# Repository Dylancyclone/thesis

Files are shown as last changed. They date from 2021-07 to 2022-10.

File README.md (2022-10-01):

# Building a Mobile Device that Leverages the Power of a Desktop Computer

## ASU Barrett Undergraduate Thesis 2022

## [READ THE PAPER HERE](./paper/small.pdf)

(Alternatively, [see it on asu.edu](https://keep.lib.asu.edu/items/165594))

Watch a timelapse of the paper here: https://youtu.be/VJ2HCxnmA_Y

## Abstract

With the recent focus of attention towards remote work and mobile computing, the possibility of taking a powerful workstation wherever needed is enticing.
However, even emerging laptops today struggle to compete with desktops in terms of cost, maintenance, and future upgrades.
The price point of a powerful laptop is considerably higher compared to an equally powerful desktop computer, and most laptops are manufactured in a way that makes upgrading parts of the machine difficult or impossible, forcing a complete purchase in the event of failure or a component needing an upgrade.

In the case where someone already owns a desktop computer and must be mobile, instead of needing to purchase a second device at full price, it may be possible to develop a low-cost computer that has just enough power to connect to the existing desktop and run all processing there, using the mobile device only as a user interface.

This thesis will explore the development of a custom PCB that utilizes a Raspberry Pi Computer Module 4, as well as the development of a fork of the Open Source project Moonlight to stream a host machine's screen to a remote client.
This implementation will be compared against other existing remote desktop solutions to analyze it's performance and quality.

## Information

This repository contains all the files and resources used to produce my Honors Thesis.

Folders are self-explanatory.

Final PCB board

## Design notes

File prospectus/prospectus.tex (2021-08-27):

\documentclass[11pt]{article}

%%%%% Preamble

\usepackage[margin=1in]{geometry} % Margin size
\usepackage{supertabular}
\usepackage[export]{adjustbox}

%% Title Information.

\title{Thesis Prospectus}
\author{Dylan Lathrum}
%\date{Jan 1 2000} % By default, LaTeX uses the current date
\date{} % Don't display date

%%%%% The Document

\begin{document}

\maketitle

\section*{Topic Overview}

Personal computers have greatly evolved and specialized over the past few decades to the point where the word ``computer" now refers to a whole family of devices that can be tailored to any particular use case.
A computer can be built to specifically fill a need or role ranging from the portability of a laptop to the raw power of a desktop.
For the longest time these roles have been completely seperate from one another, though in the past couple of years these two classes of computers have begun to share traits with each other.
While a desktop computer has been the standard for intensive computing and work since the beginning of computers, technology has progressed to the point where a laptop can provide comparable power in a much smaller footprint.
With the recent shift in attention towards remote work and mobile computing, the prospect of taking a workstation wherever needed is incredibly promising.
Though even the emerging laptops today struggle to compete with desktops in terms of cost, maintenance, and future upgrades.
The cost barrier to entry for powerful laptops is considerably higher compared to desktop computers, and most laptops are manufactured in a way that makes upgrading parts of the machine difficult or impossible, forcing a complete purchase in the event of failure or a component needs to be upgraded.

However, in the case where someone already owns a desktop computer and needs to be mobile, instead of needing to purchase a second device at full price, it may be possible to develop a low-cost computer that has just enough power to connect to the existing desktop and run all processing there, using the mobile device only as a user interface.
While the idea of a thin-client is not new, it's current usage in the real world has mostly been limited to computing clusters and server terminals due to their dependence on stable internet connections.
With the advent of small consumer electronics such as Raspberry Pis and their improvements in networking capabilities, the idea of a remote desktop has become a real possibility.

\section*{Research Plan}

I will begin my research by investigating the minimum cost barrier to create a computer using quality parts that can be used like a regular consumer product that has enough power to connect with a desktop computer at speeds sufficient for intense computing.
Once I can build a proof-of-concept using consumer parts, I will begin researching and developing a custom Printed Circuit Board (PCB) that will produce the same hardware output as a single board computer at a small footprint.
I believe creating a custom PCB will have benefits over a "DIY" solution as it will help prove the final product as something that could be used as a professional day-to-day replacement for a conventional powerful laptop.
Once parts have been selected and ordered, I will begin developing the hardware enclosure, wiring plans, and the software required to make the computer functional.
Throughout development, I will be benchmarking my product against existing technologies that support remote usage of computers, such as remote desktops.
I plan to investigate the specific technical specifications of the remote connection between my device and the host computer such as the latency, responsiveness, and image quality.
These statistics can be benchmarked by attempting to run intensive programs remotely, such as training an AI model, compiling code, running CAD software, rendering images/video, or developing video game software.
Due to the lack of existing all-in-one device for this purpose, I will research the advantages such a device has over comparable alternatives.
Once development has concluded, I will use the data collected to synthesize a comprehensive overview of the produced device and analyze its benefits over purchasing a high-powered laptop or using current alternatives.

\section*{Meetings}

I will meet with my thesis director on a regular basis every other week to discuss progress on the project and to answer any questions that arise from either party.
I will also meet with my other committee members to discuss my progress and ask for their advice and expertise.
Other meetings may be scheduled should new information or urgent questions arise.

\section*{Timeline}

\begin{tabular}{r|p{0.8\linewidth}}
	Date       & Task                                                                                 \\
	\hline
	June       & Begin research into hardware and software to be used in the project                  \\
	July       & Order parts and begin researching and designing enclosure for parts                  \\
	August 11  & Begin regular meetings with director, review schedule                                \\
	August     & Begin creating hardware and software for project                                     \\
	December   & Create final prototype for the project                                               \\
	January 10 & Start working on thesis paper, continue research and development on physical project \\
	Feburary   & Complete rough draft of thesis paper                                                 \\
	March      & Thesis Defense                                                                       \\
	April 15   & Submit Thesis                                                                        \\
\end{tabular}

\end{document}

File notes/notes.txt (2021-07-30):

USB C Breakout
https://www.sparkfun.com/products/15100

DSI vs HDMI
DSI Has extremely limited support (1 screen outside of the official implementation, locked at 800x480) and the format is closed so its hard for new ones to be made. DSI is more power efficient, and built in touch support, but lower resolution (480p). HDMI is a more generic standard, but small screens are expensive.
https://raspberrypi.stackexchange.com/questions/88075/hdmi-vs-dsi-pros-and-cons

Probably don't need an RTC for the pi if it syncs upon startup. Might also need a kernal patch that is built for rasbian that would have to be rewritten for arch
https://www.raspberrypi.org/forums/viewtopic.php?t=293632

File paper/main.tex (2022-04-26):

%%%%%%%%%%%%%%%%%%%%%%%%%%%%%%%%%%%%%%%%%
% Undergraduate Thesis for Barrett, The Honors College at Arizona State University
% For the degree of Software Engineering
% By Dylan Lathrum
%
% This document is based on a template by:
% Vel (vel@latextemplates.com)
% Steve Gunn (http://users.ecs.soton.ac.uk/srg/softwaretools/document/templates/)
% Sunil Patel (http://www.sunilpatel.co.uk/thesis-template/)
%
% Under the license:
% CC BY-NC-SA 3.0 (http://creativecommons.org/licenses/by-nc-sa/3.0/)
%
%%%%%%%%%%%%%%%%%%%%%%%%%%%%%%%%%%%%%%%%%

%----------------------------------------------------------------------------------------
%	PACKAGES AND OTHER DOCUMENT CONFIGURATIONS
%----------------------------------------------------------------------------------------
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
  commentstyle=\itshape\color{green!40!black},
  % identifierstyle=\color{blue},
  stringstyle=\color{orange},
}
\lstdefinestyle{customc}{
  language=C,
	morekeywords={uint32_t},
  belowcaptionskip=1\baselineskip,
  breaklines=true,
  frame=single,
  % xleftmargin=\parindent,
	numbers=left,
  showstringspaces=false,
  basicstyle=\footnotesize\ttfamily,
  keywordstyle=\bfseries\color{blue!80!black},
  commentstyle=\itshape\color{green!40!black},
  % identifierstyle=\color{blue},
  stringstyle=\color{orange},
}
\lstdefinestyle{plaintext}{
  belowcaptionskip=1\baselineskip,
  breaklines=true,
  frame=single,
	numbers=none,
  showstringspaces=false,
  basicstyle=\footnotesize\ttfamily,
}
\lstset{escapechar=@,style=customc}

\usepackage{pgfplots} % Required for the plots
\usepgfplotslibrary{statistics}
\pgfplotsset{compat=1.8}
% Fix mod function bug
% borrowed from <https://tex.stackexchange.com/a/145967/95441>
\pgfmathdeclarefunction{fpumod}{2}{%
		\pgfmathfloatdivide{#1}{#2}%
		\pgfmathfloatint{\pgfmathresult}%
		\pgfmathfloatmultiply{\pgfmathresult}{#2}%
		\pgfmathfloatsubtract{#1}{\pgfmathresult}%
		% replaced `0' by `5' to make it work for this problem
		\pgfmathfloatifapproxequalrel{\pgfmathresult}{#2}{\def\pgfmathresult{5}}{}%
}

\usepackage{chronosys} % Required for timelines

%----------------------------------------------------------------------------------------
%	MARGIN SETTINGS
%----------------------------------------------------------------------------------------

\geometry{
	paper=a4paper, % Change to letterpaper for US letter
	inner=2.5cm, % Inner margin
	outer=3.8cm, % Outer margin
	bindingoffset=.5cm, % Binding offset
	top=1.5cm, % Top margin
	bottom=1.5cm, % Bottom margin
	%showframe, % Uncomment to show how the type block is set on the page
}

%----------------------------------------------------------------------------------------
%	THESIS INFORMATION
%----------------------------------------------------------------------------------------

\thesistitle{Building a Mobile Device that Leverages the Power of a Desktop Computer} % Your thesis title, this is used in the title and abstract, print it elsewhere with \ttitle
\supervisor{Dr. Robert \textsc{Heinrichs}} % Your supervisor's name, this is used in the title page, print it elsewhere with \supname
\examiner{} % Your examiner's name, this is not currently used anywhere in the template, print it elsewhere with \examname
\degree{Software Engineering} % Your degree name, this is used in the title page and abstract, print it elsewhere with \degreename
\author{Dylan \textsc{Lathrum}} % Your name, this is used in the title page and abstract, print it elsewhere with \authorname
\addresses{} % Your address, this is not currently used anywhere in the template, print it elsewhere with \addressname

\subject{Software Engineering} % Your subject area, this is not currently used anywhere in the template, print it elsewhere with \subjectname
\keywords{} % Keywords for your thesis, this is not currently used anywhere in the template, print it elsewhere with \keywordnames
\university{\href{https://www.asu.edu/}{Arizona State University}} % Your university's name and URL, this is used in the title page and abstract, print it elsewhere with \univname
\department{\href{https://barretthonors.asu.edu/}{Barrett, The Honors College}} % Your department's name and URL, this is used in the title page and abstract, print it elsewhere with \deptname
% \group{} % Your research group's name and URL, this is used in the title page, print it elsewhere with \groupname
% \faculty{\href{http://faculty.university.com}{Faculty Name}} % Your faculty's name and URL, this is used in the title page and abstract, print it elsewhere with \facname

\AtBeginDocument{
\hypersetup{pdftitle=\ttitle} % Set the PDF's title to your title
\hypersetup{pdfauthor=\authorname} % Set the PDF's author to your name
\hypersetup{pdfkeywords=\keywordnames} % Set the PDF's keywords to your keywords
}

\begin{document}

\frontmatter % Use roman page numbering style (i, ii, iii, iv...) for the pre-content pages

\pagestyle{plain} % Default to the plain heading style until the thesis style is called for the body content

%----------------------------------------------------------------------------------------
%	TITLE PAGE
%----------------------------------------------------------------------------------------

\begin{titlepage}
	\begin{center}

		\vspace*{.06\textheight}
		{\scshape\LARGE \univname\par}\vspace{1.5cm} % University name
		\textsc{\Large Honors Thesis}\\[0.5cm] % Thesis type

		\HRule \\[0.4cm] % Horizontal line
		{\huge \bfseries \ttitle\par}\vspace{0.4cm} % Thesis title
		\HRule \\[1.5cm] % Horizontal line

		\begin{minipage}[t]{0.4\textwidth}
			\begin{flushleft} \large
				\emph{Author:}\\
				\href{https://www.linkedin.com/in/dylanlathrum/}{\authorname} % Author name - remove the \href bracket to remove the link
			\end{flushleft}
		\end{minipage}
		\begin{minipage}[t]{0.4\textwidth}
			\begin{flushright} \large
				\emph{Director:} \\
				\href{https://isearch.asu.edu/profile/3180015}{\supname} % Supervisor name - remove the \href bracket to remove the link  
			\end{flushright}
		\end{minipage}\\[.5cm]

		\begin{minipage}[t]{0.8\textwidth}
			\begin{flushright} \large
				\emph{Second Reader:}\\
				\href{https://isearch.asu.edu/profile/1232839/}{Ruben Acu\~{n}a}
			\end{flushright}
		\end{minipage}\\[.5cm]
		\begin{minipage}[t]{0.8\textwidth}
			\begin{flushright} \large
				\emph{Third Reader:} \\
				\href{https://isearch.asu.edu/profile/1625795}{Dr. Shawn Jordan}
			\end{flushright}
		\end{minipage}\\[3cm]

		\vfill

		\large \textit{A thesis submitted in fulfillment of the requirements\\ for the degree of \degreename}\\[0.3cm] % University requirement text
		\textit{for}\\[0.4cm]
		\deptname\\[2cm] % Research group name and department name

		\vfill

		{\large \today}\\[4cm] % Date
		%\includegraphics{Logo} % University/department logo - uncomment to place it

		\vfill
	\end{center}
\end{titlepage}

%----------------------------------------------------------------------------------------
%	DECLARATION PAGE
%----------------------------------------------------------------------------------------

\begin{declaration}
	\addchaptertocentry{\authorshipname} % Add the declaration to the table of contents
	\noindent I, \authorname, declare that this thesis titled, \enquote{\ttitle} and the work presented in it are my own. I confirm that:

	\begin{itemize}
		\item This work was done wholly or mainly while in candidature for a research degree at this University.
		\item Where any part of this thesis has previously been submitted for a degree or any other qualification at this University or any other institution, this has been clearly stated.
		\item Where I have consulted the published work of others, this is always clearly attributed.
		\item Where I have quoted from the work of others, the source is always given. With the exception of such quotations, this thesis is entirely my own work.
		\item I have acknowledged all main sources of help.
		\item Where the thesis is based on work done by myself jointly with others, I have made clear exactly what was done by others and what I have contributed myself.\\
	\end{itemize}

	\noindent Signed: Dylan Lathrum\\
	\rule[0.5em]{25em}{0.5pt} % This prints a line for the signature

	\noindent Date: \today\\
	\rule[0.5em]{25em}{0.5pt} % This prints a line to write the date
\end{declaration}

\cleardoublepage

%----------------------------------------------------------------------------------------
%	QUOTATION PAGE
%----------------------------------------------------------------------------------------

\vspace*{0.2\textheight}

\noindent\enquote{\itshape Premature optimization is the root of all evil.}\bigbreak

\hfill Sir Tony Hoare

%----------------------------------------------------------------------------------------
%	ABSTRACT PAGE
%----------------------------------------------------------------------------------------

\begin{abstract}
\addchaptertocentry{\abstractname} % Add the abstract to the table of contents

With the recent focus of attention towards remote work and mobile computing, the possibility of taking a powerful workstation wherever needed is enticing.
However, even emerging laptops today struggle to compete with desktops in terms of cost, maintenance, and future upgrades.
The price point of a powerful laptop is considerably higher compared to an equally powerful desktop computer, and most laptops are manufactured in a way that makes upgrading parts of the machine difficult or impossible, forcing a complete purchase in the event of failure or a component needing an upgrade.

In the case where someone already owns a desktop computer and must be mobile, instead of needing to purchase a second device at full price, it may be possible to develop a low-cost computer that has just enough power to connect to the existing desktop and run all processing there, using the mobile device only as a user interface.

This thesis will explore the development of a custom PCB that utilizes a Raspberry Pi Computer Module 4, as well as the development of a fork of the Open Source project Moonlight to stream a host machine's screen to a remote client.
This implementation will be compared against other existing remote desktop solutions to analyze it's performance and quality.

\end{abstract}

%----------------------------------------------------------------------------------------
%	ACKNOWLEDGEMENTS
%----------------------------------------------------------------------------------------

\begin{acknowledgements}
	\addchaptertocentry{\acknowledgementname} % Add the acknowledgements to the table of contents
	I would like to express my graditude to my thesis director, Dr. Robert Heinrichs, and to each of my committee members, Ruben Acu\~{n}a and Dr. Shawn Jordan, for their help in the development of this thesis.
	Without their guidance, I would not have been able to step so far outside of my comfort zone and learn about so many new topics to make this thesis happen.
	I would also like to thank my friends and family who were always there to bounce ideas off of and inevitably tell me when I was trying to fit too many words into a single section.
\end{acknowledgements}

%----------------------------------------------------------------------------------------
%	LIST OF CONTENTS/FIGURES/TABLES PAGES
%----------------------------------------------------------------------------------------

\tableofcontents % Prints the main table of contents

\listoffigures % Prints the list of figures

\listoftables % Prints the list of tables

%----------------------------------------------------------------------------------------
%	ABBREVIATIONS
%----------------------------------------------------------------------------------------

\begin{abbreviations}{ll} % Include a list of abbreviations (a table of two columns)
	\addchaptertocentry{\abbrevname} % Add the Abbreviations to the table of contents
	\negmedspace % Gets rid of weird extra space
	\textbf{BOM} & \textbf{B}ill \textbf{O}f \textbf{M}aterials\\
	\textbf{CM4} & Raspberry Pi \textbf{C}ompute \textbf{M}odule \textbf{4}\\
	\textbf{CPU} & \textbf{C}entral \textbf{P}rocessing \textbf{U}nit\\
	\textbf{CRD} & \textbf{C}hrome \textbf{R}emote \textbf{D}esktop\\
	\textbf{CSV} & \textbf{C}omma \textbf{S}eparated \textbf{V}alues\\
	\textbf{FFC} & \textbf{F}lat \textbf{F}lexible \textbf{C}able\\
	\textbf{FPS} & \textbf{F}rames \textbf{P}er \textbf{S}econd\\
	\textbf{GPU} & \textbf{G}raphics \textbf{P}rocessing \textbf{U}nit\\
	\textbf{IDE} & \textbf{I}ntegrated \textbf{D}evelopment \textbf{E}nvironment\\
	\textbf{PC} & \textbf{P}ersonal \textbf{C}omputer\\
	\textbf{PCB} & \textbf{P}rinted \textbf{C}ircuit \textbf{B}oard\\
	\textbf{RDP} & \textbf{R}emote \textbf{D}esktop \textbf{P}rotocol\\
	\textbf{RTC} & \textbf{R}eal \textbf{T}ime \textbf{C}lock\\
	\textbf{SBC} & \textbf{S}ingle \textbf{B}oard \textbf{C}omputer\\
	\textbf{SMD} & \textbf{S}urface \textbf{M}ounted \textbf{D}evice\\
	\textbf{SSH} & \textbf{S}ecure \textbf{Sh}ell (Protocol)\\
	\textbf{VNC} & \textbf{V}irtual \textbf{N}etwork \textbf{C}omputing\\

\end{abbreviations}

%----------------------------------------------------------------------------------------
%	PHYSICAL CONSTANTS/OTHER DEFINITIONS
%----------------------------------------------------------------------------------------

% \begin{constants}{lr@{${}={}$}l} % The list of physical constants is a three column table

% 	% The \SI{}{} command is provided by the siunitx package, see its documentation for instructions on how to use it

% 	Speed of Light & $c_{0}$ & \SI{2.99792458e8}{\meter\per\second} (exact)\\
% 	%Constant Name & $Symbol$ & $Constant Value$ with units\\

% \end{constants}

%----------------------------------------------------------------------------------------
%	SYMBOLS
%----------------------------------------------------------------------------------------

% \begin{symbols}{lll} % Include a list of Symbols (a three column table)

% 	$a$ & distance & \si{\meter} \\
% 	$P$ & power & \si{\watt} (\si{\joule\per\second}) \\
% 	%Symbol & Name & Unit \\

% 	\addlinespace % Gap to separate the Roman symbols from the Greek

% 	$\omega$ & angular frequency & \si{\radian} \\

% \end{symbols}

%----------------------------------------------------------------------------------------
%	DEDICATION
%----------------------------------------------------------------------------------------

\dedicatory{For my parents, and their endless support, encouragement, and guidance.}

%----------------------------------------------------------------------------------------
%	THESIS CONTENT - CHAPTERS
%----------------------------------------------------------------------------------------

\mainmatter % Begin numeric (1,2,3...) page numbering

\pagestyle{thesis} % Return the page headers back to the "thesis" style

% Include the chapters of the thesis as separate files from the Chapters folder
% Uncomment the lines as you write the chapters

\include{Chapters/Introduction}
\include{Chapters/Background}
\include{Chapters/StateOfTheArt}
\include{Chapters/Hardware}
\include{Chapters/Software}
\include{Chapters/Evaluation}
\include{Chapters/Conclusion}

%----------------------------------------------------------------------------------------
%	THESIS CONTENT - APPENDICES
%----------------------------------------------------------------------------------------

\appendix % Cue to tell LaTeX that the following "chapters" are Appendices

% Include the appendices of the thesis as separate files from the Appendices folder
% Uncomment the lines as you write the Appendices

\include{Appendices/AppendixA}
\include{Appendices/AppendixB}
\include{Appendices/AppendixC}

%----------------------------------------------------------------------------------------
%	BIBLIOGRAPHY
%----------------------------------------------------------------------------------------

\printbibliography[heading=bibintoc]

%----------------------------------------------------------------------------------------

\end{document}

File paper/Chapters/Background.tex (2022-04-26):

\chapter{Background}

\label{Chapter2}

Computers have a long history of being built to serve a particular purpose, often compromising some aspects of the system to bolster others.
Chapter \ref{sec:SpecializationOfComputers} discusses the history of how computers were built for a particular function, and how the advancement of technology has brought the \enquote{Personal Computer} seen know today.
Chapter \ref{subsec:PowerOfTheDesktop} discusses the benefits of a desktop computer, Chapter \ref{subsec:ConvenienceOfTheLaptop} discusses the benefits and drawbacks of a laptop computer, and Chapter \ref{subsec:RiseOfTheGamingLaptop} discusses the rise of the gaming laptop and the closing gap between power and portability at the cost of increased price.
Chapter \ref{sec:ThinClients} briefly discusses thin clients, a corporate solution for remote access to a computer.
Chapter \ref{sec:ApplicationToModernDay} introduces current world wide context that has an impact on the computing world and the need for power and portability.

\section{Specialization of Computers}\label{sec:SpecializationOfComputers}

In the age of punch cards and monolithic computers the size of entire rooms, it was expected of a computer to only be capable of serving a single function.
Before the technology could be miniaturized, every single computer had to be specialized for the job at hand.
As time passed and technology progressed, a single computer could be produced that served multiple functions as well as be adaptable programmable to handle new tasks that were not considered when the machine was originally built.
This gave rise to what was known as \enquote{Autonomic Computing}, a system of characteristics that are built into a computer to help it self-manage it's resources and adapt to it's administrator's requirements without the need to be redesigned for it's new purpose \cite{AutonomicComputing}.
Autonomic Computing was designed to combat the exponential complexity crisis that came from the widespread availability of computers in different disciplines, since now anyone who could afford a computer could program it for any purpose.
As new use cases were found for computers in day-to-day life and new technologies were being developed to interface with the world around us, the need for componentization became ever more apparent.
Researchers at IBM knew that the best way to address the looming problem of runaway complexity in computers was to develop a way for the computers to automatically interface with any new components that are installed, and to configure itself to only use what is necessary for the job at hand \cite{AutonomicComputing}.
This allowed hardware and software developers to focus on building their products to work with a common standard rather than having to manually integrate their products with every computer.

Once the idea of modularity began to take hold in the computer industry, attention was turned once again towards specializing individual computers.
Now that a computer's physical footprint can be minified, and peripheral components can be added and removed without a complete reengineering of the device, a single computer can be optimized to handle a single task without the overhead cost of building a monolithic computer \cite{Burbeck2007ComplexityAT}.
Now a computer can be specialized to serve a particular purpose or set of purposes while keeping development time comparatively short.
The world has seen this realized through numerous applications such as cell phones, designed to be user-friendly portable devices, computing clusters, built for high-performance computing, or even internet routers, which are built to be a plug-and-play solution for a problem posed to users of all levels of familiarity with computers.
Without this idea of Autonomic Computing, each of these devices would have to be reengineered from the ground up every time a new use case was developed.

This leads into the specialization of home computers in from the perspective of a consumer.
It used to be that a \enquote{home computer} was a device that was bought off the shelf as-is and served it's purpose.
Now a home computer can be a desktop PC that can be upgraded with time and seldom moves from it's place, or it could be a laptop that is portable and easy to cary around.
These specializations bring more choices for the consumer to pick a computer that best suits their needs, but they often come with compromises.

\subsection{Power of the Desktop}\label{subsec:PowerOfTheDesktop}

The classical manifestation of a personal computer is the desktop computer.
Known for it's componentization, user repairability, and direct connections to power and the network, desktop computers are the best option for a user looking for a workhorse system.
Pieces of the computer could be bought separately, and single parts could be upgraded or replaced by anyone will a little hardware knowledge.
Even though they aren't very portable, desktop computers allow consumers to access greater processor power for a lower cost compared to portable devices \cite{Meyer20145RS}.
Due to this, a desktop PC is often seen at one's home or place of work hardwired to the wall where it remains unmoving unless it needs upgrading, cleaning, or repairs.
Adding on the fact the desktop is modular, it can be easily customized to fit any user's needs, as well as enable particular parts to be replaced or upgraded without needing to rebuild the entire system.

While desktops were the staple of personal computers for decades, advancing technology and the rising need of portability and flexibility has led to the growth of laptops.

\subsection{Convenience of the Laptop}\label{subsec:ConvenienceOfTheLaptop}

As the world moved towards a more mobile lifestyle, the laptop shifted from being a luxury to being a necessity.
People began to need computing power on the go, whether it be for working remotely, attending classes and following along, or simply needing more power than their phone can offer.
Companies began to take note too and started building applications to work fully within a web browser, such as Google's implementation of Google Docs, allowing users to edit documents on the go without having to install software like Microsoft Word directly to their computers.
This shift towards mobility provided the general public the ability to be more flexible with how they used computers, no longer requiring them to dedicating a spot in their house to be taken up by a desktop computer.

Reducing the barrier to entry for computers, such as the knowledge to buy the computer the best fits their needs and the restrictions that come with setting up and keeping a desktop, led to the widespread adoption of laptops.
In fact, by 2021, laptops accounted for 80\% of total computer sales \cite{idc_2021}.
For most consumers, the laptop is all they need; it may not have the raw power of a desktop, but it handles everything they need it to do.
The biggest limiting factor then becomes technology, with manufacturers constantly trying to minimize existing desktop technology into the footprint of a laptop while keeping energy efficiency high enough to be feasible in a mobile device.

\subsection{Rise of the Gaming Laptop}\label{subsec:RiseOfTheGamingLaptop}

All computer products are a balance, it simply isn't possible to have the perfect combination of portable, powerful, serviceable, and cheap.
While desktops focus on power and serviceability, laptops often focus portability at the expense of other attributes.
As mobility becomes ever more important, gaming laptops have become more popular to bring power to the portable form factor.
This understandably comes with a cost, with the literal cost of a gaming laptop being the most obvious compromise.
The componentization of such a laptop also often takes a hit with parts being directly soldered to the motherboard, reducing a user's options for repairs or upgrades.
It is more expensive, and often less user-serviceable, to buy a gaming laptop that has the same performance of a desktop computer -- but given that it is an all-in-one device, it's portability gives it a niche that a desktop cannot hope to rival.
The compromise presented by a gaming laptop helps close the gap between power and portability, but it still falls short of being an all around good solution.

\section{Thin Clients}\label{sec:ThinClients}

\begin{wrapfigure}{r}{0.375\textwidth}
  \centering
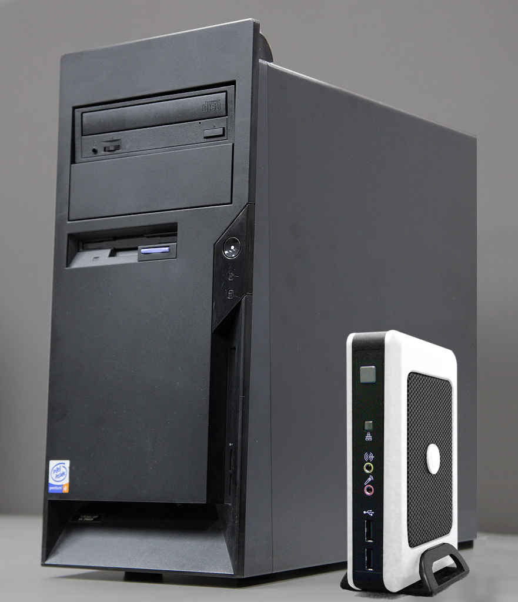
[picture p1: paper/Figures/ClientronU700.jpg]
  
  \caption[Thin Client]{A thin client next to a traditional desktop computer \cite{ImageThinClient}.}
  \label{fig:ThinClient}
\end{wrapfigure}

On the corporate side of computing, the solution for portability has been the thin client.
Rather than integrating the power of a desktop to a portable machine, a thin client will connect to a powerful server and provide a thin interface to the user.
This allows the user to utilize the power of the host machine from a cheap computer that usually doesn't have enough power to be used as a standalone computer.
Because of this, the thin client cannot be used as a standalone computer, but it's low cost and portability make it a great solution for a corporate user.
While these clients work well for simple interfacing tasks such as data entry or system management, they are not designed to be used for complex tasks that require quick response times or graphical fidelity.

\section{Application to Modern Day}\label{sec:ApplicationToModernDay}

In 2022, the world is currently going through some chaotic times that demand flexibility and adaptability like it hasn't faced before.
From the COVID-19 pandemic to massive chip shortages and supply line disruptions, people are now more than ever looking for a way to be flexible in their work and personal lives now and in the future.
The COVID-19 pandemic has forced people to be able to operate remotely, whether that be for work, school, or communicating with friends and family \cite{levanon_2020}.
Many office workers used to working on a desktop computer onsite are now needed to work from home, or classes usually taught in person are now held remotely \cite{ASU_covid_19}.
This shift to remote operation has fueled the need for mobile computers, many of which need to be powerful enough to handle the workload of a desktop computer from anywhere in the world.
The global chip shortage is also causing issues for the purchase of new devices \cite{chipshortage_jpmorgan}.
Parts which are usually readily available for purchase are out of stock with months of delay on back order.
Resellers are taking advantage of the situation by hiking prices to two or three times the original listing price, and it's become harder than ever to build a new PC \cite{tamarov_2021}.
All of these factors combined lead to a very difficult situation for anyone looking to purchase a new computer or parts for their existing computer.

\section{Summary}\label{sec:BackgroundSummary}

Even after decades of technological innovation, every consumer computer is still a compromise between power, portability, and price.
The desktop computer has been the best option for high power machines with a lower overall cost, but lacks the portability that has become a necessity in modern times.
Laptops and gaming laptops have risen in popularity for their portability and flexibility, but their power comes at a cost premium that makes it inaccessible for many consumers.
While thin clients are a viable solution for the corporate world the power is provided by a dedicated server and end-user costs are kept at a minimum, their lack in portability highlights a gap in the currently available technology.
There currently isn't a solution for a cheap an portable device that can leverage the power of an existing computer.
Specifically, it doesn't make sense to build or purchase a powerful PC for use at home and another power laptop to handle working on the go.

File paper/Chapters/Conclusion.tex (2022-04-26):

\chapter{Conclusion}

\label{Chapter7}

\section{Summary}\label{sec:ConclusionSummary}

This thesis has proved that it is possible to produce a hardware and software solution that is capable of leveraging the power of a desktop computer remotely without sacrificing the user's experience.
It improves upon existing solutions by continuing to offer a performant and high-quality stream of the host's screen to the user even as the host is running highly demanding applications.
Each of the questions posed in Section \ref{sec:ResearchQuestions} can be answered individually.

\begin{enumerate}
  \setcounter{enumi}{0} % Start the enumeration at X+1
  \item \textbf{Hardware Feasibility:} \emph{What hardware is needed in order to power a mobile device capable of acting as a client?}
\end{enumerate}

\noindent
This thesis project is able to run on embedded Single Board Computers and hardware available for purchase today.
While this project built a custom PCB for the Raspberry Pi Compute Module 4 (Discussed in section \ref{sec:ChoosingParts}), the software could also run on consumer-grade main-line Raspberry Pi models as well.

\begin{enumerate}
  \setcounter{enumi}{1} % Start the enumeration at X+1
  \item \textbf{Hardware Cost:} \emph{Is it feasible to construct such as device at a lower or comparable cost to existing solutions?}
\end{enumerate}

\noindent
Yes, the total cost for a single hardware unit, including the board and all its components, totalled in under \$150, and could even be produced for less (Discussed in Section \ref{subsec:HardwareCost}).
This cost is considerably cheaper than buying a new laptop device, and often cheaper than buying a used laptop with comparable power.

\begin{enumerate}
  \setcounter{enumi}{2} % Start the enumeration at X+1
  \item \textbf{Communication Protocol:} \emph{Does a protocol exist that is efficient enough to stream demanding applications to a client?}
\end{enumerate}

\noindent
Yes, Nvidia's GameStream protocol proved itself to be capable of streaming highly demanding applications to a client device without any loss of quality or performance (Discussed in Section \ref{sec:EvaluationSummary}).
Even though it's original purpose and namesake is to stream video games, the high demands of such a use case have made it applicable to much more than just that.
While Microsoft's Remote Desktop Protocol proved to be powerful enough to stream demanding applications to a client device, it's limitations and closed-source nature prevent it from being the viable solution for certain use cases (Discussed in \ref{subsec:RemoteDesktopProtocol}).

\begin{enumerate}
  \setcounter{enumi}{3} % Start the enumeration at X+1
  \item \textbf{Software Application:} \emph{Can a software solution be built to utilize this protocol in a manner that performant enough?}
\end{enumerate}

\noindent
Yes, the solution produced in this thesis is built upon the open source project Moonlight, which utilizes the GameStream protocol, to provide a software application that is capable of streaming demanding applications to a client device while remaining performant enough to provide a positive user experience (Discussed in Section \ref{sec:EvaluationSummary}).

\section{Limitations}\label{sec:ConclusionLimitations}

While this thesis was constructed with the utmost attentiveness with regards to the time and resources available, there are still limitations in what could be accomplished.
The largest limitation is the lack of testing in alternative environments.
All of the testing performed in Chapter \ref{Chapter6} was performed in an ideal network environment, where there was minimal network latency between the host and client machines due to them both being connected to the same network by ethernet.
While this is a good indicator of the best possible performance, it is not very indicative of the performance that could be expected in a real-world environment.
More testing should be done where the host and client machines are located on different networks akin to the use case described in Section \ref{sec:ApplicationToModernDay}.

Secondly, due to the ongoing chip shortage and the lack of experience in developing PCB boards, it is very likely that there are better ways to develop the PCB board for this project.
While the board was able to meet the requirements for this project, there we're many instances (some described in table \ref{tab:SelectedComponents}) where alternative parts had to be chosen and designed around because the first-choice was out of stock.
It is very possible that the board could have been constructed quicker and at a cheaper price if more parts were available for purchase.

\section{Future Research}\label{sec:ConclusionFutureResearch}

Should this project be continued in the future, there are multiple ways that additional time and resources could further improve this project.
The first improvement to make is to fix the issue with USB data described in section \ref{subsec:Manufacturing3}.
This is the only flaw in the hardware preventing it from being considered a completed product.
Similar to the previous section, if more time were available, more testing could be done in various environments to identify any weaknesses in the software that may have gone unnoticed.

Another aspect of the project worth testing in more detail is the performance of the hardware produced in Chapter \ref{Chapter4} compared to the hardware performance of the development board that is sold with the CM4 (Section \ref{sec:ChoosingParts}).
The ideal outcome is that the two boards provide the same performance, meaning that there is no unneeded overhead introduced by the board produced in this thesis that should be fixed.
In the event that there is slowdown somewhere within the custom board, the specific problem should be identified and redesigned to provide optimal performance.

After experimenting with streaming over different networks and testing the project under different conditions, it would be beneficial to look at polishing the hardware of the project into a self-contained product.
As it stands, it is currently a PCB with peripherals attached that make it cumbersome to carry around.
The groundwork for this has already been laid out in Section \ref{subsec:DesigningHDMI}, with FFC connectors established for one HDMI and one USB port for connection to an embedded screen, and with the footprint of the final PCB and battery fitting within the footprint of the chosen screen.
All that is left is to build an enclosure to house the final product.

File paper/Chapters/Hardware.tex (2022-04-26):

\chapter{Developing the Hardware}

\label{Chapter4}

As discussed in Chapter \ref{Chapter2}, there currently is no commercial solution for a cheap, portable device that can leverage the power of a remote computer; hence, this thesis will investigate the development of such a solution.
There are a lot of factors that go into designing and building an electrical system that fits the needs for this project.
This process begins by outlining the requirements in Section \ref{sec:HardwareRequirements}, followed by describing the process and methodology of choosing parts in Section \ref{sec:ChoosingParts}.
Then, the feasibility of prototyping such as system is discussed in Section \ref{sec:Prototyping}, and finally the system is designed and manufactured in Sections \ref{sec:DesigningThePCB} and \ref{sec:ManufacturingThePCB} respectively.

The entirety of the hardware schematics and designs developed for this project are available on GitHub at: \url{https://github.com/Dylancyclone/thesis/kicad}.

\section{Requirements}\label{sec:HardwareRequirements}

This section will explain the different constraints taken into account while developing the hardware portion of this thesis.
First, the hardware must be performant enough to provide a positive user experience (\ref{subsec:HardwarePerformance}), and secondly the product must be cheap enough to justify it over similar alternatives (\ref{subsec:HardwareCost}).

Since no specific studies regarding possible users of the system were conducted, the requirements laid out in this section are based on the author's own requirements and preferences.
The requirements are constructed with the target user being someone who already has a working desktop computer and wishes to leverage it's power remotely without sacrificing the user experience.

\subsection{Performance}\label{subsec:HardwarePerformance}

When considering how much power needs to be incorporated in to the miniature computer, it is important to consider a number of factors, such as: having enough power to stream audio and video over the internet, not consuming too much power so as to require an expensive battery, have a fast enough connection to the internet to deliver data with the least possible latency, and having a reasonable footprint to be used as a mobile device.

Immediately, the device must be capable of decoding and rendering video that is streamed over the internet.
Such video processing is a relatively expensive process that cannot easily be done with something such as a micro controller or even a single core CPU seen on Single Board Computers (SBC) such as the Raspberry Pi Zero due to the lack of working memory and processing power \cite{picockpit_2021}.
Though at the same time, it is important to not simply build a powerful system akin to a laptop that will consume more power.
It makes no sense to built a powerful mini-computer when all it will ever be used to is to connect to another computer, and the added power draw would require a larger battery in order to stay operational for decent periods of time.
Instead it should be cut down and distilled into something that can do it's job as efficiently as possible.

The second major performance requirement of the hardware is the ability to stream this data over the internet as quickly as possible.
Because all of the data being sent to the device is live information from the host machine, the video and audio streams cannot simply be buffered in advance and played when it's ready like a recorded video.
Instead, the data must be displayed as it is received so that the user can have a smooth experience without having to wait for their keystrokes or mouse movements to be registered.
While Wi-Fi is growing ever quicker and more reliable, and should absolutely be included as a way to connected to the internet, the best way to ensure a stable and speedy connection is to use an Ethernet Cable.
This will help the device work on a consistent connection when used at a desk, while also providing a way to connect while on-the-go.

This leads to the desire for a portable design that can be used both in a conducive environnement such as a desk or while mobile.
The hardware should have the ability to be powered by a chord plugging into the device, or by an internal battery.
This alone presents a number of difficult concerns which will be addressed in Section \ref{sec:Prototyping}.
Such a requirement leads to a clear benefit of integrating crucial computers such as a battery and a screen into the hardware design, while leaving as many ports open such as ethernet and USB for the user to take advantage of.

\subsection{Cost}\label{subsec:HardwareCost}

Because this project consists of both a Hardware and Software component to make up a complete product, there must be reason for both to be developed.
While the software has the benefit of being the foundation for the connection between host and client machines, there are already hardware solutions that would theoretically be able to run such software.
Since the goal of this project is to save money by not needing to purchase an expensive mobile device to connect to a powerful desktop computer, there must be benefit in the hardware to warrant it's existence over repurposing something like an old laptop.
The most obvious metric of this is the actual cost of the hardware.
If the hardware can be produced at a high enough quality at a low enough cost to bring value over just a software solution, then it should be considered moving forward.
Otherwise it may prove that the development of the software should focus on compatibility so the hardware can be provided by the end user.

Generally speaking, the goal for the hardware of this project is to cost approximately \$100-\$200 to produce a single unit.
This comes with the understanding that hardware production in bulk often costs significantly less than assembling a single product.
The reasoning for this cost comes down to feasibility: the price of the final product should be less than what it would cost to purchase or refurbish an existing computer to do the job of this project.
Otherwise, as stated before, the software of this project may prove more valuable than the hardware as long as compatibility is kept in the forefront of development.

\section{Choosing Parts}\label{sec:ChoosingParts}

When starting to choose parts for the hardware, there are many difficult questions to face.
First and foremost, the hardware had to be built with the time and resources available for this project.
Specifically, building a Single Board Computer from scratch would be completely infeasible, but the goal was also not to simply purchase an off the shelf SBC that was not tailored to the task at hand such as a traditional Raspberry Pi.
Instead, a better suited solution would be to utilize a \emph{Raspberry Pi Compute Module 4 (CM4)} which has \enquote{The power of Raspberry Pi 4 in a compact form factor for deeply embedded applications} \cite{rpi_cm4}.
Preliminary investigations showed that the CM4 is a promising candidate for the system and hence was chosen to be the starting point for the development of this project.
It's most important characteristic to keep in mind is due to it's small size and deeply embedded nature, the only way to communicate with the Compute Module is through two tiny mezzanine connectors as shown in Figure \ref{fig:rpi_cm4_mezzanine}.
With no other pin outs for anything such as power, HDMI, or USB, the rest of the hardware must be built on a custom Printed Circuit Board (PCB) that tailors the CM4 for this thesis.

\begin{figure}[h]
  \centering
  \begin{minipage}{0.45\textwidth}
    \centering
    
    \captionsetup{width=.75\linewidth}
    \caption[Raspberry Pi Compute Module 4]{Raspberry Pi Compute Module 4, sizing\newline55 x 40mm}
    \label{fig:rpi_cm4}
  \end{minipage}\hfill
  \begin{minipage}{0.45\textwidth}
    \centering
    
    \captionsetup{width=.75\linewidth}
    \caption[Raspberry Pi Compute Module 4 Pin out]{Close-up of the pin out, with a 0.04mm pitch between pins}
    \label{fig:rpi_cm4_mezzanine}
  \end{minipage}
\end{figure}

This PCB would have to be designed so that the CM4 could be plugged into the board using the mezzanine connectors and rely on it for all inputs and outputs.
This, however, is only the beginning of what is required to develop the product.
Since the project would not use an off the shelf SBC like a regular Raspberry PI, the project would require only designing the PCB but also picking out all the components that would go onto the PCB, such as the USB ports themselves, the USB driver chip, and related components needed for operation.
Because the CM4 is designed to be as low-powered and compact as possible, some features that would usually be expected of such a device, like the USB ports, are disabled by default and must instead be built by the board designer.
While this helps greatly by removing extraneous components and features that aren't needed for this project, it also provides a great opportunity to learn exactly what parts are being used in the hardware.

Thought must also be given to the peripherals that will be included in the design.
Most importantly, if a screen is going to be included in the design, what kind of screen will be used?
For projects of this scale, the usual candidates for a relatively performant screen are HDMI screens or DSI screens.
While HDMI screens are much more common and recognizable, DSI screens are a new development that promises 60Hz performance in low cost and low power applications such as embedded systems.
However, when looking into existing DSI screens, there are a couple of issues that prevent it from being the best choice for this project.
Even though DSI screens are more power efficient and have built in touch support, it is a closed format which greatly restricts manufactures from producing their own screens \cite{dsi_vs_hdmi}.
Due to this, there is only one screen available for purchase outside of the official implementation, and both have a lower resolution that what is possible with HDMI screens of the same size.
So even though HDMI screens are more expensive at this size, they are a more reliable choice compared to the still-developing DSI standard.

Another potential feature to consider is whether to integrate a Real Time Clock (RTC) into the design.
An RTC is a component commonly found within laptop and desktop computers that is used to keep track of time even though the computer is powered off.
This is done with a small button battery powering an RTC chip integrated into the motherboard to keep the system's clock in sync with the real world.
While this is almost never necessary in embedded systems, it is worth considering for this project because of it's use as a mobile computer.
However, when considering the primary use case of connecting to another computer over the internet, and the potential of needing a linux kernel patch in order to add support for the RTC \cite{rtc_kernelpatch}, it would be much simpler to tell the operating system to simply resync it's clock with an internet clock every time it connects to a network.

An invaluable resource while designing the PCB was the Official I/O board for the CM4 \cite{rpi_cm4_io}.
Though the PCB board would still have to be custom built and components would need to be replaced due to the current ongoing chip shortage, it provides a great foundation instead of starting from scratch.
Another massive benefit from working within the Raspberry Pi Ecosystem is their incredible documentation and community surrounding the boards \cite{rpi_cm4_docs}.
Around the time this project was being started, the CM4 was just beginning to get into the hands of makers and developers, and only a couple custom boards had actually been made by anyone other than Raspberry Pi themselves.
Even though this leaves the community with less of a bulk of knowledge to work with, it has provided a sort of comradery with everyone helping each other learn the new Compute Module together.
Members of the CM4 engineering team would even assist those on the forums to help them pick parts and design their own boards \cite{cm4_datasheet_problem,rtc_kernelpatch}.

Following the example put forward by the existing boards, PCB parts were chosen to be integrated into the circuit as safely as possible.
Thankfully due to most parts following international standards, many parts were chosen simply because they followed the same standard as the CM4 (such as USB 2.0, or \emph{1PORT 1000 BASE-T} Ethernet) and were in stock.
What follows is a table of some components that were used in the custom PCB that may differ from those used by the CM4's official board, and the reason for their selection.
A full Bill of Materials (BOM) can be found in Appendix \ref{AppendixB}.

\renewcommand*{\arraystretch}{1.5} % inner table padding
\begin{longtable}{|>{\raggedright\arraybackslash}p{0.2\linewidth}|>{\raggedright\arraybackslash}p{0.33\linewidth}|>{\raggedright\arraybackslash}p{0.46\linewidth}|}
  \hline
  \bfseries Purpose & \bfseries Manufacturer's Number &\bfseries Reason \\% Columns
  \hline
  USB-C Power in & \emph{USB4125-GF-A} by \enquote{GCT} & Most projects of this scale are powered by micro usb, but with USB-C gaining popularity, this component was picked for its low price and exclusive ability to transfer power without transfering data. \\
  \hline
  Ethernet Port & \emph{ARJM11D7-502-AB-EW2} by \enquote{Abracon LLC} & One of the few in-stock ethernet ports that supports \emph{1000 BASE-T} usage. The CM4 recommends the \emph{MagJack-A70-112-331N126} produced by \enquote{LINK-PP}, but that part is out of stock for at least another year as of writing. \\
  \hline
  USB Port & \emph{SS-52100-001} by \enquote{Stewart Connector} & Single flat port that supports USB 2.0. \\
  \hline
  HDMI Port & \emph{SS-53000-001} by \enquote{Stewart Connector} & Single flat port that supports HDMI 1.4. \\
  \hline
  Flat Flexible Cable Connector & \emph{FFC3B07-20-T} by \enquote{GCT} & A generic Flat Flexible Cable port that can be connected to anything. In this case, one is connected to the built-in screen's HDMI port, and another is connected to the screen's touch/power USB port. \\
  \hline
  2-Pin Through Hole Header & \emph{PREC002SAAN-RC} by \enquote{Sullins Connector Solutions} & A generic 2-pin header than can be used to bypass the power circuit as will be discussed in Section \ref{sec:Prototyping}. \\
  \hline
  HDMI Power Regulator & \emph{RT9742ENGJ5} by \enquote{Richtek USA Inc.} & The CM4 recommends the \emph{RT9742SNGV} from the same manufacturer, but it is out of stock. This part has slight differences in functionality that require adjustments from the official I/O board design. \\
  \hline
  SD-Card Power Regulator & \emph{RT9742VGJ5} by \enquote{Richtek USA Inc.} & The CM4 recommends the \emph{RT9742GGJ5F} from the same manufacturer, but it is out of stock. This part has slight differences in functionality that require adjustments from the official I/O board design. \\
  \hline
  Battery Voltage Regulator and Boost Converter & \emph{TPS61090RSAR} by \enquote{Texas Instruments} & Used to balance power usage from the USB-C port or the attached battery, favoring the external power when available. \\
  \hline
  Li-Po Battery Charge Management Controller & \emph{MCP73871-2CCI\_ML} by \enquote{Microchip Technology} & Used to charge the attached battery when attached to external power through the USB-C port. \\
  \hline
  4 Port USB Hub Controller & \emph{USB2504A-JT} by \enquote{Microchip Technology} & Used to control the four USB 2.0 ports and send the data to the CM4. The CM4 recommends the \emph{USB2514B-I/M2} by the same manufacturer, however it and all the parts in it's family are out of stock with at least a 52-week back order. Out of all the components, this has the highest potential to be problematic.\\
  \hline
  \caption[Selected PCB Components]{A non-exhaustive list of components that were chosen for this project.}
  \label{tab:SelectedComponents}
\end{longtable}

\section{Prototyping}\label{sec:Prototyping}

Whenever working with electrical projects such as this, it is always a good idea to build up prototypes before committing to a final design that will be produced at the highest quality.
Usually breadboards and some breakout boards for Surface Mounted Devices (SMD) are a great way to develop a circuit without creating a full PCB; but due to the nature of the complex microchips required for this project as well as the dependence on the CM4's tiny mezzanine connectors, building a prototype using a breadboard is impractical given the time and resources available.
\begin{wrapfigure}{o}{0.37\textwidth}
  \centering
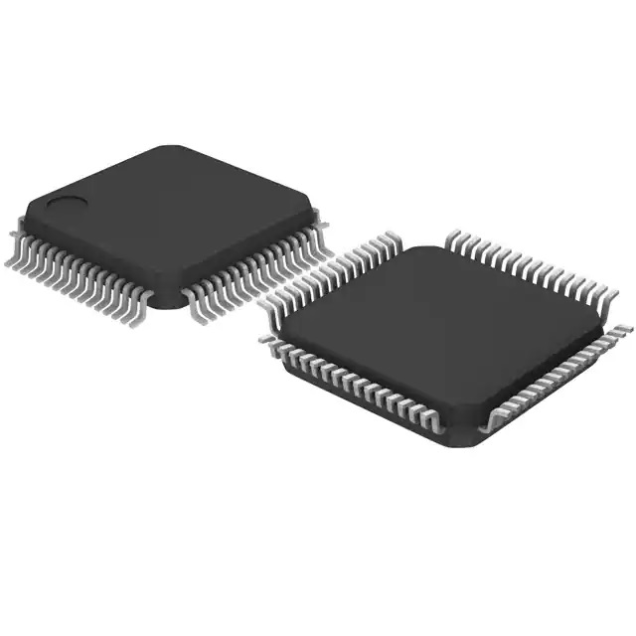
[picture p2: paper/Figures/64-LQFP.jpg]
  
  \caption[USB Controller]{The USB controller, with 0.5mm between pins}
  \label{fig:USBController}
\end{wrapfigure}
For example, the USB controller chip only has 0.5mm of space between each of it's 64 pins (Figure \ref{fig:USBController}), which would require a breakout board at least 7 times larger than the chip so that each each pin can be easily accessed by hand.
Not to mention the difficulty in wiring up that many pins along with the other related components which would need their own breakout boards either purchased or custom-designed.

Instead, the first board was built out in a piecewise fashion, allowing each section of the board a way to fail without interrupting the rest of the board.
This allows each function of the board to be tested individually and in isolation so that changes could be made incrementally without needing to worry about their integration with the rest of the board.
For example, in order to build a system that would allow the board to be powered via USB or an internal battery, as well as charge the battery simultaneously, a complex circuit would have to be built that managed Lithium Polymer (LiPo) batteries which could cause fires if mishandled.
Since power is obviously a critical component of the board, A secondary way of feeding power directly the board was built to bypass all that circuitry in case it fails.
In doing so, the board can still be powered and it's other features can be tested while a fix for that portion of the circuitry is developed for the next iteration.

\begin{figure}[h]
  \centering
  %Height instead of width because the image is rotated
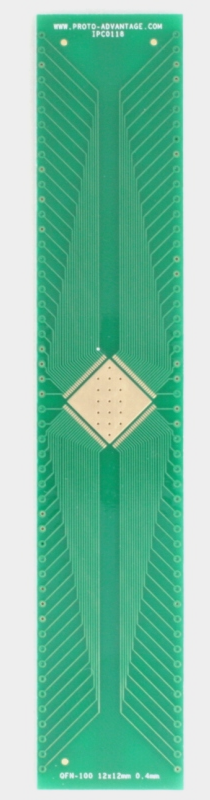
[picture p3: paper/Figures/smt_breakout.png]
  
  \captionsetup{width=.8\linewidth}
  \caption[SMD Breakout Board]{A breakout board similar to what would be needed for the USB controller used on the custom PCB}
  \label{fig:smt_breakout}
\end{figure}

\section{Designing the Printed Circuit Board}\label{sec:DesigningThePCB}

Because of the lack of prototyping options discussed in Section \ref{sec:Prototyping}, and ultimate decision to build the board in a way that could safely fail in any way, it became clear that multiple versions of the project were going to need to be designed and produced.
Since the time and budget for this project was limited, the amount of revisioning was minimized by running the circuit by electrical engineering students and professors to catch any potential flaws before the board was manufactured.

\subsection{Power}\label{subsec:DesigningPower}

\begin{figure}[t]
  \centering
  \begin{subfigure}{.5\textwidth}
    \centering
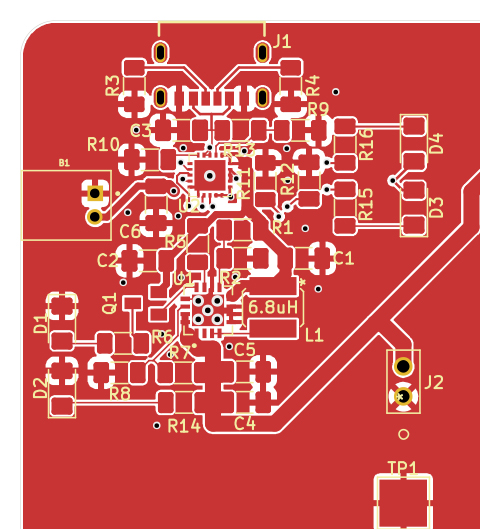
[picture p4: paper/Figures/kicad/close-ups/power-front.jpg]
    
  \end{subfigure}%
  \begin{subfigure}{.5\textwidth}
    \centering
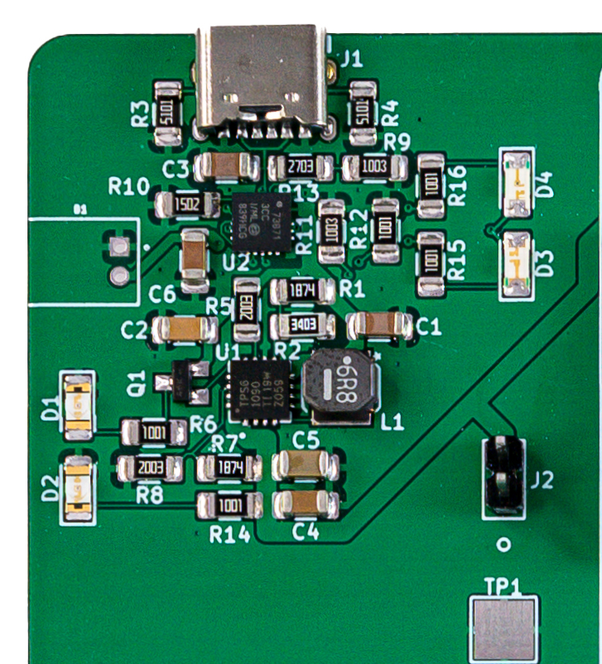
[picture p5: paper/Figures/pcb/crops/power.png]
    
  \end{subfigure}
  \caption[PCB Power Circuit]{The front side of the PCB's power circuit}
  \label{fig:PowerCircuit}
\end{figure}

\begin{figure}[b!]
  \centering
  
  \caption[Power Schematic]{Schematic layout for the power circuit, including battery management. Expanded in Appendix \ref{app:pcb_schematic_battery}}
  \label{fig:pcb_schematic_battery}
\end{figure}

Development started with arguably the most important part of the board: the power supply (schematic in Figure \ref{fig:pcb_schematic_battery}).
If the CM4 could not receive power, none of the project would work.
A feature of modern devices that has become ubiquitous as much as it has been taken for granted is the ability to charge a battery at the same time it is in use by the device.
This enables the device to be used portably until the battery runs out and then charge the device without needing to stop using it before moving again.
Though it proves to be slightly more complicated than simply connecting the two power supplies.
As seen in Figure \ref{fig:PowerCircuit}, the source of external power, the USB-C port labeled \emph{J1}, has to travel through two integrated circuits before reaching the CM4 through the trace on the right side.
The first chip, \emph{U2}, detailed in Table \ref{tab:SelectedComponents} as \emph{MCP73871-2CCI\_ML}, is used to charge the internal battery attached to the left side of the board through the connector labeled \emph{B1}.
The second chip, \emph{U1}, also detailed in Table \ref{tab:SelectedComponents} as \emph{TPS61090RSAR}, is used to balance the power draw from the USB-C port or the attached battery, favoring the external power when the device is plugged in.
Thankfully, due to the sensitivity of the two chips, their provided datasheets offer specific configurations that they should be designed in to ensure proper functionality.
Although very dense, these blueprints promised individual functionality for each chip, all that was left was connecting them together.
The two of these chips must work in tandem for power to be successfully delivered to the CM4, if either failed, none of the other parts of the board could be tested.
In the event this happened, a secondary method of powering the board directly was added in the form of the generic two-pin header \emph{J2}.
These two pins are simply 5v input and ground through-hole pins that bypass all the power circuitry just described.
Once the CM4 could be powered, the rest of the I/O could be designed.

\subsection{USB}\label{subsec:DesigningUSB}

\begin{figure}[t]
  \centering
  \begin{subfigure}{.5\textwidth}
    \centering
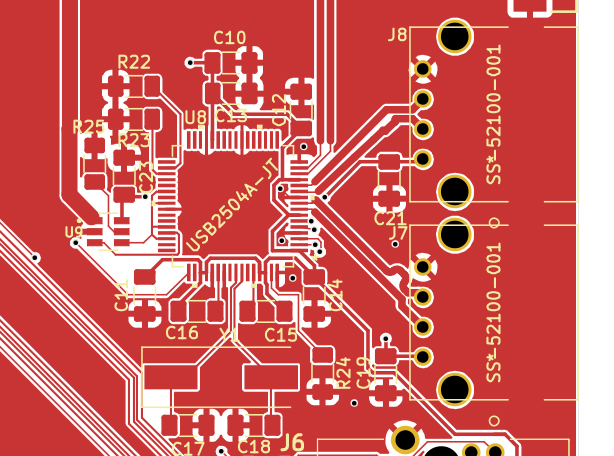
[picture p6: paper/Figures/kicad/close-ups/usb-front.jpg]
    
  \end{subfigure}%
  \begin{subfigure}{.5\textwidth}
    \centering
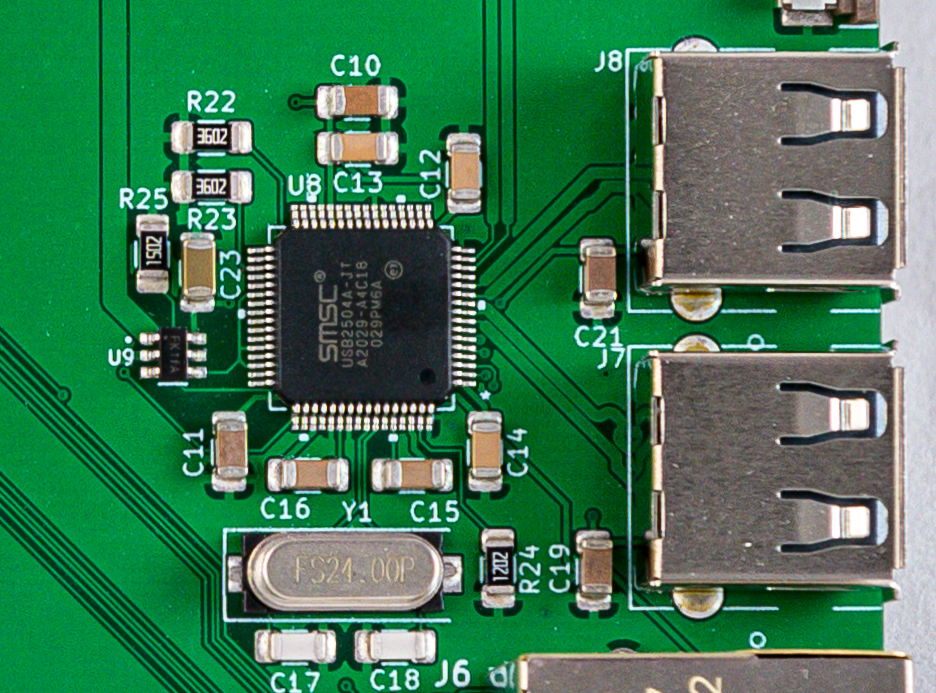
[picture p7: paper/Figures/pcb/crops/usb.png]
    
  \end{subfigure}
  \caption[PCB USB Circuit]{The front side of the PCB's USB circuit}
  \label{fig:USBCircuit}
\end{figure}

\begin{figure}[b!]
  \centering
  
  \caption[USB Schematic]{Schematic layout for the USB hub and ports. Expanded in Appendix \ref{app:pcb_schematic_usb}}
  \label{fig:pcb_schematic_usb}
\end{figure}

The next prominent circuit on the board is the section that controls the USB ports.
As seen in Figure \ref{fig:USBCircuit} (schematic in Figure \ref{fig:pcb_schematic_usb}), the dense circuit is mostly comprised of the USB controller chip, \emph{U8}, it's associated components, and the four USB ports, two of which are pictured as \emph{J7} and \emph{J8}.
Similarly to the power circuit, the USB controller chip is a very sensitive component that must be arranged in relation to other components in a certain way in order to ensure it will function properly.
This includes surrounding the chip with numerous capacitors to normalize any small power fluctuations, using a specific load balancing power distribution switch (\emph{U9}), and an oscillating crystal to provide a stable clock for the chip.
The chip connects to each of the four downstream USB ports and handles all of the digital signal processing before sending the data to the upstream CM4.

\subsection{HDMI}\label{subsec:DesigningHDMI}

\begin{figure}[t]
  \centering
  \begin{subfigure}{.33\textwidth}
    \centering
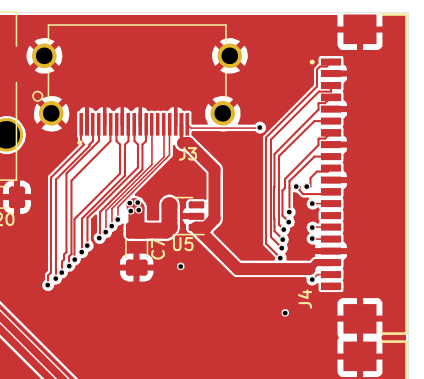
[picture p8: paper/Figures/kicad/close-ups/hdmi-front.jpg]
    
    \caption{The front side of the PCB}
    \label{fig:HDMICircuitFront}
  \end{subfigure}%
  \begin{subfigure}{.33\textwidth}
    \centering
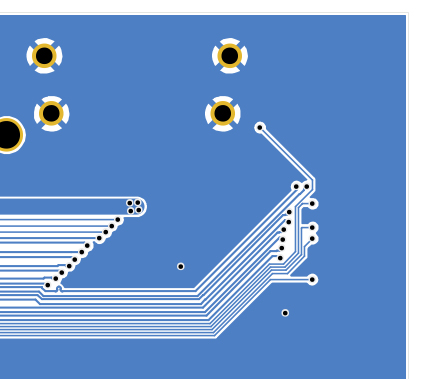
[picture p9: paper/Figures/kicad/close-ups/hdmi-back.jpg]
    
    \caption{The back side of the PCB}
    \label{fig:HDMICircuitBack}
  \end{subfigure}%
  \begin{subfigure}{.33\textwidth}
    \centering
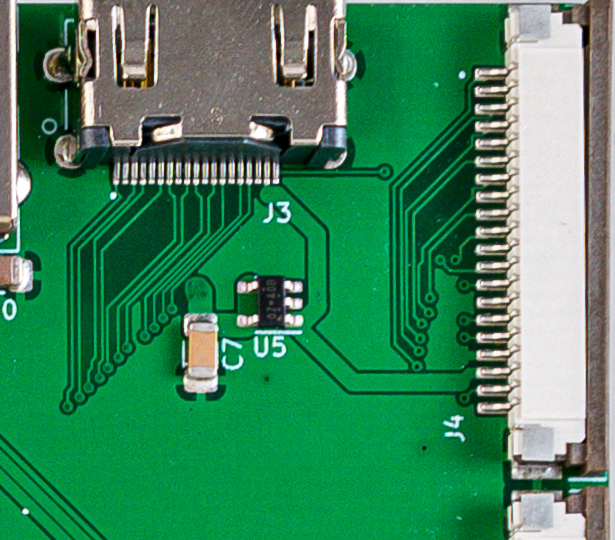
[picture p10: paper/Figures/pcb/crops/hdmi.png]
    
    \caption{The physical PCB}
    \label{fig:HDMICircuitReal}
  \end{subfigure}
  \caption[PCB HDMI Circuit]{The PCB's HDMI circuit}
  \label{fig:HDMICircuit}
\end{figure}

% While this is the image for the CM4 section, it makes sense to put it here
\begin{figure}[b!]
  \centering
  \begin{subfigure}{.33\textwidth}
    \centering
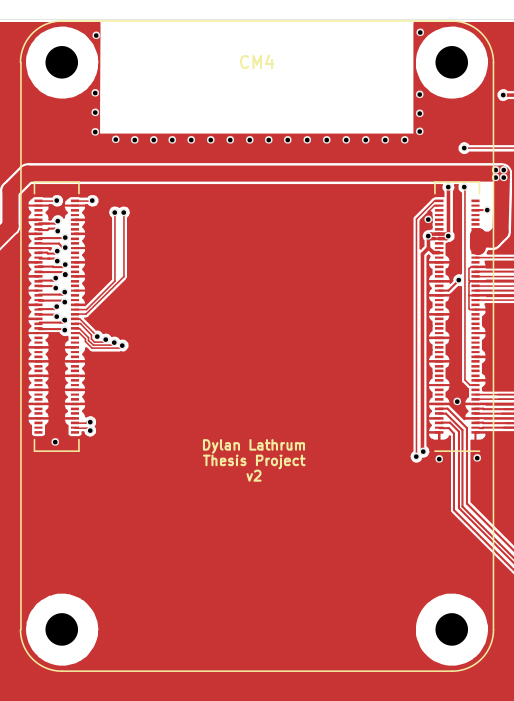
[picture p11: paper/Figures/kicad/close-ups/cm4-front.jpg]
    
    \caption{The front side of the PCB}
    \label{fig:CM4CircuitFront}
  \end{subfigure}%
  \begin{subfigure}{.33\textwidth}
    \centering
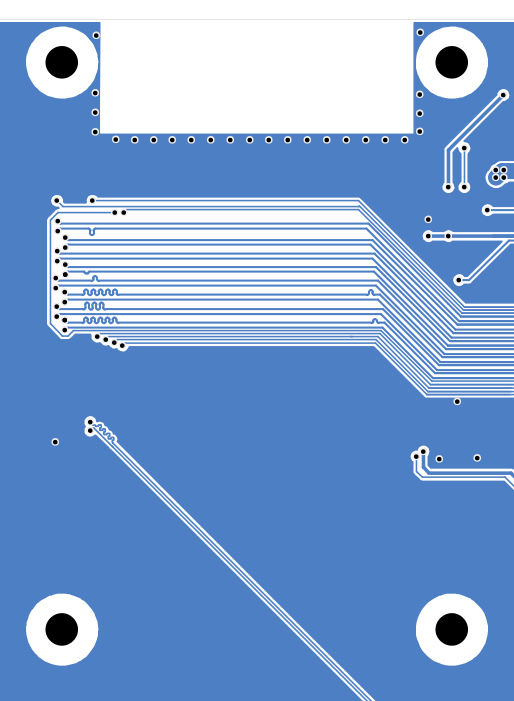
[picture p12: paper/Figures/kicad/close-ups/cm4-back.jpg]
    
    \caption{The back side of the PCB}
    \label{fig:CM4CircuitBack}
  \end{subfigure}%
  \begin{subfigure}{.33\textwidth}
    \centering
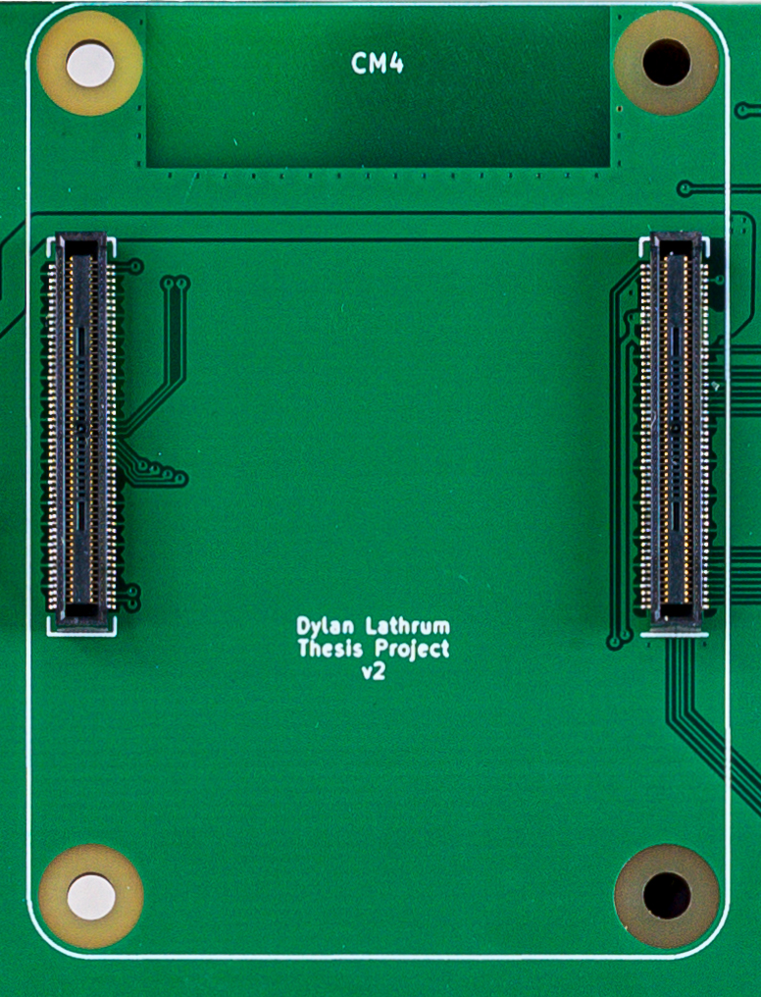
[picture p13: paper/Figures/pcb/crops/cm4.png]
    
    \caption{The physical PCB}
    \label{fig:CM4CircuitReal}
  \end{subfigure}
  \caption[PCB CM4 Circuit]{The circuitry surrounding the CM4's two mezzanine connectors}
  \label{fig:CM4Circuit}
\end{figure}

Another vital part of the board is the two HDMI ports provided by the device.
Thankfully, unlike the USB ports, HDMI ports send information in only one direction, so an extra chip is not necessary to handle the data as an intermediary.
All that is necessary is to connect the two HDMI ports to the CM4 in the right order and the device will be able to output the rendered video to a display.
Because this device is intended to be a standalone machine, it makes sense to have essential components like a screen integrated as part of the design.
The only issue with simply attaching an HDMI cable inside of the device is that the ports are relatively bulky and inflexible, meaning that another solution must be created to fit in the tight space.
This is accomplished with the Flat Flexible Cable Connector, seen on the right side of Figure \ref{fig:HDMICircuitFront} as \emph{J4}.
Flat Flexible Cables (FFC) are generic bendable cables that can be used in tight spaces.
Even though their connectors are completely generic, meaning that they have no set pinout, it is possible to use them given that the receiving screen will take in the FFC in the same order as a HDMI cable.
Using this knowledge, an internal FFC can be wired for the device's primary screen, while a second traditional HDMI port can be exposed to the user in case they want to use an external monitor.
This, along with the FFC used for one of the four USB ports, allows a screen to be hooked up to the CM4 internally without needing to expose anything to the user.

\subsection{CM4 and Miscellaneous}\label{subsec:DesigningCM4}

\begin{figure}[t!]
  \centering
  
  \caption[CM4 Schematic]{Schematic layout for interfacing with the Compute Module 4. Expanded in Appendix \ref{app:pcb_schematic_cm4}}
  \label{fig:pcb_schematic_cm4}
\end{figure}

Finally, everything must connect to the CM4.
Figure \ref{fig:CM4Circuit} shows the the two mezzanine connectors the CM4 uses to communicate with the rest of the PCB (schematic in Figure \ref{fig:pcb_schematic_cm4}).
Remember that there is only 0.04mm of space in between each of the pins, leaving very little space to route the traces where they need to go.
The first thing to notice is the large stretch of traces on the back side of the board coming from the HDMI ports.
Because most of the traces come in positive and negative pairs, called differential pairs, the two tracks must be roughly the same length as each other.
This is because as data is transmitted across the pair of tracks, they need to arrive at their destination at the same time based on the physical distance the signals need to cover.
Since the speed of electricity is constant throughout the PCB board, the traces may need to wind back and forth so that the lengths of the positive and negative tracks are equal.
Also note the blank area surrounded by vias at the top of Figure \ref{fig:CM4Circuit}.
This is where the WiFi and Bluetooth antennas are located on the CM4 board.
By removing the copper pour from this area on the PCB board and stitching the perimeter with vias, it prevents the board from acting like another antenna and interfering with the signals being sent to and from the CM4.
Finally, each of the other components are connected to the CM4 board in the same manner as described throughout this chapter, such as the Ethernet adapter, the SD card reader, and remaining ports.
These ports are connected by simply connecting the appropriate pin on the CM4's mezzanine connector to the corresponding pin on the component.
Apart from the concerns brought up by keeping the differential pairs in line and the power carefully managed as with the previous components described in detail, there are no special considerations that need to be made while designing the layout for these components.
See Appendices \ref{AppendixA} and \ref{AppendixB} for further information.

\section{Manufacturing the Circuit Board}\label{sec:ManufacturingThePCB}

\begin{figure}[t]
  \centering
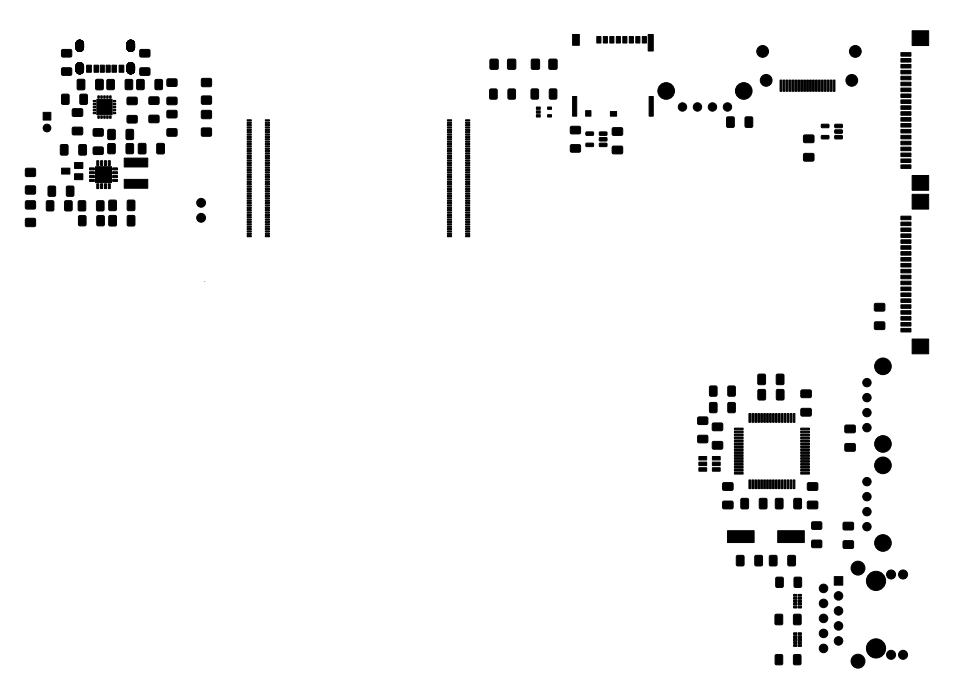
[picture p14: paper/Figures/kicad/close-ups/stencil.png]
  
  \caption[PCB Stencil]{The PCB's stencil. Areas colored black are where solder paste is applied to solder SMD parts to the board}
  \label{fig:PCBStencil}
\end{figure}

Once the board's design has been completed and checked against all electrical, functional, and manufacturing constraints, the Printed Circuit Board can be produced.
The first step in fabrication is to print the actual PCB.
While ASU offers a basic printing service for use in classes and academic projects, the requirements of this board, specifically the tiny traces and pads required for the CM4's mezzanine connectors (pictured in Figure \ref{fig:rpi_cm4_mezzanine}), are outside of the printer's capabilities.
Instead, by recommendation of a professor, the printing was done through an external company that provides quick turnaround and low costs for printing PCBs \cite{jlcpcb}.
A set of five boards was ordered, allowing for multiple boards to be assembled in case of error, as well as a stencil.
A PCB stencil is a thin sheet of metal with holes cut in it that line up with the pads on the PCB board.
This enables the easy application of solder paste onto all of the pads on the board as once, including the difficulty small pads of the CM4's mezzanine connectors.
While the PCB was being printed, all of the parts found in the Bill of Materials (found in Appendix \ref{AppendixB}) were ordered from sites such as Digi-Key and Mouser \cite{digikey,mouser}.
In order to account for the production of multiple prototype boards and the possibility of broken parts, enough parts were ordered to produce five complete boards.

\subsection{First Attempt}\label{subsec:Manufacturing1}

Once the PCB and it's component parts arrived, the board could be assembled.
The first board was assembled by hand using the PCB stencil and a handheld heat gun.
The stencil, shown as an image in Figure \ref{fig:PCBStencil}, is used by securing it the PCB board so that the holes line up with the pads, and spreading solder paste across it allowing the paste to cover the exposed pads through the holes.
The stencil was then removed, and each of the surface mounted components were then placed onto the board using a set of tweezers.
For tricky parts such as the CM4's mezzanine connectors and other small parts with the pads below the component itself, a microscope was used to assist in lining up the pads with the components.
Once the parts were placed, a heat gun was used to melt the solder paste and fuse the components to the board.
Following the SMDs, the through-hole components, such as the ports lining the side of the board, were then placed and soldered using a hand-held soldering iron.

\begin{figure}[t]
  \centering
  
  \caption[Hand-soldered mezzanine connector]{The leftovers of the broken-off mezzanine connector from the hand-soldered first board. Notice the exposed copper and warped pads.}
  \label{fig:brokenmezzanine}
\end{figure}

The first board ran into two issues that prevented it from working.
Firstly, due to improper use of the heat gun, most of the LEDs had popped, resulting in all hardware-level diagnostic indicators being inoperable.
Secondly, the CM4 connectors were not properly connected to the board, and in an attempt to repair it, the connector components were irreparably damaged and the board itself was damaged slightly, seen in Figure \ref{fig:brokenmezzanine}.
Instead of attempting to assemble another board by hand, a local third-party company was contacted to assemble the board professionally.
After delivering the board, stencil, and parts, the second board was assembled.

\subsection{Second Attempt}\label{subsec:Manufacturing2}

The second board was assembled mostly successfully, and allowed the first stage of testing to begin.
The only issue apart from some ports being too close together with real-world cables was one component having the wrong footprint on the board.
Unfortunately, the component \emph{U2 (MCP73871-2CCI\_ML)}, is described as using the \emph{QFN-20-1EP\_4x4mm} footprint in its datasheet \cite{MCP73871-2CCI/ML-ND_datasheet}, but actually uses a revised version of the footprint, shown in Figure \ref{fig:FootprintQFN204x4}.
This discrepancy meant that that component could not be soldered, and it's associated circuit would not function properly.
In this case, the component was a part of the battery charging circuit, causing the entire primary power supply to be unusable.
Thankfully, as described in Section \ref{sec:Prototyping}, the secondary method of powering the board could be used to test the remaining features of the board.
After making the necessary fixes, a second round of five PCB boards and a stencil was ordered.
Because there was still enough components to assemble three more boards, and no components needed to be changed, no more components were ordered at this stage.
Once the boards were delivered, the revised board was again sent to be professionally assembled.

\begin{figure}[t]
  \centering
  \begin{subfigure}{.5\textwidth}
    \centering
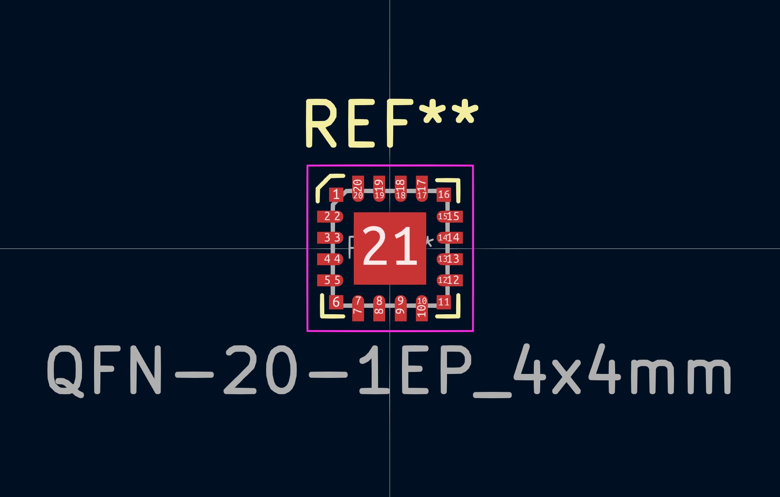
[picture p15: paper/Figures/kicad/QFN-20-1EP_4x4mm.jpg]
    
    \caption{\emph{QFN-20-1EP\_4x4mm}}
    \label{fig:FootprintQFN204x4_Original}
  \end{subfigure}%
  \begin{subfigure}{.5\textwidth}
    \centering
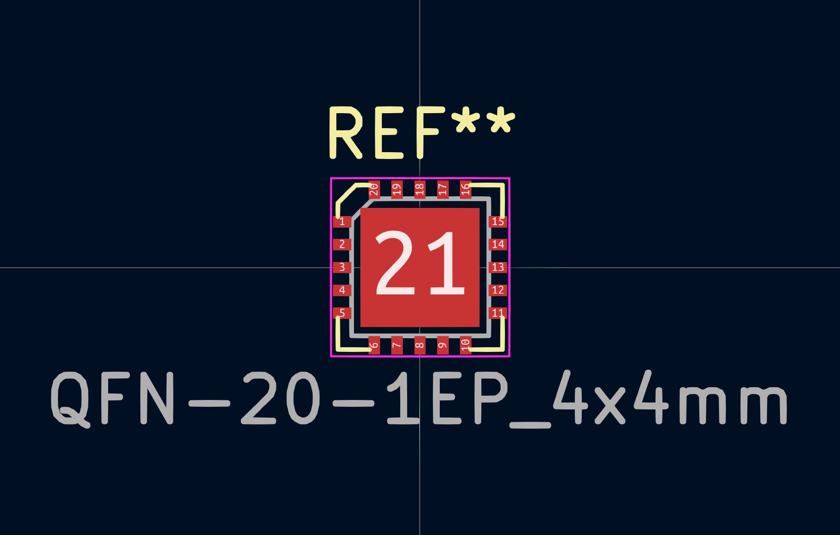
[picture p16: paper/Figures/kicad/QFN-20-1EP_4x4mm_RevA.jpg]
    
    \caption{\emph{QFN-20-1EP\_4x4mm\_RevA}}
    \label{fig:FootprintQFN204x4_RevA}
  \end{subfigure}
  \caption[Two versions of the QFN-20-1EP\_4x4mm package]{The two footprints for components with the \emph{QFN-20-1EP\_4x4mm} package. The original footprint is shown in Figure \ref{fig:FootprintQFN204x4_Original}, while the revised footprint is shown in Figure \ref{fig:FootprintQFN204x4_RevA}}
  \label{fig:FootprintQFN204x4}
\end{figure}

\subsection{Third Attempt}\label{subsec:Manufacturing3}

\begin{figure}[!b]
  \centering
  
  \caption[Assembled PCB]{The assembled PCB}
  \label{fig:AssembledPCB}
\end{figure}

Once the third board was assembled, the board could be tested in full.
While each part of the board was at least partially functional, there were still issues preventing it from working completely.
In particular, USB devices plugged into any of the ports on the board were able to receive power from the board but were unable to transfer data in either direction.
Thankfully, this did not prevent testing of the board from being completed, but it did stop the board from being considered a final complete product.
This board could still be used for testing by connecting peripherals such as the keyboard and mouse through bluetooth and powering the screen through USB.
Figure \ref{fig:AssembledPCB} shows the final assembled board, with the final PCB layouts in Figures \ref{app:pcb_layout_front} and \ref{app:pcb_layout_back}.

\section{Summary}\label{sec:HardwareSummary}

In order to produce a hardware device capable of fitting the needs of the project, a careful balance between power and cost had to be found.
The Raspberry Pi Compute Module 4 offered enough power to power the project while maintaining a low cost and slim profile that enabled it to fit in a small mobile device.
Once the CM4 was chosen, a custom PCB had to be designed and manufactured to tailor the Compute Module to the needs of the project.
This included choosing compatible electronic components, designing a board that provided the necessary functionality, and developing multiple iterations of the board to fix problems as they arose.
After three iterations, a board was finally produced that could be used to develop the software portion of the thesis.

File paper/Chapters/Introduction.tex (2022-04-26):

\chapter{Introduction}

\label{Chapter1}

\section{Power and Portability}

As computers continue to grow to become more and more integrated into our daily lives, purchasing a computer has always been a balance.
Whether its deciding between something cheap or something long-lasting, a machine that is pre-built or a machine that is custom tailored and custom built, or, a tradeoff that has become much more common in recent years, something powerful or something portable.
As with anything, compromises can always be made and a middle ground may be found, but the only way to get the best of both worlds currently is to pay a price premium.
If someone were to look for a computer that is powerful, long-lasting, and upgradable, they would be directed towards a desktop computer.
However, if they needed something with the same power but portable, their only option would be to purchase a laptop costing much more than its desktop counterpart and often with limitations in upgradeability down the line.
Without purchasing both an expensive desktop and an expensive laptop, there currently is no way to get the benefits of both power and portability.

\section{Purpose of this Thesis}

The primary goal of this thesis is to create a portable hardware and software solution that can be used to control a desktop computer remotely while leveraging all of it's power.
There are existing software solutions that give a user remote control of their desktop computer from a different location, which will be introduced in Chapter \ref{Chapter3}, but such solutions may not provide a performant and high-quality  experience for the user.
These solutions will be tested while running highly demanding applications such as rendering animation, training Artificial Intelligence models, or developing video games to see if they are capable of working in such situations.

In other words, this thesis seeks to provide a user who already owns a powerful desktop computer with a mobile solution that gives them the ability to leverage it's power remotely.

\section{Thesis Overview}

This thesis is split into seven chapters.
Chapter \ref{Chapter2} introduces background knowledge surrounding existing computers, the shift to a more mobile computing world, and the modern day applications for this technology.
Chapter \ref{Chapter3} discusses the current the state of the art in terms of existing solutions for remote computer access, and presents a list of questions that this thesis seeks to answer.
Chapters \ref{Chapter4} and \ref{Chapter5} detail the requirements, design, and production of the hardware and software portions of the project respectively.
This design is tested against the requirements and the existing solutions in Chapter \ref{Chapter6}.
Finally, Chapter \ref{Chapter7} concludes the thesis with a summary of the project's innovations, limitations, and future research.

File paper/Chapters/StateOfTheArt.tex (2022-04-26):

\chapter{State of the Art}

\label{Chapter3}

This chapter seeks to provide a summary of existing solutions for remote computer access.
It will not cover specific applications, but rather the protocols that are used to communicate with a remote computer.
Generally speaking, there are two types of solutions that have been developed, software solutions, which are covered in Chapter \ref{sec:SoftwareSolutions} and hardware solutions, which are covered in Chapter \ref{sec:HardwareSolutions}.
Various protocols and implementations are covered in the subsections of those two categories.

\section{Software Solutions}\label{sec:SoftwareSolutions}

While there are many applications in existence that allow a user to remotely control a computer from another location, few of them offer the capabilities required to stream high-performing applications to a remote device.
The following subsections will introduce existing solutions to this problem as well as drawbacks that come with each implementation.

\subsection{Remote Desktop Protocol}\label{subsec:RemoteDesktopProtocol}

Microsoft's Remote Desktop Protocol (RDP), is a protocol that defines communication between a terminal server and terminal server client for multimedia purposes \cite{rdpDocs}.
Coming pre-installed on every Windows machine since Windows XP and with clients available for Windows, Mac, and Linux, RDP is an easy to use solution for remotely accessing Windows machines graphically.

Although it is the built-in solution for Windows machines, it isn't without it's drawbacks.
Firstly, only one graphical session is active at one time while using windows.
This means if a user is logged into the host computer and someone initiates a connection with RDP, the user using the host computer will be logged out.
While this isn't always an issue, sensitive programs that don't take well to being logged out may run into issues.
Secondly, RDP does not support relative mouse movement \cite{burgin_2013}.
This means every mouse input is sent to the host computer as an absolute position on the screen, rather than as a relative distance from it's previous location.
This means any program that moves the user's mouse for them, such as 3D applications with a virtual camera, will be sent the absolute position of the client's mouse.
This will cause the application to detect a large movement of the mouse instantly, which can result in erratic camera movement as the program interprets the mouse moving a large distance every time the cursor is reset to the center of the screen.
Again, while this isn't always an issue, tasks such as 3D modeling and animation or game development cannot be controlled properly.

\subsection{Virtual Network Computing}\label{subsec:VirtualNetworkComputing}

Virtual Network Computing (VNC), is a platform-independent system originally developed by Olivetti \& Oracle Research Labs and later bought and shelved by AT\&T \cite{vncFlavors}.
While the original implementation is no longer used in a wide capacity, the protocol it was developed on has been expanded and improved to become one of the most flexible yet simple ways to control a computer remotely.
VNC can run on any modern operating system, and even a web browser can serve as a VNC client.
It was originally built as the simplest form of remote computer control over LAN, allowing system administrators to control almost any kind of computer with a simple, robust, and extremely compatible system.
However, since its use has gradually outgrown it's original scope, VNC isn't usually the right tool for any job greater than remote system management.
Because of it's simplicity and focus on being as straightforward as possible, VNC is often found to be lacking in terms of security and speed \cite{vncFlavors}.
It is not recommended to use VNC over the internet without some secondary form of security, such as SSL or a secure VPN.

\subsection{Chrome Remote Desktop}\label{subsec:ChromeRemoteDesktop}

Google Chromoting, implemented publicly as Chrome Remote Desktop, is an open source protocol that enables remote desktop control through any web browser running on the Chromium engine \cite{chromotingBuildInstructions}.
It prioritizes low bandwidth usage and ease of access, allowing easy server install on every major desktop operating system, and enables any web browser or mobile device to act as a client.
By employing the VP8 compression format (Most commonly seen in internet video streaming), Chromoting is able to keep network traffic low by only sending a few full images of the server's screen as keyframes and transmitting motion with compressed partial frames \cite{miniorange_chromoting}.
These partial frames are calculated by the server using the difference between the previous and current frame, allowing the server to only send the difference between the two frames.

This save in bandwidth and processing done by the client makes it the perfect solution for Google's ChromeOS laptops coming out around the same time.
These low powered machines were built to be laptops running on the power of a web browser with a link back to more powerful computers when the tasks were too great \cite{upson_sengupta_2012}.
While the protocol works well for remote access, it is limited in certain applications by it's conservative approach to bandwidth usage and reliance on the web browser.

\subsection{Secure Shell Protocol}\label{subsec:SecureShellProtocol}

The Secure Shell Protocol (SSH), is a protocol for securely transmitting data over an insecure network \cite{rfc4251}.
Usually used for remote server management, SSH has become the de facto standard for connecting to a remote computer when nothing more than terminal access is needed.
Paired with the associated SSH file transfer (SFTP) or secure copy (SCP) protocols, SSH provides an incredible amount of flexibility for working with remote computers.
It's largest and most obvious drawback is limited graphical support.
While not a problem for it's traditional use-case, it does limit what high-intensity applications can be used with it.

One recent innovation in remote computing has been the introduction of Remote Development using SSH through the Visual Studio Code IDE.
By opening multiple SSH connections to the host machine at once, Visual Studio Code is able to run the IDE's User interface on the client's machine, and simply send all the written code and commands through to the host machine, utilizing it's power to compile code, run applications, and debug software \cite{vscode_ssh}.
This enables a development experience comparable to working on a local machine by only transmitting the data that is needed over the internet and constructing the visual user interface on the client.
Because of this, high-intensity computational programs such as Artificial Intelligence training and simulation can be run on a powerful host machine and only need to transmit the output to the lower-powered client, but graphical applications are still limited.

\section{Hardware Solutions}\label{sec:HardwareSolutions}

While Hardware solutions are not as popular or widespread as software solutions, there has been some innovation in the field that is worth considering.
Hardware solutions usually focus on building a device that has just enough power to connect and stream data to a remote computer in order to leverage its power for the user to use.

\subsection{Thin Clients}\label{subsec:ThinClients}

As discussed in Section \ref{sec:ThinClients}, Thin Clients are a family of devices commonly seen in the corporate world to allow employees to access data centers and computing clusters from their desks.
Due to their low cost and ease of deployment, they are often the device of choice to enable employees to access the full power of the business' computing infrastructure without needed to purchase a powerful device for each employee.
However, since a typical thin client is a headless device, meaning it doesn't come with a monitor, keyboard, mouse, or other peripherals, they are often less portable as one might think.
A thin client is usually set up once, and then left in that place for as long as a desktop would stay.
Especially with laptop sales on the rise, thin clients do not have the benefit of being more portable than the alternatives.

\subsection{Nvidia Shield and GameStream}\label{subsec:NvidiaShieldAndGameStream}

\begin{wrapfigure}{r}{0.375\textwidth}
  \centering
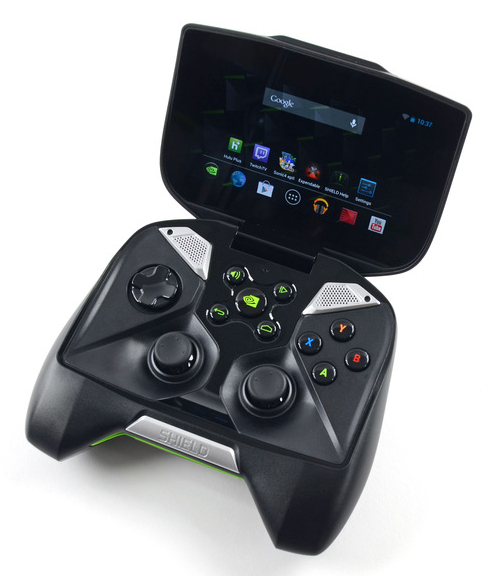
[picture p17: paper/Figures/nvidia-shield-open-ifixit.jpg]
  
  \caption[Nvidia Shield]{An open Nvidia Shield displaying the home page \cite{ImageNvidiaShield}.}
  \label{fig:nvidiashield}
\end{wrapfigure}

The Nvidia Shield game console was Nvidia's first foray into the realm of remote streaming.
Though it was focused on gaming and media streaming, it was one of the first attempts at using a portable device to stream intensive applications such as games from a host computer \cite{brown_2013}.
At the steep price point of \$349, it definitely was enthusiast hardware for a device that focused on mobile and desktop gaming over running console games or demanding titles locally.
But while the the physical device was praised for performance, battery life, and the experience of streaming games to the console, it didn't perform too well in terms of sales.
It was still widely regarded as a technological breakthrough though, and Nvidia continued to develop the technology into a new device called the Nvidia Shield TV \cite{daniel_2017}.
Focused on bringing the power of a gaming desktop to a TV, the Nvidia Shield TV dropped the idea of portability in favor of filling a different market focused on comfort.
While this is no longer a valid device for the purposes of this paper, the developments of the proprietary GameStream technology that powered the Shield and the Shield TV proved to be even more exciting than the physical devices themselves.

Though the GameStream technology that powers the Nvidia Shield devices is closed source and only officially compatible with the products Nvidia releases, its enticing power and potential drew a community to reverse engineer the protocol.
In 2013, a group of students at Case Western Reserve University developed Moonlight, an open source implementation of the GameStream protocol \cite{moonlight}.
The project is structured as a core library written in \emph{C} with a number of community built clients built on top of it for various platforms.
In essence, it turns the closed-source black-box protocol developed by Nvidia into a usable programming interface.
By reverse engineering the protocol originally implemented by the Nvidia Shield, Moonlight enables the development of a GameStream client for almost any operating system.
The Moonlight community has already developed fantastic clients for many platforms such as Windows, Mac, Linux, Android, iOS, Web, and even other gaming consoles.
This stands as a good starting place to develop the solution described in this paper.

\section{Research Questions}\label{sec:ResearchQuestions}

While there are many existing solutions for accessing a computer remotely, many struggle to be performant enough or efficient enough to stream demanding applications to the client without compromising on the user's experience.
This thesis will seek to build a solution that enables the use the power of a desktop computer from a mobile device in a way that is performant and responsive in response to the following questions:

\begin{enumerate}
  \item \textbf{Hardware Feasibility:} \emph{What hardware is needed in order to power a mobile device capable of acting as a client?}
  \item \textbf{Hardware Cost:} \emph{Is it feasible to construct such as device at a lower or comparable cost to existing solutions?}
  \item \textbf{Communication Protocol:} \emph{Does a protocol exist that is efficient enough to stream demanding applications to a client?}
  \item \textbf{Software Application:} \emph{Can a software solution be built to utilize this protocol in a manner that is performant enough?}
\end{enumerate}

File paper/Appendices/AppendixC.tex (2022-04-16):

\chapter{Open Source Repository} % Main appendix title

\label{AppendixC} % For referencing this appendix elsewhere, use \ref{AppendixA}

The entirety of this project, including hardware schematics and software code, is available online on GitHub at: \url{https://github.com/Dylancyclone/thesis}.

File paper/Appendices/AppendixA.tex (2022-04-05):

\chapter{PCB Specifications} % Main appendix title

\label{AppendixA} % For referencing this appendix elsewhere, use \ref{AppendixA}

\section{PCB Schematic}

\begin{figure}[h]
  \centering
  %Height instead of width because the image is rotated
  
  \captionsetup{width=1\linewidth}
  \caption[Top Level Schematic]{The top level of the PCB board schematic}
  \label{app:pcb_schematic_top}
\end{figure}

\begin{figure}[h]
  \centering
  %Height instead of width because the image is rotated
  
  \captionsetup{width=1\linewidth}
  \caption[Power Schematic]{Schematic layout for the power circuit, including battery management}
  \label{app:pcb_schematic_battery}
\end{figure}

\begin{figure}[h]
  \centering
  %Height instead of width because the image is rotated
  
  \captionsetup{width=1\linewidth}
  \caption[CM4 Schematic]{Schematic layout for interfacing with the Compute Module 4}
  \label{app:pcb_schematic_cm4}
\end{figure}

\begin{figure}[h]
  \centering
  %Height instead of width because the image is rotated
  
  \captionsetup{width=1\linewidth}
  \caption[USB Schematic]{Schematic layout for the USB hub and ports}
  \label{app:pcb_schematic_usb}
\end{figure}

% Make sure next section is on a new page
\clearpage
\section{PCB Layout}

\begin{figure}[h]
  \centering
  %Height instead of width because the image is rotated
  
  \captionsetup{width=1\linewidth}
  \caption[PCB Front Layout]{Physical board layout for the front side of the PCB}
  \label{app:pcb_layout_front}
\end{figure}

\begin{figure}[h]
  \centering
  %Height instead of width because the image is rotated
  
  \captionsetup{width=1\linewidth}
  \caption[PCB Back Layout]{Physical board layout for the back side of the PCB}
  \label{app:pcb_layout_back}
\end{figure}

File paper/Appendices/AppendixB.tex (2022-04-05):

\chapter{Bill of Materials} % Main appendix title

\label{AppendixB} % For referencing this appendix elsewhere, use \ref{AppendixA}

\begin{longtable}{|>{\raggedright\arraybackslash}p{0.2\linewidth}|c|l|l|}%
  \hline
  \bfseries Reference \newline Designator& \bfseries Count & \bfseries Manufacturer's Number &\bfseries Value % Columns
  \csvreader[respect percent=true, respect underscore=true, respect sharp=true, table head=\toprule, table foot=\bottomrule]{Figures/kicad/lathrum_thesis_bom.csv}{}% Data
  {\\\hline\csvcoli&\csvcolii&\csvcolv&\csvcoliii}% Rows
  \\\hline
  \caption[Bill of Materials]{Bill of Materials for a single PCB Board.}
  \label{tab:BillOfMaterials}
\end{longtable}

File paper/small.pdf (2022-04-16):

### ARIZONA STATE UNIVERSITY (https://www.asu.edu/)

HONORS THESIS

# Building a Mobile Device that Leverages the Power of a Desktop Computer

Author:
Dylan LATHRUM (https://www.linkedin.com/in/dylanlathrum/)

Supervisor:
Dr. Robert HEINRICHS (https://isearch.asu.edu/profile/3180015)

A thesis submitted in fulfillment of the requirements for the degree of Software Engineering

for

Barrett, The Honors College (https://barretthonors.asu.edu/)

April 13, 2022

iii

# Declaration of Authorship

I, Dylan LATHRUM, declare that this thesis titled, “Building a Mobile Device that Leverages the Power of a Desktop Computer” and the work presented in it are my own. I confirm that:

- This work was done wholly or mainly while in candidature for a research degree at this University.
- Where any part of this thesis has previously been submitted for a degree or any other qualification at this University or any other institution, this has been clearly stated.
- Where I have consulted the published work of others, this is always clearly attributed.
- Where I have quoted from the work of others, the source is always given. With the exception of such quotations, this thesis is entirely my own work.
- I have acknowledged all main sources of help.
- Where the thesis is based on work done by myself jointly with others, I have made clear exactly what was done by others and what I have contributed myself.

Signed: Dylan Lathrum

Date: 4/15/2022

v

“Premature optimization is the root of all evil.”

Sir Tony Hoare

vii

ARIZONA STATE UNIVERSITY (HTTPS://WWW.ASU.EDU/)

# Abstract

Barrett, The Honors College (https://barretthonors.asu.edu/)

Software Engineering

Building a Mobile Device that Leverages the Power of a Desktop Computer

by Dylan LATHRUM

With the recent focus of attention towards remote work and mobile computing, the possibility of taking a powerful workstation wherever needed is enticing. However, even emerging laptops today struggle to compete with desktops in terms of cost, maintenance, and future upgrades. The price point of a powerful laptop is considerably higher compared to an equally powerful desktop computer, and most laptops are manufactured in a way that makes upgrading parts of the machine difficult or impossible, forcing a complete purchase in the event of failure or a component needing an upgrade.
In the case where someone already owns a desktop computer and must be mobile, instead of needing to purchase a second device at full price, it may be possible to develop a low-cost computer that has just enough power to connect to the existing desktop and run all processing there, using the mobile device only as a user interface.

ix

# Acknowledgements

I would like to express my graditude to my thesis director, Dr. Robert Heinrichs, and to each of my committee members, Professor Ruben Acuña and Dr. Shawn Jordan, for their help in the development of this thesis. Without their guidance, I would not have been able to step so far outside of my comfort zone and learn about so many new topics to make this thesis happen. I would also like to thank my friends and family who were always there to bounce ideas off of and inevitably tell me when I was trying to fit too many words into a single section.

xi

# Contents

Declaration of Authorship | iii
Abstract | vii
Acknowledgements | ix
List of Abbreviations | xvii
1 Introduction | 1
2 Background | 3
3 State of the Art | 7
4 Developing the Hardware | 11

xii

5 Developing the Software | 25
6 Evaluation | 31
7 Conclusion | 39
A PCB Specifications | 41
B Bill of Materials | 47
C Open Source Repository | 49
Bibliography | 51

xiii

# List of Figures

2.1 Thin Client | | 5
3.1 Nvidia Shield | | 9

4.1 Raspberry Pi Compute Module 4 | 13 4.2 Raspberry Pi Compute Module 4 Pin out | 13 4.3 USB Controller | 16 4.4 SMD Breakout Board | 16 4.5 PCB Power Circuit | 17 4.6 Power Schematic | 17 4.7 PCB USB Circuit | 18 4.8 USB Schematic | 18 4.9 PCB HDMI Circuit | 19 4.10 PCB CM4 Circuit | 19 4.11 CM4 Schematic | 20 4.12 PCB Stencil | 21 4.13 Hand-soldered mezzanine connector | 22 4.14 Two versions of the QFN-20-1EP_4x4mm package | 22 4.15 Assembled PCB | 23

### 6.1 Input Delay Data | 33 6.2 Color Delay Data | 34 6.3 Color Delay Loss Data | 35 6.4 CRD Data | 37

A.1 Top Level Schematic | 41
A.2 Power Schematic | 42
A.3 CM4 Schematic | 43
A.4 USB Schematic | 44
A.5 PCB Front Layout | 45
A.6 PCB Back Layout | 46

xv

# List of Tables

xvii

# List of Abbreviations

BOM Bill Of Materials
CM4 | Raspberry Pi Compute Module 4
CPU | Central Processing Unit
CRD | Chrome Remote Desktop
CSV | Comma Separated Values
FFC | Flat Flexible Cable
FPS | Frames Per Second
GPU | Graphics Processing Unit
IDE | Integrated Development Environment
PC | Personal Computer
PCB | Printed Circuit Board
RDP | Remote Desktop Protocol
RTC | Real Time Clock
SBC | Single Board Computer
SMD | Surface Mounted Device
SSH | Secure Shell (Protocol)
VNC | Virtual Network Computing

xix

## For my parents, and their endless support, encouragement, and

guidance.

1

## Chapter 1

# Introduction
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

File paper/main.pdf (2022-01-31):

### ARIZONA STATE UNIVERSITY (https://www.asu.edu/)

UNDERGRADUATE THESIS

# Building a Mobile Device that Uses the Power of a Desktop Computer

Author:
Dylan LATHRUM (https://www.linkedin.com/in/dylanlathrum/)

Supervisor:
Dr. Robert HEINRICHS (https://isearch.asu.edu/profile/3180015)

A thesis submitted in fulfillment of the requirements for the degree of Software Engineering

for

Barrett, The Honors College (https://barretthonors.asu.edu/)

January 26, 2022

iii
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

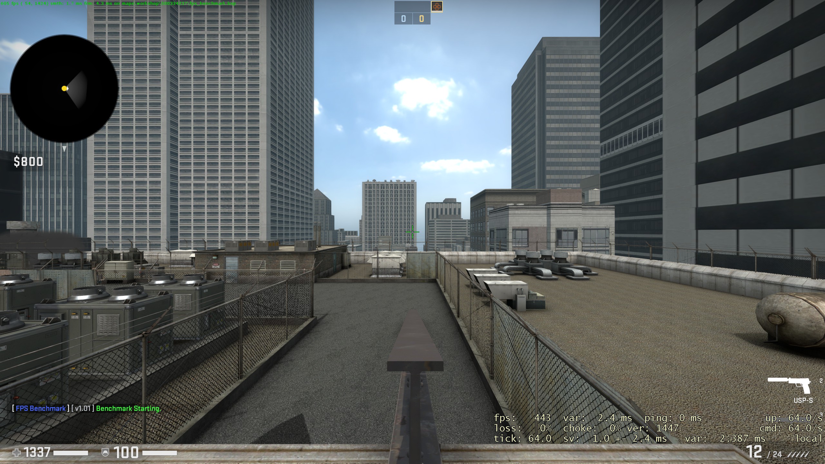
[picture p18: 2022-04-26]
paper/Figures/realworld/csgo.jpg

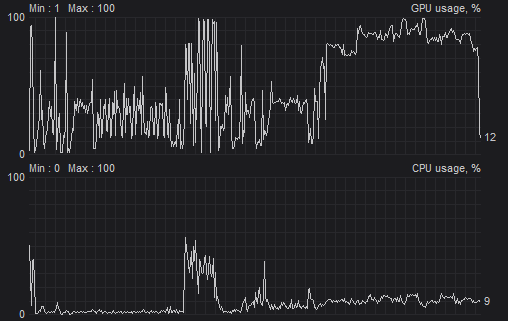
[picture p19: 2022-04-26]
paper/Figures/realworld/csgostats.png

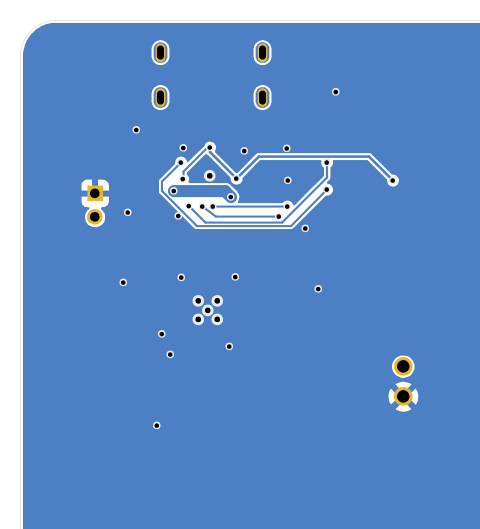
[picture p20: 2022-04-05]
paper/Figures/kicad/close-ups/power-back.jpg

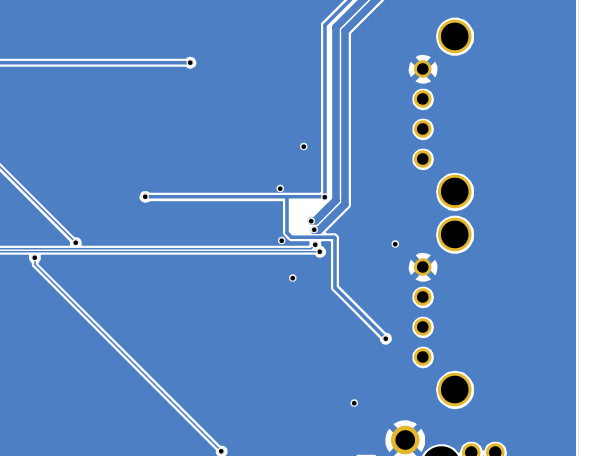
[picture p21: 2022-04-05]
paper/Figures/kicad/close-ups/usb-back.jpg

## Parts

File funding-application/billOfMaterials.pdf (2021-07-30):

SUMMARY | Hardware | Subtotal: $ 422.40 | PCB | Subtotal: $ 254.05 | Tools | Subtotal: $ 93.81 | Materials | Subtotal: $ 84.98
Category | Amount | Item | Quantity | Cost | Amount | Link | Item | Manufacturer Number | #/Board | Quantity | Cost | Amount | Link | Item | Quantity | Cost | Amount | Link | Item | Quantity | Cost | Amount | Link
Hardware | $ 422.40 | Raspberry Pi 4 2 GB | 0 $ 35.00 $ | - | Power In, Battery Battery Port JST-2PH | 1769 | 1 | 5 $ 0.75 $ | 3.75 https://www.adafruit.com/product/1769 Pinecil | 1 $ 24.99 $ 24.99 https://pine64.com/product/pinecil-smart-mini-portable-soldering-iron/ 3d printer filament - Black 1 $ 24.99 $ 24.99 https://www.amazon.com/HATCHBOX-3D-Filament-Dimensional-Accuracy/dp/B00J0ECR5I/
PCB | $ 254.05 | Raspberry Pi 4 8 GB | 1 $ 75.00 $ 75.00 | Voltage Regulator | TPS61090RSAR | 1 | 5 $ 2.48 $ 12.40 https://www.digikey.com/en/products/detail/texas-instruments/TPS61090RSAR/566911 Pinecil mini stand | 1 $ 1.99 $ | 1.99 https://pine64.com/product/pinecil-portable-mini-stand/ Solder 0.031" | 1 $ 25.90 $ 25.90 https://www.amazon.com/Kester-24-6337-0027-Solder-Alloy-Diameter/dp/B0149K4JTY/
Tools | $ 93.81 | CM4108000 | 1 $ 75.00 $ 75.00 | Battery Charger | MCP73871T-2CCI/ML | 1 | 5 $ 1.88 $ | 9.40 https://www.digikey.com/en/products/detail/microchip-technology/MCP73871T-2CCI-ML/1680976 Solder cleaning station | 1 $ 9.99 $ | 9.99 https://www.amazon.com/Aoyue-Soldering-Cleaner-sponge-needed/dp/B005C789EU/ Solder 0.020" | 1 $ 34.09 $ 34.09 https://www.amazon.com/dp/B00068IJWC/
Materials | $ 84.98 | CM4104000 | 1 $ 50.00 $ 50.00 | USB-C Connector | USB-C31-S-RA-CS1D-BK-T/R | 1 | 0 $ 1.61 $ | - | https://www.digikey.com/en/products/detail/adam-tech/USB-C31-S-RA-CS1D-BK-T-R/9832218 Wire cutters | 1 $ 4.97 $ | 4.97 https://www.amazon.com/Pliers-Electrical-Cutters-Cutting-Diagonal/dp/B0188DHO40/
Subtotal | $ 855.24 | CM4102000 | 0 $ 35.00 $ | - | USB-C Connector (power only) USB4125-GF-A | 1 | 5 $ 0.67 $ | 3.35 https://www.digikey.com/en/products/detail/gct/USB4125-GF-A/13547388 Solder sucker and wire | 1 $ 9.99 $ | 9.99 https://www.amazon.com/Desoldering-Solder-Sucker-Length-Remover/dp/B07BB8DGMP/
Tax Estimate | $ 70.98 | CM4101000 | 0 $ 30.00 $ | - | LED charging | C5SMF-AJE-CU0V0342 | 1 | 5 $ 0.15 $ | 0.75 https://www.digikey.com/en/products/detail/cree-inc/C5SMF-AJE-CU0V0342/6138566 Antistatic tweasers kit | 1 $ 11.95 $ 11.95 https://www.amazon.com/Precision-Anti-static-Non-magnetic-Multi-standard-Electronics/dp/B06XXXQHS8/
Shipping Estimate $ 72.70 | Waveshare 7inch DSI screen | 1 $ 59.99 $ 59.99 https://www.waveshare.com/7inch-DSI-LCD.htm LED charged | C5SMF-GJF-CV0Y0791 | 1 | 5 $ 0.19 $ | 0.95 https://www.digikey.com/en/products/detail/cree-inc/C5SMF-GJF-CV0Y0791/4793796 Wire holder | 1 $ 9.99 $ | 9.99 https://www.amazon.com/Neiko-01902-Adjustable-Magnifying-Alligator/dp/B000P42O3C/
TOTAL | $ 998.92 | Waveshare 7inch HDMI screen (C) | 1 $ 62.99 $ 62.99 https://www.waveshare.com/7inch-HDMI-LCD-C.htm LED power | C5SMF-BJE-CR0U0451 | 1 | 5 $ 0.19 $ | 0.95 https://www.digikey.com/en/products/detail/cree-inc/C5SMF-BJE-CR0U0451/4793773 Solder mat | 1 $ 6.99 $ | 6.99 https://www.amazon.com/gp/product/B07DGVJ17H/
Wireless Thin Mouse | 1 $ 11.99 $ 11.99 https://www.amazon.com/Bluetooth-Wireless-Computer-Rechargeable-Replacement/dp/B08VDT528Q LED low | C5SMF-RJF-CT0W0BB1 | 1 | 5 $ 0.16 $ | 0.80 https://www.digikey.com/en/products/detail/cree-inc/C5SMF-RJF-CT0W0BB1/4793808 Solder reel | 1 $ 12.95 $ 12.95 https://www.amazon.com/Delcast-SL-RL-Solder-Dispenser-Reel/dp/B00PQF98X4/
iClever BK05 Foldable Bluetooth Keyboard | 1 $ 48.99 $ 48.99 https://www.amazon.com/gp/product/B018K5EJCQ/ Inductor 6.8uH (>2A) | BWVS005050406R8M00 | 1 | 5 $ 0.35 $ | 1.75 https://www.digikey.com/en/products/detail/chilisin-electronics/BWVS005050406R8M00/12140955
10000mAh DC 3.7V Rechargable Battery | 1 $ 18.49 $ 18.49 https://www.amazon.com/gp/product/B07S75HC2H Transistor | MMUN2133LT1G | 1 | 5 $ 0.13 $ | 0.65 https://www.digikey.com/en/products/detail/on-semiconductor/MMUN2133LT1G/1482316
PowerBoost 1000 Charger | 1 $ 19.95 $ 19.95 https://www.adafruit.com/product/2465 Thermistor 15k | NTCLE100E3153JB0 | 1 | 5 $ 0.69 $ | 3.45 https://www.digikey.com/en/products/detail/vishay-beyschlag-draloric-bc-components/NTCLE100E3153JB0/769413
Cap 10uF | CL31A106KPHNNNE | 3 | 10 $ 0.23 $ | 6.90 https://www.digikey.com/en/products/detail/samsung-electro-mechanics/CL31A106KPHNNNE/3886806
Cap 2.2uF | CL31B225KOHNNWE | 1 | 10 $ 0.19 $ | 1.90 https://www.digikey.com/en/products/detail/samsung-electro-mechanics/CL31B225KOHNNWE/3888799
Cap 0.1uF | C1206C104K5RAC7800 | 1 | 10 $ 0.11 $ | 1.10 https://www.digikey.com/en/products/detail/kemet/C1206C104K5RAC7800/411248
Cap 100uF | CL32A107MQVNNNE | 1 | 10 $ 0.71 $ | 7.10 https://www.digikey.com/en/products/detail/samsung-electro-mechanics/CL32A107MQVNNNE/3886750
Res 1.87M | CMF551M8700FHEB | 2 | 10 $ 1.73 $ 34.60 https://www.digikey.com/en/products/detail/vishay-dale/CMF551M8700FHEB/1554321
Res 5.1k | RNMF14FAD5K10 | 2 | 10 $ 0.10 $ | 2.00 https://www.digikey.com/en/products/detail/stackpole-electronics-inc/RNMF14FAD5K10/9770241
Res 340k | MFR-25FBF52-340K | 1 | 10 $ 0.10 $ | 1.00 https://www.digikey.com/en/products/detail/yageo/MFR-25FBF52-340K/13606
Res 200k | MFR-25FBF52-200K | 1 | 10 $ 0.10 $ | 1.00 https://www.digikey.com/en/products/detail/yageo/MFR-25FBF52-200K/13547
Res 1k | RNF14FTD1K00 | 5 | 10 $ 0.10 $ | 5.00 https://www.digikey.com/en/products/detail/stackpole-electronics-inc/RNF14FTD1K00/1706678
Res 270k | RNMF14FTC270K | 1 | 10 $ 0.10 $ | 1.00 https://www.digikey.com/en/products/detail/stackpole-electronics-inc/RNMF14FTC270K/2617321
Res 100k | RNMF14FTC100K | 2 | 10 $ 0.10 $ | 2.00 https://www.digikey.com/en/products/detail/stackpole-electronics-inc/RNMF14FTC100K/2617278
SD | SD card reader | MEM2051-00-195-00-A | 1 | 5 $ 1.20 $ | 6.00 https://www.digikey.com/en/products/detail/gct/MEM2051-00-195-00-A/10460360
Cap 10uF | CL31A106KPHNNNE | 1 | 10 $ 0.23 $ | 2.30 https://www.digikey.com/en/products/detail/samsung-electro-mechanics/CL31A106KPHNNNE/3886806
Power Switch/Driver | RT9742CNGJ5 | 1 | 5 $ 1.60 $ | 8.00 https://www.digikey.com/en/products/detail/richtek-usa-inc/RT9742CNGJ5/5880513
Res 12k | RNMF14FTC12K0 | 1 | 10 $ 0.10 $ | 1.00 https://www.digikey.com/en/products/detail/stackpole-electronics-inc/RNMF14FTC12K0/2617286
Ethernet | Ethernet port | ARJM11B1-502-AB-ER2-T | 1 | 5 $ 3.94 $ 19.70 https://www.digikey.com/en/products/detail/abracon-llc/ARJM11B1-502-AB-ER2-T/7675202
ESD protection diode | TPD4EUSB30DQAR | 2 | 5 $ 0.83 $ | 8.30 https://www.digikey.com/en/products/detail/texas-instruments/TPD4EUSB30DQAR/2503665
Cap 0.1uF | C1206C104K5RAC7800 | 1 | 10 $ 0.11 $ | 1.10 https://www.digikey.com/en/products/detail/kemet/C1206C104K5RAC7800/411248
Res 470R | RNF14FTD470R | 2 | 10 $ 0.10 $ | 2.00 https://www.digikey.com/en/products/detail/stackpole-electronics-inc/RNF14FTD470R/1682287
USB | USB receptical | USB-A-S-RA | 3 | 5 $ 0.55 $ | 8.25 https://www.digikey.com/en/products/detail/adam-tech/USB-A-S-RA/9832308
FFC 20pin connector | PCA-6-LA-20-HL-3 | 1 | 5 $ 0.42 $ | 2.10 https://www.digikey.com/en/products/detail/adam-tech/PCA-6-LA-20-HL-3/10245157
USB controller | USB2504A-JT | 1 | 5 $ 3.83 $ 19.15 https://www.digikey.com/en/products/detail/microchip-technology/USB2504A-JT/1120711
Res 12k | RNMF14FTC12K0 | 1 | 10 $ 0.10 $ | 1.00 https://www.digikey.com/en/products/detail/stackpole-electronics-inc/RNMF14FTC12K0/2617286
Res 36k | RNMF14FTC36K0 | 4 | 10 $ 0.10 $ | 4.00 https://www.digikey.com/en/products/detail/stackpole-electronics-inc/RNMF14FTC36K0/2617336
Crystal | J49SMH-F-G-G-K-24M0 | 1 | 10 $ 0.21 $ | 2.10 https://www.digikey.com/en/products/detail/jauch-quartz/J49SMH-F-G-G-K-24M0/10416339
Cap 27pf | CL31C270JBCNNNC | 2 | 10 $ 0.18 $ | 3.60 https://www.digikey.com/en/products/detail/samsung-electro-mechanics/CL31C270JBCNNNC/3888484
Cap 10uF | CL31A106KPHNNNE | 2 | 10 $ 0.23 $ | 4.60 https://www.digikey.com/en/products/detail/samsung-electro-mechanics/CL31A106KPHNNNE/3886806
Cap 0.1uF | C1206C104K5RAC7800 | 6 | 10 $ 0.11 $ | 6.60 https://www.digikey.com/en/products/detail/kemet/C1206C104K5RAC7800/411248
Current Limit Switch | AP22653AW6-7 | 1 | 5 $ 0.44 $ | 2.20 https://www.digikey.com/en/products/detail/diodes-incorporated/AP22653AW6-7/12728454 Different Fault condition? Vs AP22653W6-7
Cap 10uF | CL31A106KPHNNNE | 1 | 10 $ 0.23 $ | 2.30 https://www.digikey.com/en/products/detail/samsung-electro-mechanics/CL31A106KPHNNNE/3886806
Res 15k | RNF18FTD15K0 | 1 | 10 $ 0.10 $ | 1.00 https://www.digikey.com/en/products/detail/stackpole-electronics-inc/RNF18FTD15K0/1682787
Cap 100uF | CL32A107MQVNNNE | 1 | 10 $ 0.71 $ | 7.10 https://www.digikey.com/en/products/detail/samsung-electro-mechanics/CL32A107MQVNNNE/3886750
Cap 10uF | CL31A106KPHNNNE | 4 | 10 $ 0.23 $ | 9.20 https://www.digikey.com/en/products/detail/samsung-electro-mechanics/CL31A106KPHNNNE/3886806
HDMI | HDMI port | SS-53000-001 | 1 | 5 $ 0.88 $ | 4.40 https://www.digikey.com/en/products/detail/stewart-connector/SS-53000-001/10492172
FFC 20pin connector | PCA-6-LA-20-HL-3 | 1 | 5 $ 0.42 $ | 2.10 https://www.digikey.com/en/products/detail/adam-tech/PCA-6-LA-20-HL-3/10245157
Power Switch/Driver | RT9742CNGJ5 | 1 | 5 $ 1.60 $ | 8.00 https://www.digikey.com/en/products/detail/richtek-usa-inc/RT9742CNGJ5/5880513 Not interally pulled high? Vs RT9742SNGV
Cap 0.1uF | C1206C104K5RAC7800 | 2 | 10 $ 0.11 $ | 2.20 https://www.digikey.com/en/products/detail/kemet/C1206C104K5RAC7800/411248
Other | LED cm4 Activity | WP7113ND | 1 | 5 $ 0.32 $ | 1.60 https://www.digikey.com/en/products/detail/kingbright/WP7113ND/3084223
Res 1k | RNF14FTD1K00 | 5 | 10 $ 0.10 $ | 5.00 https://www.digikey.com/en/products/detail/stackpole-electronics-inc/RNF14FTD1K00/1706678 for led activity
LED cm4 Power | C5SMF-GJF-CV0Y0791 | 1 | 5 $ 0.19 $ | 0.95 https://www.digikey.com/en/products/detail/cree-inc/C5SMF-GJF-CV0Y0791/4793796
Power diode | 74LVC1G07SE-7 | 1 | 5 $ 0.28 $ | 1.40 https://www.digikey.com/en/products/detail/diodes-incorporated/74LVC1G07SE-7/2356534
Res 1k | RNF14FTD1K00 | 5 | 10 $ 0.10 $ | 5.00 https://www.digikey.com/en/products/detail/stackpole-electronics-inc/RNF14FTD1K00/1706678 for led power

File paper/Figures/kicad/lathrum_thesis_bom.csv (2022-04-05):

Reference | Quantity | Value | Footprint | manf#
B1 | 1 | JST 2-PH | JST\_S2B-PH-K-S(LF)(SN):JST\_S2B-PH-K-S(LF)(SN) | B2B-PH-K-S(LF)(SN)
C1 C3 C6 C8 C10 C11 C19 C20 C21 C22 | 10 | 10uF | Capacitor\_SMD:C\_1206\_3216Metric\_Pad1.33x1.80mm\_HandSolder | CL31B106MOHNNNE
C15 C16 | 2 | 4.7uF | Capacitor\_SMD:C\_1206\_3216Metric\_Pad1.33x1.80mm\_HandSolder | CL31B475KAHNFNE
C17 C18 | 2 | 27pF | Capacitor\_SMD:C\_1206\_3216Metric\_Pad1.33x1.80mm\_HandSolder | C1206C270K5GAC7800
C2 C7 C9 C12 C13 C14 | 6 | 0.1uF | Capacitor\_SMD:C\_1206\_3216Metric\_Pad1.33x1.80mm\_HandSolder | CL31B104KBCNFNC
C4 | 1 | 2.2uF | Capacitor\_SMD:C\_1206\_3216Metric\_Pad1.33x1.80mm\_HandSolder | CL31B225KOHNNNE
C5 C23 | 2 | 100uF | Capacitor\_SMD:C\_1206\_3216Metric\_Pad1.33x1.80mm\_HandSolder | GRM31CR60G107ME39L
D1 D2 D6 | 3 | Red | LED\_SMD:LED\_1206\_3216Metric\_Pad1.42x1.75mm\_HandSolder | 156120RS75300
D3 D5 | 2 | Green | LED\_SMD:LED\_1206\_3216Metric\_Pad1.42x1.75mm\_HandSolder | 150120GS75000
D4 | 1 | Orange | LED\_SMD:LED\_1206\_3216Metric\_Pad1.42x1.75mm\_HandSolder | 150120AS75000
J1 | 1 | USB4125-GF-A\_REVA2 | USB4125-GF-A\_REVA2:GCT\_USB4125-GF-A\_REVA2 | USB4125-GF-A
J2 | 1 | PREC002SAAN-RC | PREC002SAAN-RC:PREC002SAAN-RC | PREC002SAAN-RC
J3 | 1 | SS-53000-001 | SS-53000-001:STEWART\_SS-53000-001 | SS-53000-001
J4 J10 | 2 | FFC3B07-20-T | FFC3B07-20-T:GCT\_FFC3B07-20-T | FFC3B07-20-T
J5 | 1 | Micro\_SD\_Card\_Det | CM4IO:SDCARD\_MOLEX\_503398-1892 | 5033981892
J6 | 1 | ARJM11D7-502-AB-EW2 | ARJM11D7-502-AB-EW2:ARJM11D7502ABEW2 | ARJM11D7-502-AB-EW2
J7 J8 J9 | 3 | SS-52100-001 | SS-52100-001:SS-52100-001 | SS-52100-001
L1 | 1 | 6.8uH | NRS5030T6R8MMGJ:NRS5030T6R8MMGJ | NRS5030T6R8MMGJ
Module1 | 1 | ComputeModule4-CM4 | CM4IO:Raspberry-Pi-4-Compute-Module | CM4104000
Q1 | 1 | MMUN2133LT1G | MMUN2133LT1G:SOT95P240X111-3N | MMUN2133LT1G
R1 R7 | 2 | 1.87M | Resistor\_SMD:R\_1206\_3216Metric\_Pad1.30x1.75mm\_HandSolder | RC1206FR-071M87L
R10 | 1 | 15K | Resistor\_SMD:R\_1206\_3216Metric\_Pad1.30x1.75mm\_HandSolder | RC1206FR-0715KL
R13 | 1 | 270K | Resistor\_SMD:R\_1206\_3216Metric\_Pad1.30x1.75mm\_HandSolder | RC1206FR-07270KL
R18 R24 | 2 | 12K 1\% | Resistor\_SMD:R\_1206\_3216Metric\_Pad1.30x1.75mm\_HandSolder | RC1206FR-0712KL
R2 | 1 | 340K | Resistor\_SMD:R\_1206\_3216Metric\_Pad1.30x1.75mm\_HandSolder | ERJ-8ENF3403V
R20 R21 | 2 | 470R | Resistor\_SMD:R\_1206\_3216Metric\_Pad1.30x1.75mm\_HandSolder | RC1206FR-07470RL
R22 R23 | 2 | 36K 1\% | Resistor\_SMD:R\_1206\_3216Metric\_Pad1.30x1.75mm\_HandSolder | RC1206FR-0736KL
R25 | 1 | 15K 1\% | Resistor\_SMD:R\_1206\_3216Metric\_Pad1.30x1.75mm\_HandSolder | RC1206FR-0715KL
R3 R4 | 2 | 5.1K | Resistor\_SMD:R\_1206\_3216Metric\_Pad1.30x1.75mm\_HandSolder | RMCF1206FT5K10
R5 R8 | 2 | 200K | Resistor\_SMD:R\_1206\_3216Metric\_Pad1.30x1.75mm\_HandSolder | RC1206FR-07200KL
R6 R12 R14 R15 R16 R17 R19 | 7 | 1K | Resistor\_SMD:R\_1206\_3216Metric\_Pad1.30x1.75mm\_HandSolder | RC1206FR-071KL
R9 R11 | 2 | 100K | Resistor\_SMD:R\_1206\_3216Metric\_Pad1.30x1.75mm\_HandSolder | RMCF1206FT100K
U1 | 1 | TPS61090RSAR | TPS61090RSAR:QFN65P400X400X100-17N | TPS61090RSAR
U2 | 1 | MCP73871-2CCI\_ML | digikey-footprints:QFN-20-1EP\_4x4mm | MCP73871-2CCI/ML
U3 | 1 | 74LVC1G07 | Package\_TO\_SOT\_SMD:SOT-353\_SC-70-5 | 74LVC1G07SE-7
U4 | 1 | RT9742VGJ5 | Package\_TO\_SOT\_SMD:SOT-23-5 | RT9742VGJ5
U5 | 1 | RT9742ENGJ5 | Package\_TO\_SOT\_SMD:SOT-23-5 | RT9742ENGJ5
U6 U7 | 2 | TPD4EUSB30 | Package\_SON:USON-10\_2.5x1.0mm\_P0.5mm | TPD4EUSB30DQAR
U8 | 1 | USB2504A-JT | USB2504A-JT:USB2504A-JT | USB2504A-JT
U9 | 1 | AP22653W6-7 | AP22653W6-7:SOT95P280X145-6N | AP22653W6-7
Y1 | 1 | 24MHz | Crystal:Crystal\_SMD\_HC49-SD | FC4SDCBMF24.0-T1

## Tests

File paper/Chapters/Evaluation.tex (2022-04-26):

\chapter{Evaluation}

\label{Chapter6}

In order to evaluate the performance of the forked version of Moonlight developed for this paper, it must be tested against the other existing solutions.
The testing methodology employed to ensure the accuracy of the testing is described in Section \ref{sec:TestingMethodology}.
Then, the responsivity and latency of each solution is evaluated in Section \ref{sec:ResponsivityAndLatency}, and the quality of each solution's stream is evaluated in Section \ref{sec:Quality}.
Then, the forked version of Moonlight is evaluated in real world scenarios in Section \ref{sec:RealWorldTesting}.
Finally, the results are summarized and verdicts on each of the solutions' applicability to the research questions will be presented in Section \ref{sec:EvaluationSummary}.

\section{Testing Methodology}\label{sec:TestingMethodology}

In order to ensure that the data collected for analysis is accurate and directly comparable, the testing environment must be kept exactly the same between trials and between different applications.
This gives each application the exact same starting conditions, and the best chance to demonstrate it's unabated performance.
For these tests, the host machine is a desktop computer running Windows 10 with a AMD Ryzen 9 5900X CPU and a Nvidia RTX 3070 GPU running the latest GeForce Experience version \emph{3.25.0.84}.
This configuration does not change throughout testing.
The client machine is the CM4 board attached to the PCB developed in Chapter \ref{Chapter4}, running the custom Manjaro linux distribution and forked version of Moonlight developed in Chapter \ref{Chapter5}.
This configuration also does not change throughout testing.
Each test is performed with both the host computer and the client machine running on the same network, with both devices connected to the same router using an ethernet cable.
This ensures that the speed of the network is not a factor in the tests.
The tests are performed multiple times under the following conditions:

\begin{itemize}
  \item Ideal Conditions: No other applications are running during testing.
  \item CPU Stressed: The CPU is constantly at 100\% load during the entire test.
  \item GPU Stressed: The GPU is constantly at 100\% load during the entire test.
  \item Both Stressed: Both the CPU and the GPU are constantly at 100\% load during the entire test.
\end{itemize}

\noindent
This is to examine whether each application can perform under intensive conditions.
For each test, the following steps are performed:

\begin{enumerate}
  \item Both the host and client computers are fully rebooted to ensure no other application is running.
  \item The host computer starts up a single browser window with the web page described in Section \ref{sec:DevelopingTestingAndMeasurementTools}.
  \item If the test calls for the CPU or the GPU to be stressed, the application \enquote{Blender} is started on the host machine, and a benchmark is performed for the CPU or the GPU.
        This benchmark will run for longer than the duration of the test, and will keep the CPU and/or GPU at 100\% load for the entire duration of the benchmark.
  \item Both devices start up their respective data collection tool that will record keystrokes and changes in the screen's color.
  \item The client machine connects to the host computer using the application being tested.
  \item The tester presses the \enquote{=} key on the client machine to begin the automated testing process.
        Due to the wide variance in what the user can do using the software, it is nearly impossible to test every possible real world scenario.
        Instead, the automated test simulates an active working environment by sending a repeatable series of keystrokes that cause the entire screen to change colors to mimic high-intensity applications.
        For consistent testing, 400 keystrokes are automatically sent with a 500ms delay between inputs.
  \item Once the trial is complete, both the client and the host computers close their data recording tools and the client ends the streaming session.
\end{enumerate}

\noindent
This process is repeated for each of the following applications:

\begin{itemize}
  \item The forked version of Moonlight developed for this project.
  \item Chrome Remote Desktop (CRD, Section \ref{subsec:ChromeRemoteDesktop}).
  \item Microsoft's Remote Desktop Connection (RDP, Section \ref{subsec:RemoteDesktopProtocol}).
  \item Virtual Network Computing (VNC, Section \ref{subsec:VirtualNetworkComputing}).
\end{itemize}

\noindent
Once all the data is collected, the data from the host and client machines for a single trial are organized into a single CSV file for processing.
In order to ensure that the data is comparable, all extraneous factors must be removed from the data.
Namely, the network latency and difference in computer clocks must be removed.
By keeping the host and client computers attached to the same network through ethernet, the network latency is minimized.
But the task of keeping two computer's internal clocks synchronized is not trivial.

\begin{figure}[h]
  \startchronology[startyear=0,stopyear=10, height=0pt, dates=false, arrow=false, box=true]
  \chronograduation[event][dateselevation=0pt]{11}

  \chronoevent[date=false]{2}{Key is pressed on client}
  \chronoevent[date=false,markdepth=35pt]{6}{Key is received by host}
  \chronoevent[date=false]{8}{Key is pressed on host}

  \chronoperiode[textstyle=\raggedleft\colorbox{cyan!50}, color=cyan, startdate=false, bottomdepth=5pt, topheight=10pt, textdepth=-15pt,stopdate=false]{2}{6}{Network Latency}
  \chronoperiode[textstyle=\colorbox{green!50}, color=green, startdate=false, bottomdepth=5pt, topheight=10pt, textdepth=-15pt,stopdate=false]{6}{8}{Application Latency}
  \chronoperiode[textstyle=\colorbox{orange!50}, color=orange, startdate=false, bottomdepth=0pt, topheight=5pt, textdepth=-40pt,stopdate=false]{2}{8}{Total Latency}

  \stopchronology
  \caption[Timeline of a keystroke event]{Timeline of a keystroke event}
  \label{fig:KeystrokeTimeline}
\end{figure}

Even after instructing the operating system to synchronize its clock with an internet time server, the two computers may still report different times.
In some cases, the difference between the host and client computer's system time was noticed to be upwards of a full second after resynchronizing both clocks \cite{time.is}.
This is partially accounted for in step \emph{6} of the above process, but the remaining inaccuracy must be subtracted away.
Figure \ref{fig:KeystrokeTimeline} shows the timeline of a single keystroke event; after the client presses a key, it must first be sent and received by the host computer, and then the host must execute that input.
The time that this process takes is the total latency of the input.
For the purposes of evaluating the different applications, this delay must be split into the time it takes for the host to receive the input, called the network latency, and the time it takes for the host to actually execute the input, called the application latency.
Because the data loggers record the exact time that the test begins on both the client and host machines, the two times can be subtracted from each other to determine the network latency at the beginning of the test.
After recording the data, the total latency of each input recorded by the data loggers is subtracted by this value so that the time remaining is the application latency.
This ensures a fair and consistent comparison between each of the applications so that any inaccuracies in each computer's internal clock or the network speed has no impact on the data, and the only delay is that which is introduced by the application itself.

After the data is cleaned up, the data can be processed by matching each keystroke and change in the screen's color detected by the client and host machines and calculating how much time elapsed between the events.
This reveals the amount of delay the user experiences between when they press a key and when the host executes the command, and between when they press a key and can visually see the response.

\section{Responsivity and Latency}\label{sec:ResponsivityAndLatency}

The first factor in determining the performance of the application is to take a look at how responsive it is to use.
Responsivity is defined as how quick the application responds to inputs and how quickly the user can see the results of their inputs.
This is important for general user experience and applications where continuous input is required.
This is also what is generally referred to when determining whether an application has a positive user experience, since a program that can take seconds to respond to the user begets lower productivity and a more frustrating experience.
To analyze this, two points of data are recorded: First, the amount of time between when the client records a keystroke and when it is actually inputted on the host machine, and secondly, the amount of time between the host machine updating their screen and when the client actually displays that update.
The first datum is generally referred to as the latency of the application, since even though each trial is done using the same network setup different solutions may have different optimizations built in that reduce the time needed for the host to implement keystrokes made by the client.
This means that as the network delay is removed from the data, all that is left is the time that it takes the software on the host's machine to actually execute the input.
Each of the following figures shows data over one trial for each category.
Each trial consists of the client machine programmatically sending 400 keystrokes with 500ms between each input.
Limitations in this data is discussed in Section \ref{sec:ConclusionLimitations}.
\begin{figure}[h]
  \centering
  \begin{tikzpicture}
    \begin{axis}[
        boxplot/draw direction=y,
        ylabel={Time (ms)},
        scale only axis,
        height=8cm,
        width=\textwidth,
        ymin=0,ymax=200,
        cycle list={{green!70!black},{red},{blue},{black}},
        legend style={
            legend pos=outer north east,
            font=\small
          },
        legend cell align=left,
        legend image code/.code={%
            \draw[#1] (0cm,-0.1cm) rectangle (0.6cm,0.1cm);
          },
        boxplot={
            % Three boxplots for each column
            draw position={1/5 + floor(\plotnumofactualtype/4) + 1/5*fpumod(\plotnumofactualtype,4)},
            % Each plot takes up a 15% of the column
            box extend=0.15,
          },
        % 1 unit in x controls the width:
        x=2cm,
        % ... and it means that we should describe intervals:
        xtick={0,1,2,...,10},
        x tick label as interval,
        xticklabels={%
            {Forked Moonlight},%
            {CRD},%
            {RDP},%
            {VNC},%
          },
        x tick label style={
            text width=2.5cm,
            align=center
          },
      ]

      % Forked Moonlight
      \addplot
      table[x expr=\coordindex+1, y index=0] {Data/ideal/moonlight_key_delay.csv};
      \addplot
      table[x expr=\coordindex+1, y index=0] {Data/stresscpu/moonlight_key_delay.csv};
      \addplot
      table[x expr=\coordindex+1, y index=0] {Data/stressgpu/moonlight_key_delay.csv};
      \addplot
      table[x expr=\coordindex+1, y index=0] {Data/stressboth/moonlight_key_delay.csv};

      % CRD
      \addplot
      table[x expr=\coordindex+1, y index=0] {Data/ideal/crd_key_delay.csv};
      \addplot
      table[x expr=\coordindex+1, y index=0] {Data/stresscpu/crd_key_delay.csv};
      \addplot
      table[x expr=\coordindex+1, y index=0] {Data/stressgpu/crd_key_delay.csv};
      \addplot
      table[x expr=\coordindex+1, y index=0] {Data/stressboth/crd_key_delay.csv};

      % RDP
      \addplot
      table[x expr=\coordindex+1, y index=0] {Data/ideal/rdp_key_delay.csv};
      \addplot
      table[x expr=\coordindex+1, y index=0] {Data/stresscpu/rdp_key_delay.csv};
      \addplot
      table[x expr=\coordindex+1, y index=0] {Data/stressgpu/rdp_key_delay.csv};
      \addplot
      table[x expr=\coordindex+1, y index=0] {Data/stressboth/rdp_key_delay.csv};

      % VNC
      \addplot
      table[x expr=\coordindex+1, y index=0] {Data/ideal/vnc_key_delay.csv};
      \addplot
      table[x expr=\coordindex+1, y index=0] {Data/stresscpu/vnc_key_delay.csv};
      \addplot
      table[x expr=\coordindex+1, y index=0] {Data/stressgpu/vnc_key_delay.csv};
      \addplot
      table[x expr=\coordindex+1, y index=0] {Data/stressboth/vnc_key_delay.csv};

      \legend{Ideal,CPU stressed,GPU stressed, Both stressed}
    \end{axis}
  \end{tikzpicture}
  \caption[Input Delay Data]{Time for host to press key from client. n=400.}
  \label{fig:InputDelay}
\end{figure}
Figure \ref{fig:InputDelay} shows the amount of time between the client and the host registering the keystroke under the different test conditions.

Each application does a good job sending data from the client to the host in a timely manner, with the majority of keystrokes being realized within a tenth of a second of being pressed on the client machine.
The forked Moonlight implementation keeps a latency under 20ms regardless of the load of the host machine, with more than 75\% of all keystrokes being realized within 10ms.
CRD proves to be a CPU limited application, with latency while idle or under GPU load also staying below 20ms, but climbing up above 50ms when under CPU load.
This is important to keep in mind when thinking about what sort of situations the host machine will be in while being accessed.
If the user is going to be rendering video remotely, a GPU intensive process, the latency of the stream wont be impacted, but if the user is going to be running a CPU intensive process, the latency can be expected to be negatively impacted.
RDP has a similar results, with extremely low latency while idle or under GPU load, and upwards of 40ms while under CPU load.
VNC has the highest variance, with no discernable affinity to any kind of load.
This lines up with it's intended use described in Section \ref{subsec:VirtualNetworkComputing}, being the simplest and most straightforward method of remote desktop control without much focus on performance or security.
That's not so say VNC is unusable or even difficult to use; latency of 140ms is still usable in all but the most precise situations.

Though this is only one metric to consider, the other is the amount of time it take for the client to display the results of their input.
This is recorded as the amount of time it takes between the host machine changing the color of it's screen and the client rendering the change.
As noted before, the color of the host's screen changes with each input sent by the client, which occurs every 500ms for 400 keystrokes.
Figure \ref{fig:ColorDelay} shows the amount of time for each application under each condition.

\begin{figure}[h]
  \centering
  \begin{tikzpicture}
    \begin{axis}[
        boxplot/draw direction=y,
        ylabel={Time (ms)},
        scale only axis,
        height=8cm,
        width=\textwidth,
        ymin=0,ymax=250,
        cycle list={{green!70!black},{red},{blue},{black}},
        legend style={
            legend pos=outer north east,
            font=\small
          },
        legend cell align=left,
        legend image code/.code={%
            \draw[#1] (0cm,-0.1cm) rectangle (0.6cm,0.1cm);
          },
        boxplot={
            % Three boxplots for each column
            draw position={1/5 + floor(\plotnumofactualtype/4) + 1/5*fpumod(\plotnumofactualtype,4)},
            % Each plot takes up a 15% of the column
            box extend=0.15,
          },
        % 1 unit in x controls the width:
        x=2cm,
        % ... and it means that we should describe intervals:
        xtick={0,1,2,...,10},
        x tick label as interval,
        xticklabels={%
            {Forked Moonlight},%
            {CRD},%
            {RDP},%
            {VNC},%
          },
        x tick label style={
            text width=2.5cm,
            align=center
          },
      ]

      % Forked Moonlight
      \addplot
      table[x expr=\coordindex+1, y index=0] {Data/ideal/moonlight_color_delay.csv};
      \addplot
      table[x expr=\coordindex+1, y index=0] {Data/stresscpu/moonlight_color_delay.csv};
      \addplot
      table[x expr=\coordindex+1, y index=0] {Data/stressgpu/moonlight_color_delay.csv};
      \addplot
      table[x expr=\coordindex+1, y index=0] {Data/stressboth/moonlight_color_delay.csv};

      % CRD
      \addplot
      table[x expr=\coordindex+1, y index=0] {Data/ideal/crd_color_delay.csv};
      \addplot
      table[x expr=\coordindex+1, y index=0] {Data/stresscpu/crd_color_delay.csv};
      \addplot
      table[x expr=\coordindex+1, y index=0] {Data/stressgpu/crd_color_delay.csv};
      \addplot
      table[x expr=\coordindex+1, y index=0] {Data/stressboth/crd_color_delay.csv};

      % RDP
      \addplot
      table[x expr=\coordindex+1, y index=0] {Data/ideal/rdp_color_delay.csv};
      \addplot
      table[x expr=\coordindex+1, y index=0] {Data/stresscpu/rdp_color_delay.csv};
      \addplot
      table[x expr=\coordindex+1, y index=0] {Data/stressgpu/rdp_color_delay.csv};
      \addplot
      table[x expr=\coordindex+1, y index=0] {Data/stressboth/rdp_color_delay.csv};

      % VNC
      \addplot
      table[x expr=\coordindex+1, y index=0] {Data/ideal/vnc_color_delay.csv};
      \addplot
      table[x expr=\coordindex+1, y index=0] {Data/stresscpu/vnc_color_delay.csv};
      \addplot
      table[x expr=\coordindex+1, y index=0] {Data/stressgpu/vnc_color_delay.csv};
      \addplot
      table[x expr=\coordindex+1, y index=0] {Data/stressboth/vnc_color_delay.csv};

      \legend{Ideal,CPU stressed,GPU stressed,Both stressed}
    \end{axis}
  \end{tikzpicture}
  \caption[Color Delay Data]{Time for client to render update to the screen. Values over 250ms indicate a poorly performing system. n=400.}
  \label{fig:ColorDelay}
\end{figure}

This data demonstrates a similar but more extreme pattern to the input delay figure, with most application performing well under ideal conditions but struggling a little under high stress.
The forked Moonlight implementation is able to render updates on the client device in under 70ms in nearly all cases, with an even spread regardless of the load of the host machine.
CRD is able to render all updates in under 160ms while the host is idle, but struggles to keep up while under load.
Again, CRD struggles the most while under CPU load, with the quickest update happening in just under 180ms, and the median update taking over a full second.
CRD performs a little better under GPU load, but still experiences much high delays with the median update taking over half of a second.
Once both the CPU and the GPU are under load, the worst of both scenarios is realized as the median update taking nearly three quarters of a second.
All three of these values push the usability of the system as any kind of intensive program will bring the responsivity of the application to a crawl.
RDP again performs extremely well, with all render updates taking less than 50ms while under ideal conditions or GPU load, and all updates taking less that 70ms while under full CPU load.
VNC is again the slowest and most inconsistent application, with all conditions resulting in a frequent render delays of more than a quarter of a second.
This makes VNC considerably less suitable for the task at hand.

The delay, however, is only half the story in this case.
Another factor to consider is the percentage of updates that are not rendered by the client.
This, often referred to as dropped frames, records how much data is lost when the host sends it's screen to the client device.
A higher percentage results in a more choppy and difficult to use experience, with a 50\% loss meaning that 50\% of the updates sent by the host are not rendered by the client.
Figure \ref{fig:ColorDelayLoss} shows the percentage of color changes not rendered by the client for each of the load conditions.

\begin{figure}[h]
  \centering
  \begin{tikzpicture}
    \begin{axis}[
        ylabel={Color changes not rendered (\%)},
        scale only axis,
        height=8cm,
        width=\textwidth,
        enlarge x limits=0.25,
        ybar=2*\pgflinewidth,
        bar width=14pt,
        ymin=0,ymax=100,
        cycle list={{green!70!black},{red},{blue},{black}},
        legend style={
            legend pos=outer north east,
            font=\small
          },
        legend cell align=left,
        legend image code/.code={%
            \draw[#1] (0cm,-0.1cm) rectangle (0.6cm,0.1cm);
          },
        % 1 unit in x controls the width:
        x=2cm,
        % ... and it means that we should describe intervals:
        xtick={0,1,2,...,10},
        % x tick label as interval,
        xticklabels={%
            {Forked Moonlight},%
            {CRD},%
            {RDP},%
            {VNC},%
          },
        x tick label style={
            text width=2.5cm,
            align=center
          },
      ]

      \addplot[style={green!70!black,fill=green!70!black,mark=none}]
      coordinates {(0, 0) (1,0) (2,0) (3,15.32)};

      \addplot[style={red,fill=red,mark=none}]
      coordinates {(0,0) (1,32.28) (2,0) (3,19.51)};

      \addplot[style={blue,fill=blue,mark=none}]
      coordinates {(0,0) (1,2.34) (2,0) (3,15.5)};

      \addplot[style={black,fill=black,mark=none}]
      coordinates {(0, 0) (1,34.65) (2,0) (3,39.83)};

      \legend{Ideal,CPU stressed,GPU stressed, Both stressed}
    \end{axis}
  \end{tikzpicture}
  \caption[Color Delay Loss Data]{Percentage of color changes not rendered. n=400.}
  \label{fig:ColorDelayLoss}
\end{figure}

These data points adds context to the previous figures, showing where the applications struggle to keep up with sending data back to the client device.
The forked Moonlight implementation does not experience any frame drops, as does CRD under ideal conditions.
But once the host machine is put under heavy load, CRD begins to drop frames, with a few being dropped under GPU stress, and 32\% of frames being dropped while under CPU stress.
This can make CRD unpleasant and frustrating to use while the host is running a CPU intensive program as not only does the client take much more time to update the screen to reflect that status of the host computer, but many of the updates are lost completely and not shown to the user.
RDP is also able to display all the data sent by the host without dropping any frames under any condition.
VNC is again proved to be the least performant, with frames being dropped regardless of the load being put on the host computer.
This is still in line with it's intended use of basic remote control, though it is disappointing to see about 15\% loss even under ideal conditions.

\section{Quality}\label{sec:Quality}

Apart from the performance of each application, the quality of the user experience must also be taken into account when considering each application.
Each application will be assessed individually, and then compared in Section \ref{sec:EvaluationSummary}.
Due to the closed nature of some of the protocols, only limited amounts of data could be extracted and compared.
This prevents direct comparisons, but can still contribute to the understanding of the overall performance of the solution.

\subsection{Moonlight}\label{subsec:QualityMoonlight}

When analyzing the forked version of Moonlight, specific quantitative data described in Section \ref{sec:DevelopingTestingAndMeasurementTools} can be collected directly from the application while it is running.
Once the streaming session concludes, the statistics are collated into human-readable numbers and presented in the console.
What follows is an example output from one of the test streaming sessions:
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

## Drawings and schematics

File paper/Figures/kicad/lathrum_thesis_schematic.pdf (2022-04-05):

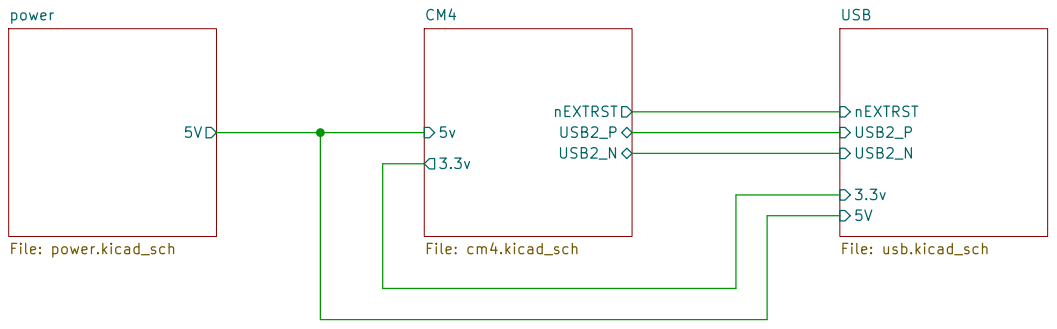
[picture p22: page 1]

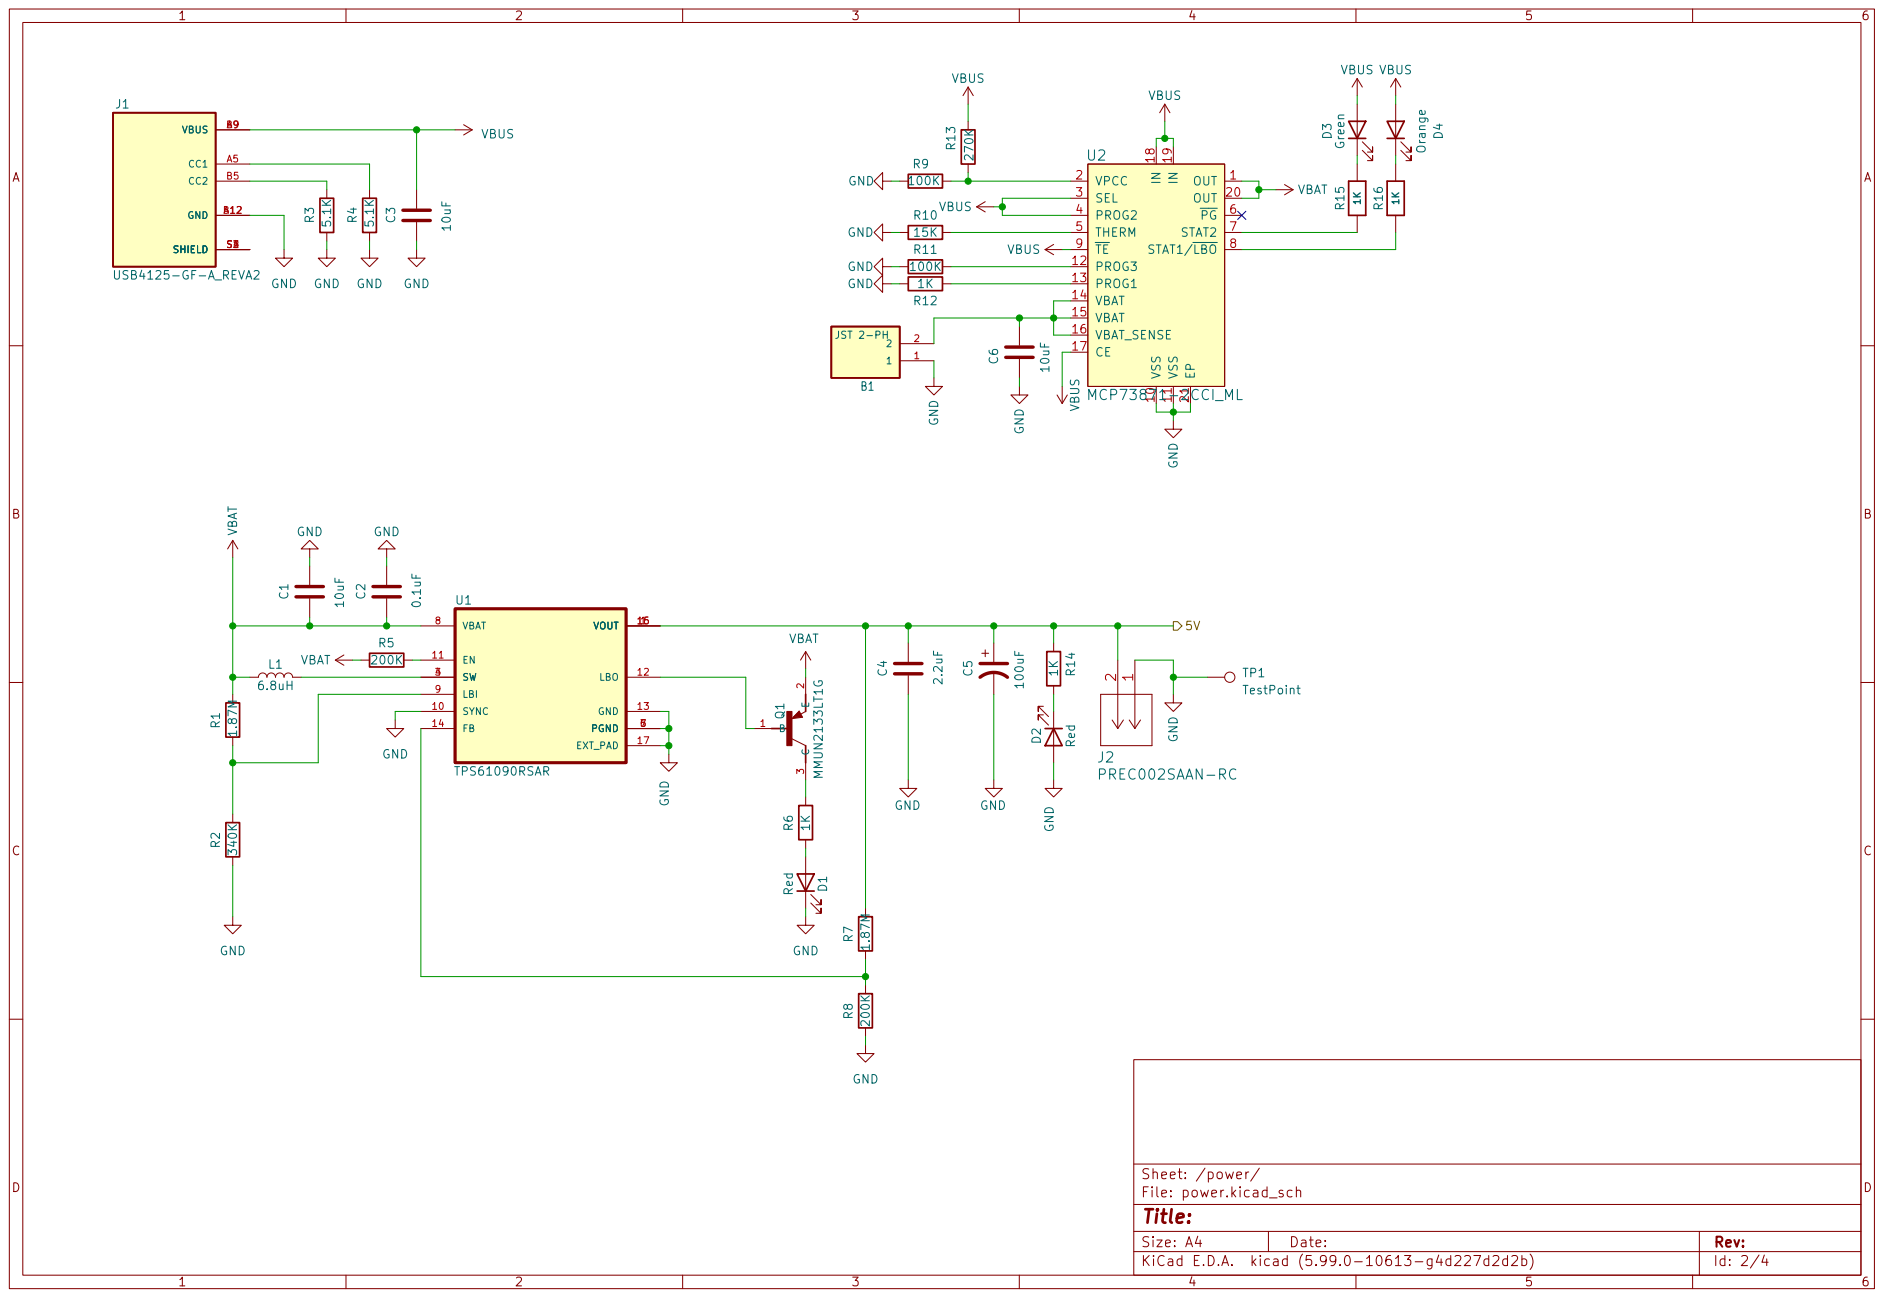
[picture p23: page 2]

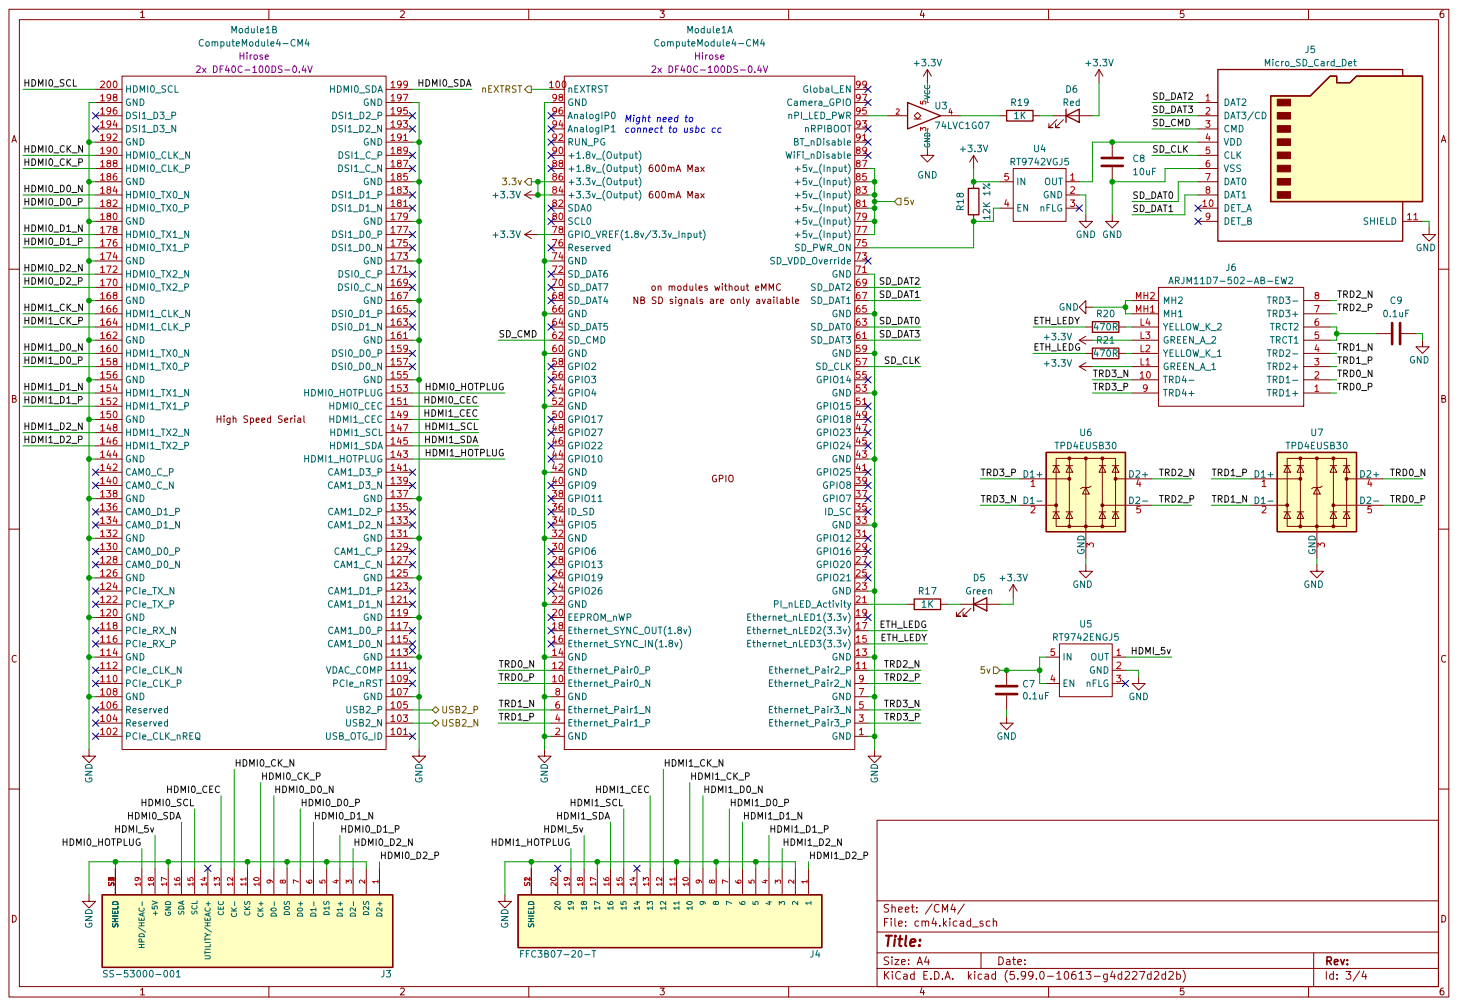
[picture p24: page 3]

connect to usbc cc

600mA Max 600mA Max NB SD signals are only available

1 CK+ 10 CKS 11 CK- 12 CEC 13 UTILITY/HEAC+ 14 SCL 15 SDA 16 GND 17 +5V 18 HPD/HEAC- 19 D2S

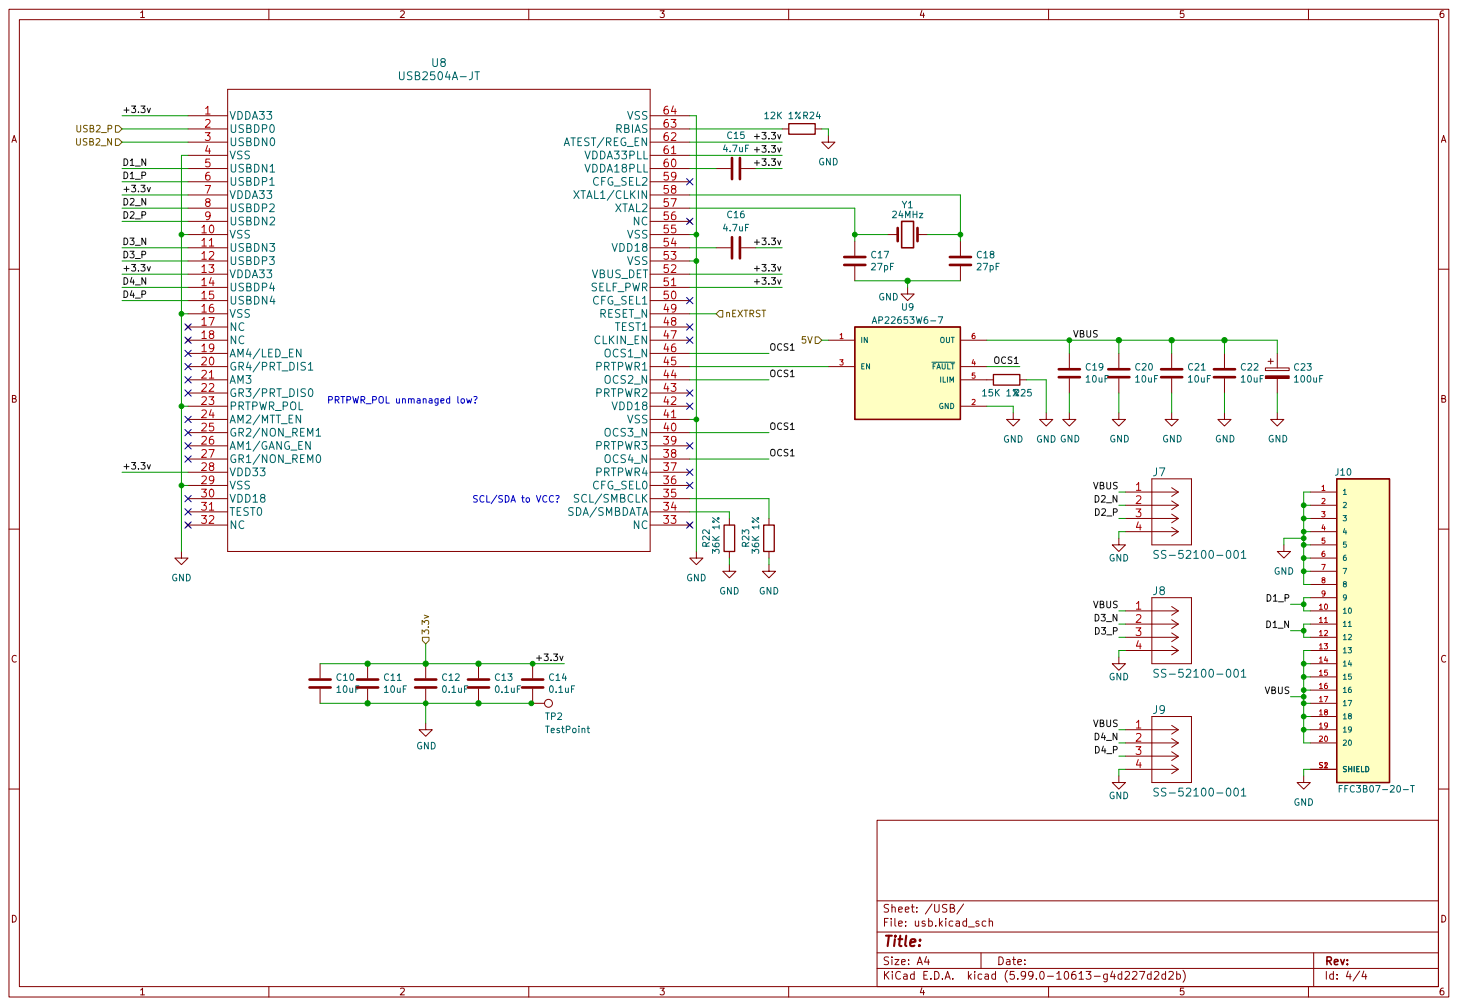
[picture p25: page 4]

PRTPWR_POL unmanaged low? SCL/SDA to VCC?

File: usb.kicad_sch Sheet: /USB/ C14

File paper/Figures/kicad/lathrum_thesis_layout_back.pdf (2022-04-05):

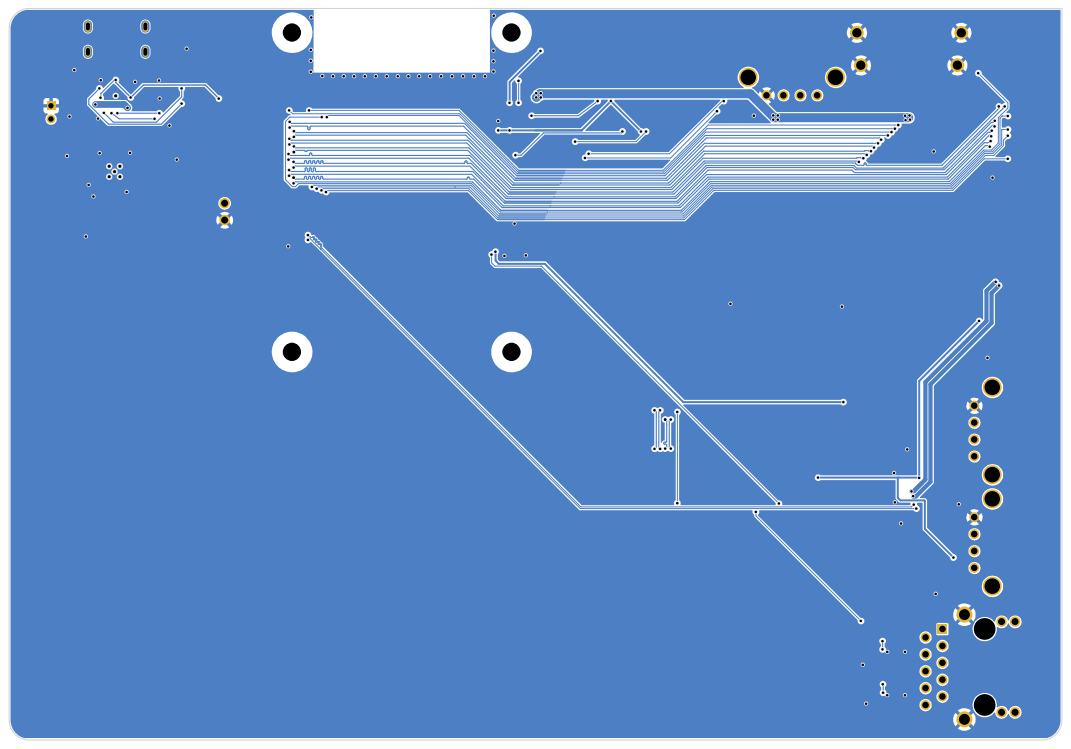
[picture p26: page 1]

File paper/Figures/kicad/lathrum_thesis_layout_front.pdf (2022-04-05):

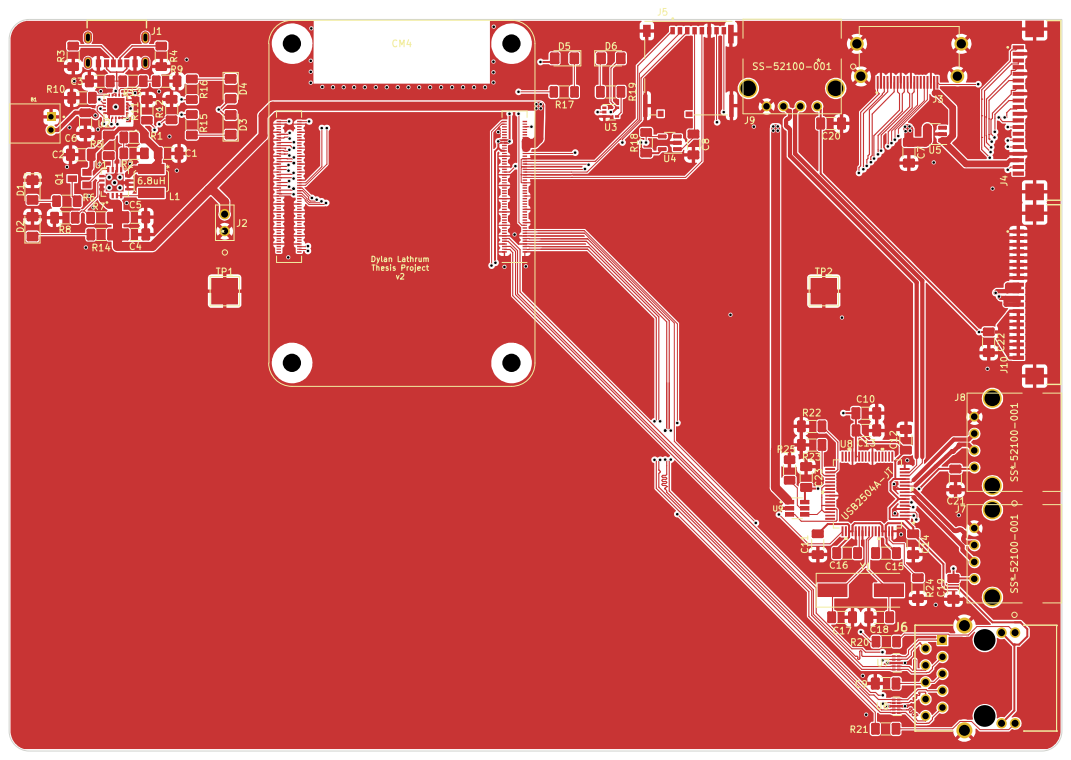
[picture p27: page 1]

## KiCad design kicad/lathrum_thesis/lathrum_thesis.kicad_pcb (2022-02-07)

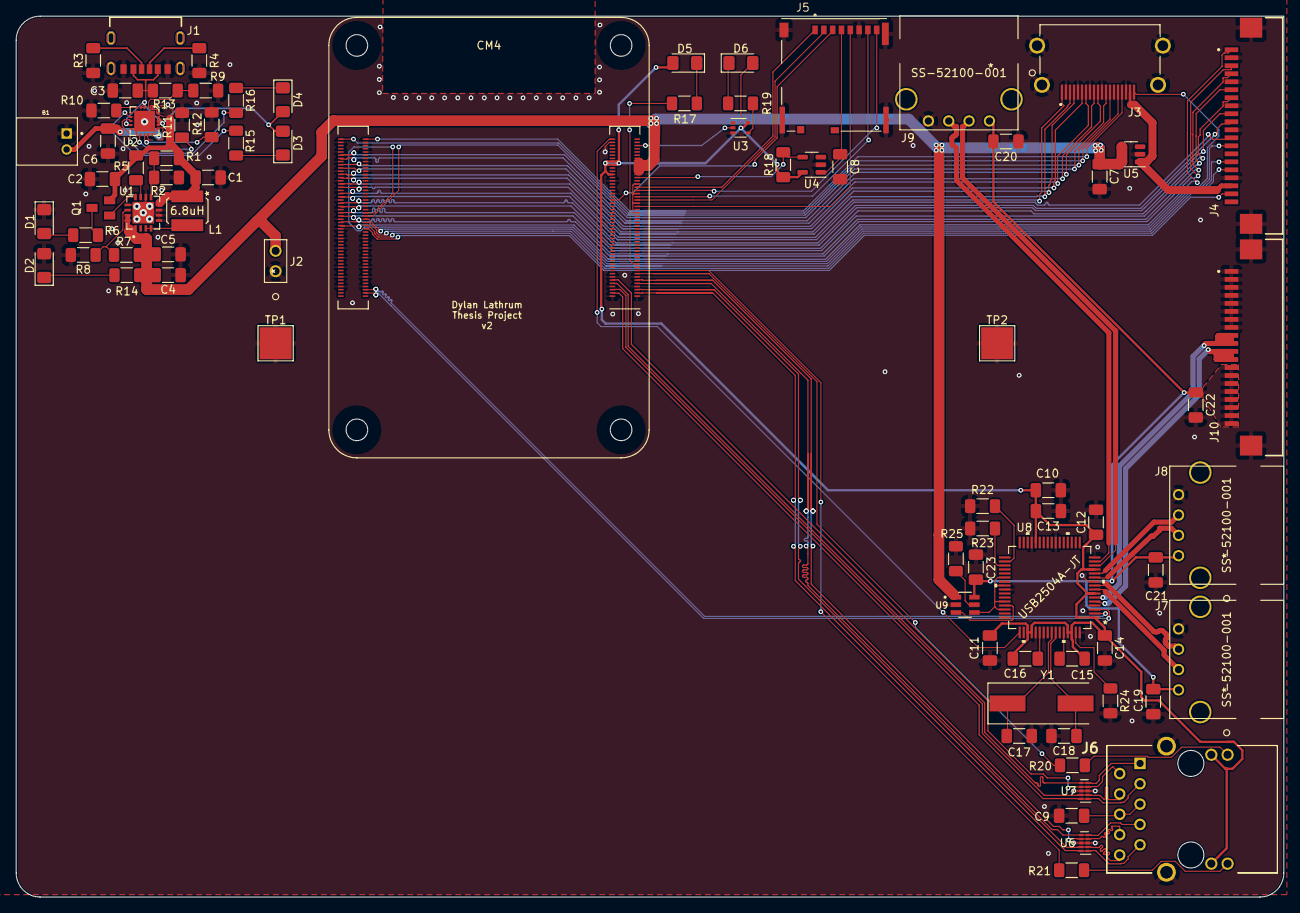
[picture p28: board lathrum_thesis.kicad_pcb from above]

Board: 2 copper layers, 158.3 x 110.0 mm, 80 parts (0 on the bottom side), 98 nets.

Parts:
B1: JST 2-PH; JST_S2B-PH-K-S(LF)(SN)
C1, C3, C6: 10uF; C_1206_3216Metric_Pad1.33x1.80mm_HandSolder
C2: 0.1uF; C_1206_3216Metric_Pad1.33x1.80mm_HandSolder
C4: 2.2uF; C_1206_3216Metric_Pad1.33x1.80mm_HandSolder
C5, C23: 100uF; C_1206_3216Metric_Pad1.33x1.80mm_HandSolder
C7, C9, C12, C13, C14: 100n; C_1206_3216Metric_Pad1.33x1.80mm_HandSolder
C8, C10, C11, C19, C20, C21, C22: 10u; C_1206_3216Metric_Pad1.33x1.80mm_HandSolder
C15, C16: 4.7uF; C_1206_3216Metric_Pad1.33x1.80mm_HandSolder
C17, C18: 27pF; C_1206_3216Metric_Pad1.33x1.80mm_HandSolder
CM4: ComputeModule4-CM4; Raspberry-Pi-4-Compute-Module
D1, D2, D6: Red; LED_1206_3216Metric_Pad1.42x1.75mm_HandSolder
D3, D5: Green; LED_1206_3216Metric_Pad1.42x1.75mm_HandSolder
D4: Orange; LED_1206_3216Metric_Pad1.42x1.75mm_HandSolder
J1: USB4125-GF-A_REVA2; GCT_USB4125-GF-A_REVA2
J2: PREC002SAAN-RC
J3: SS-53000-001; STEWART_SS-53000-001
J4, J10: FFC3B07-20-T; GCT_FFC3B07-20-T
J5: Micro_SD_Card_Det; SDCARD_MOLEX_503398-1892
J6: ARJM11D7-502-AB-EW2; ARJM11D7502ABEW2
J7, J8, J9: SS-52100-001
L1: 6.8uH; NRS5030T6R8MMGJ
Q1: MMUN2133LT1G; SOT95P240X111-3N
R1, R7: 1.87M; R_1206_3216Metric_Pad1.30x1.75mm_HandSolder
R2: 340k; R_1206_3216Metric_Pad1.30x1.75mm_HandSolder
R3, R4: 5.1k; R_1206_3216Metric_Pad1.30x1.75mm_HandSolder
R5, R8: 200k; R_1206_3216Metric_Pad1.30x1.75mm_HandSolder
R6, R14, R17, R19: 1k; R_1206_3216Metric_Pad1.30x1.75mm_HandSolder
R9, R11: 100k; R_1206_3216Metric_Pad1.30x1.75mm_HandSolder
R10: 15k; R_1206_3216Metric_Pad1.30x1.75mm_HandSolder
R12: 1.0k; R_1206_3216Metric_Pad1.30x1.75mm_HandSolder
R13: 270k; R_1206_3216Metric_Pad1.30x1.75mm_HandSolder
R15, R16: 1K; R_1206_3216Metric_Pad1.30x1.75mm_HandSolder
R18: 12k 1%; R_1206_3216Metric_Pad1.30x1.75mm_HandSolder
R20, R21: 470R; R_1206_3216Metric_Pad1.30x1.75mm_HandSolder
R22, R23: 36K 1%; R_1206_3216Metric_Pad1.30x1.75mm_HandSolder
R24: 12K 1%; R_1206_3216Metric_Pad1.30x1.75mm_HandSolder
R25: 15K 1%; R_1206_3216Metric_Pad1.30x1.75mm_HandSolder
TP1, TP2: TestPoint; TestPoint_Pad_4.0x4.0mm
U1: TPS61090RSAR; QFN65P400X400X100-17N
U2: MCP73871-2CCI_ML; QFN-20-1EP_4x4mm_RevA
U3: 74LVC1G07; SOT-353_SC-70-5
U4: RT9742VGJ5; SOT-23-5
U5: RT9742ENGJ5; SOT-23-5
U6, U7: TPD4EUSB30; USON-10_2.5x1.0mm_P0.5mm
U8: USB2504A-JT
U9: AP22653W6-7; SOT95P280X145-6N
Y1: 24MHz; Crystal_SMD_HC49-SD

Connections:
+3V3: C10.1, C11.1, C12.1, C13.1, C14.1, C15.2, C16.2, CM4.78 (GPIO_VREF(1.8v/3.3v_Input)), CM4.84 (+3.3v_(Output)), CM4.86 (+3.3v_(Output)), D5.2 (A), D6.2 (A), J6.L1 (GREEN_A_1), J6.L3 (GREEN_A_2), R18.2, U3.5 (VCC), U4.5 (IN), U8.1 (VDDA33), U8.7 (VDDA33), U8.13 (VDDA33), U8.28 (VDD33), U8.51 (SELF_PWR), U8.52 (VBUS_DET), U8.61 (VDDA33PLL), U8.62 (ATEST/REG_EN)
/CM4/5v: C4.1, C5.1, C7.1, CM4.77 (+5v_(Input)), CM4.79 (+5v_(Input)), CM4.81 (+5v_(Input)), CM4.83 (+5v_(Input)), CM4.85 (+5v_(Input)), CM4.87 (+5v_(Input)), J2.2, R7.1, R14.2, U1.1 (VOUT), U1.15 (VOUT), U1.16 (VOUT), U5.4 (EN), U5.5 (IN), U9.1 (IN)
/CM4/ETH_LEDG: CM4.17 (Ethernet_nLED2(3.3v)), R21.1
/CM4/ETH_LEDY: CM4.15 (Ethernet_nLED3(3.3v)), R20.1
/CM4/HDMI0_CEC: CM4.151 (HDMI0_CEC), J3.13 (CEC)
/CM4/HDMI0_CK_N: CM4.190 (HDMI0_CLK_N), J3.12 (CK-)
/CM4/HDMI0_CK_P: CM4.188 (HDMI0_CLK_P), J3.10 (CK+)
/CM4/HDMI0_D0_N: CM4.184 (HDMI0_TX0_N), J3.9 (D0-)
/CM4/HDMI0_D0_P: CM4.182 (HDMI0_TX0_P), J3.7 (D0+)
/CM4/HDMI0_D1_N: CM4.178 (HDMI0_TX1_N), J3.6 (D1-)
/CM4/HDMI0_D1_P: CM4.176 (HDMI0_TX1_P), J3.4 (D1+)
/CM4/HDMI0_D2_N: CM4.172 (HDMI0_TX2_N), J3.3 (D2-)
/CM4/HDMI0_D2_P: CM4.170 (HDMI0_TX2_P), J3.1 (D2+)
/CM4/HDMI0_HOTPLUG: CM4.153 (HDMI0_HOTPLUG), J3.19 (HPD/HEAC-)
/CM4/HDMI0_SCL: CM4.200 (HDMI0_SCL), J3.15 (SCL)
/CM4/HDMI0_SDA: CM4.199 (HDMI0_SDA), J3.16 (SDA)
/CM4/HDMI1_CEC: CM4.149 (HDMI1_CEC), J4.13
/CM4/HDMI1_CK_N: CM4.166 (HDMI1_CLK_N), J4.12
/CM4/HDMI1_CK_P: CM4.164 (HDMI1_CLK_P), J4.10
/CM4/HDMI1_D0_N: CM4.160 (HDMI1_TX0_N), J4.9
/CM4/HDMI1_D0_P: CM4.158 (HDMI1_TX0_P), J4.7
/CM4/HDMI1_D1_N: CM4.154 (HDMI1_TX1_N), J4.6
/CM4/HDMI1_D1_P: CM4.152 (HDMI1_TX1_P), J4.4
/CM4/HDMI1_D2_N: CM4.148 (HDMI1_TX2_N), J4.3
/CM4/HDMI1_D2_P: CM4.146 (HDMI1_TX2_P), J4.1
/CM4/HDMI1_HOTPLUG: CM4.143 (HDMI1_HOTPLUG), J4.19
/CM4/HDMI1_SCL: CM4.147 (HDMI1_SCL), J4.15
/CM4/HDMI1_SDA: CM4.145 (HDMI1_SDA), J4.16
/CM4/HDMI_5v: J3.18 (+5V), J4.18, U5.1 (OUT)
/CM4/SD_CLK: CM4.57 (SD_CLK), J5.5 (CLK)
/CM4/SD_CMD: CM4.62 (SD_CMD), J5.3 (CMD)
/CM4/SD_DAT0: CM4.63 (SD_DAT0), J5.7 (DAT0)
/CM4/SD_DAT1: CM4.67 (SD_DAT1), J5.8 (DAT1)
/CM4/SD_DAT2: CM4.69 (SD_DAT2), J5.1 (DAT2)
/CM4/SD_DAT3: CM4.61 (SD_DAT3), J5.2 (DAT3/CD)
/CM4/TRD0_N: CM4.12 (Ethernet_Pair0_P), J6.2 (TRD1-), U7.4 (D2+)
/CM4/TRD0_P: CM4.10 (Ethernet_Pair0_N), J6.1 (TRD1+), U7.5 (D2-)
/CM4/TRD1_N: CM4.6 (Ethernet_Pair1_N), J6.4 (TRD2-), U7.2 (D1-)
/CM4/TRD1_P: CM4.4 (Ethernet_Pair1_P), J6.3 (TRD2+), U7.1 (D1+)
/CM4/TRD2_N: CM4.11 (Ethernet_Pair2_P), J6.8 (TRD3-), U6.4 (D2+)
/CM4/TRD2_P: CM4.9 (Ethernet_Pair2_N), J6.7 (TRD3+), U6.5 (D2-)
/CM4/TRD3_N: CM4.5 (Ethernet_Pair3_N), J6.10 (TRD4-), U6.2 (D1-)
/CM4/TRD3_P: CM4.3 (Ethernet_Pair3_P), J6.9 (TRD4+), U6.1 (D1+)
/CM4/USB2_N: CM4.103 (USB2_N), U8.3 (USBDN0)
/CM4/USB2_P: CM4.105 (USB2_P), U8.2 (USBDP0)
/CM4/nEXTRST: CM4.100 (nEXTRST), U8.49 (RESET_N)
/USB/D1_N: J10.11, J10.12, U8.5 (USBDN1)
/USB/D1_P: J10.9, J10.10, U8.6 (USBDP1)
/USB/D2_N: J7.2, U8.8 (USBDP2)
/USB/D2_P: J7.3, U8.9 (USBDN2)
/USB/D3_N: J8.2, U8.11 (USBDN3)
/USB/D3_P: J8.3, U8.12 (USBDP3)
/USB/D4_N: J9.2, U8.14 (USBDP4)
/USB/D4_P: J9.3, U8.15 (USBDN4)
/USB/OCS1: U8.38 (OCS4_N), U8.40 (OCS3_N), U8.44 (OCS2_N), U8.46 (OCS1_N), U9.4 (~FAULT)
/USB/VBUS: C19.1, C20.1, C21.1, C22.1, C23.1, J7.1, J8.1, J9.1, J10.13, J10.14, J10.15, J10.16, J10.17, J10.18, J10.19, J10.20, U9.6 (OUT)
GND: B1.1, C1.1, C2.1, C3.2, C4.2, C5.2, C6.2, C7.2, C8.2, C9.2, C10.2, C11.2, C12.2, C13.2, C14.2, C17.2, C18.2, C19.2, C20.2, C21.2, C22.2, C23.2, CM4.1 (GND), CM4.2 (GND), CM4.7 (GND), CM4.8 (GND), CM4.13 (GND), CM4.14 (GND), CM4.22 (GND), CM4.23 (GND), CM4.32 (GND), CM4.33 (GND), CM4.42 (GND), CM4.43 (GND), CM4.52 (GND), CM4.53 (GND), CM4.59 (GND), CM4.60 (GND), CM4.65 (GND), CM4.66 (GND), CM4.71 (GND), CM4.74 (GND), CM4.98 (GND), CM4.107 (GND), CM4.108 (GND), CM4.113 (GND), CM4.114 (GND), CM4.119 (GND), CM4.120 (GND), CM4.125 (GND), CM4.126 (GND), CM4.131 (GND), CM4.132 (GND), CM4.137 (GND), CM4.138 (GND), CM4.144 (GND), CM4.150 (GND), CM4.155 (GND), CM4.156 (GND), CM4.161 (GND), CM4.162 (GND), CM4.167 (GND), CM4.168 (GND), CM4.173 (GND), CM4.174 (GND), CM4.179 (GND), CM4.180 (GND), CM4.185 (GND), CM4.186 (GND), CM4.191 (GND), CM4.192 (GND), CM4.197 (GND), CM4.198 (GND), D1.1 (K), D2.2 (A), J1.A12 (GND), J1.B12 (GND), J2.1, J3.2 (D2S), J3.5 (D1S), J3.8 (D0S), J3.11 (CKS), J3.17 (GND), J3.S1 (SHIELD), J3.S2 (SHIELD), J3.S3 (SHIELD), J3.S4 (SHIELD), J4.2, J4.5, J4.8, J4.11, J4.17, J4.S1 (SHIELD), J4.S2 (SHIELD), J5.6 (VSS), J5.11 (SHIELD), J6.MH1, J6.MH2, J7.4, J8.4, J9.4, J10.1, J10.2, J10.3, J10.4, J10.5, J10.6, J10.7, J10.8, J10.S1 (SHIELD), J10.S2 (SHIELD), R2.2, R3.1, R4.1, R8.2, R9.2, R10.2, R11.2, R12.2, R22.2, R23.2, R24.2, R25.2, TP1.1, TP2.1, U1.5 (PGND), U1.6 (PGND), U1.7 (PGND), U1.10 (SYNC), U1.13 (GND), U1.17 (EXT_PAD), U2.10 (VSS), U2.11 (VSS), U2.21 (EP), U3.3 (GND), U4.2 (GND), U5.2 (GND), U6.3 (GND), U6.8 (GND), U7.3 (GND), U7.8 (GND), U8.4 (VSS), U8.10 (VSS), U8.16 (VSS), U8.23 (PRTPWR_POL), U8.29 (VSS), U8.41 (VSS), U8.53 (VSS), U8.55 (VSS), U8.64 (VSS), U9.2 (GND)
unnamed: B1.2, C6.1, U2.14 (VBAT), U2.15 (VBAT), U2.16 (VBAT_SENSE)
unnamed: C8.1, J5.4 (VDD), U4.1 (OUT)
unnamed: C9.1, J6.5 (TRCT1), J6.6 (TRCT2)
unnamed: C15.1, U8.60 (VDDA18PLL)
unnamed: C16.1, U8.54 (VDD18)
unnamed: C17.1, U8.57 (XTAL2), Y1.1
unnamed: C18.1, U8.58 (XTAL1/CLKIN), Y1.2
unnamed: D1.2 (A), R6.2
unnamed: D2.1 (K), R14.1
unnamed: D3.1 (K), R15.1
unnamed: D4.1 (K), R16.1
unnamed: D5.1 (K), R17.2
unnamed: D6.1 (K), R19.2
unnamed: J1.A5 (CC1), R4.2
unnamed: J1.B5 (CC2), R3.2
unnamed: J1.S1 (SHIELD), J1.S2 (SHIELD), J1.S3 (SHIELD), J1.S4 (SHIELD)
unnamed: J6.L2 (YELLOW_K_1), R21.2
unnamed: J6.L4 (YELLOW_K_2), R20.2
unnamed: L1.2, U1.3 (SW), U1.4 (SW)
unnamed: CM4.21 (PI_nLED_Activity), R17.1
unnamed: CM4.75 (SD_PWR_ON), R18.1, U4.4 (EN)
unnamed: CM4.95 (nPI_LED_PWR), U3.2
unnamed: Q1.1 (B), U1.12 (LBO)
unnamed: Q1.3 (C), R6.1
unnamed: R1.2, R2.1, U1.9 (LBI)
unnamed: R5.1, U1.11 (EN)
unnamed: R7.2, R8.1, U1.14 (FB)
unnamed: R10.1, U2.5 (THERM)
unnamed: R11.1, U2.12 (PROG3)
unnamed: R12.1, U2.13 (PROG1)
unnamed: R9.1, R13.1, U2.2 (VPCC)
unnamed: R15.2, U2.7 (STAT2)
unnamed: R16.2, U2.8 (STAT1/~LBO)
unnamed: R19.1, U3.4
unnamed: R22.1, U8.34 (SDA/SMBDATA)
unnamed: R23.1, U8.35 (SCL/SMBCLK)
unnamed: R24.1, U8.63 (RBIAS)
unnamed: R25.1, U9.5 (ILIM)
unnamed: U8.45 (PRTPWR1), U9.3 (EN)
VBAT: C1.2, C2.2, L1.1, Q1.2 (E), R1.1, R5.2, U1.8 (VBAT), U2.1 (OUT), U2.20 (OUT)
VBUS: C3.1, D3.2 (A), D4.2 (A), J1.A9 (VBUS), J1.B9 (VBUS), R13.2, U2.3 (SEL), U2.4 (PROG2), U2.9 (~TE), U2.17 (CE), U2.18 (IN), U2.19 (IN)

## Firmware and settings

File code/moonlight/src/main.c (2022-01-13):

/*
 * This file is part of Moonlight Embedded.
 *
 * Copyright (C) 2015-2019 Iwan Timmer
 *
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
 * You should have received a copy of the GNU General Public License
 * along with Moonlight; if not, see <http://www.gnu.org/licenses/>.
 */

#include "loop.h"
#include "connection.h"
#include "configuration.h"
#include "config.h"
#include "platform.h"
#include "sdl.h"

#include "audio/audio.h"
#include "video/video.h"

#include "input/mapping.h"
#include "input/evdev.h"
#include "input/udev.h"
#ifdef HAVE_LIBCEC
#include "input/cec.h"
#endif
#ifdef HAVE_SDL
#include "input/sdl.h"
#endif

#include <Limelight.h>

#include <client.h>
#include <discover.h>

#include <stdio.h>
#include <stdlib.h>
#include <stdbool.h>
#include <string.h>
#include <unistd.h>
#include <sys/types.h>
#include <sys/socket.h>
#include <netinet/in.h>
#include <netdb.h>
#include <arpa/inet.h>
#include <openssl/rand.h>

static void applist(PSERVER_DATA server) {
  PAPP_LIST list = NULL;
  if (gs_applist(server, &list) != GS_OK) {
    fprintf(stderr, "Can't get app list\n");
    return;
  }

  for (int i = 1;list != NULL;i++) {
    printf("%d. %s\n", i, list->name);
    list = list->next;
  }
}

static int get_app_id(PSERVER_DATA server, const char *name) {
  PAPP_LIST list = NULL;
  if (gs_applist(server, &list) != GS_OK) {
    fprintf(stderr, "Can't get app list\n");
    return -1;
  }

  while (list != NULL) {
    if (strcmp(list->name, name) == 0)
      return list->id;

    list = list->next;
  }
  return -1;
}

static void stream(PSERVER_DATA server, PCONFIGURATION config, enum platform system) {
  int appId = get_app_id(server, config->app);
  if (appId<0) {
    fprintf(stderr, "Can't find app %s\n", config->app);
    exit(-1);
  }

  int gamepads = 0;
  gamepads += evdev_gamepads;
  #ifdef HAVE_SDL
  gamepads += sdl_gamepads;
  #endif
  int gamepad_mask = 0;
  for (int i = 0; i < gamepads && i < 4; i++)
    gamepad_mask = (gamepad_mask << 1) + 1;

  int ret = gs_start_app(server, &config->stream, appId, config->sops, config->localaudio, gamepad_mask);
  if (ret < 0) {
    if (ret == GS_NOT_SUPPORTED_4K)
      fprintf(stderr, "Server doesn't support 4K\n");
    else if (ret == GS_NOT_SUPPORTED_MODE)
      fprintf(stderr, "Server doesn't support %dx%d (%d fps) or remove --nounsupported option\n", config->stream.width, config->stream.height, config->stream.fps);
    else if (ret == GS_NOT_SUPPORTED_SOPS_RESOLUTION)
      fprintf(stderr, "Optimal Playable Settings isn't supported for the resolution %dx%d, use supported resolution or add --nosops option\n", config->stream.width, config->stream.height);
    else if (ret == GS_ERROR)
      fprintf(stderr, "Gamestream error: %s\n", gs_error);
    else
      fprintf(stderr, "Errorcode starting app: %d\n", ret);
    exit(-1);
  }

  int drFlags = 0;
  if (config->fullscreen)
    drFlags |= DISPLAY_FULLSCREEN;

  switch (config->rotate) {
  case 90:
    drFlags |= DISPLAY_ROTATE_90;
    break;
  case 180:
    drFlags |= DISPLAY_ROTATE_180;
    break;
  case 270:
    drFlags |= DISPLAY_ROTATE_270;
    break;
  }

  if (config->debug_level > 0) {
    printf("Stream %d x %d, %d fps, %d kbps\n", config->stream.width, config->stream.height, config->stream.fps, config->stream.bitrate);
    connection_debug = true;
  }

  if (IS_EMBEDDED(system))
    loop_init();

  platform_start(system);
  LiStartConnection(&server->serverInfo, &config->stream, &connection_callbacks, platform_get_video(system), platform_get_audio(system, config->audio_device), NULL, drFlags, config->audio_device, 0);

  if (IS_EMBEDDED(system)) {
    if (!config->viewonly)
      evdev_start();
    loop_main();
    if (!config->viewonly)
      evdev_stop();
  }
  #ifdef HAVE_SDL
  else if (system == SDL)
    sdl_loop();
  #endif

  LiStopConnection();

  if (config->quitappafter) {
    if (config->debug_level > 0)
      printf("Sending app quit request ...\n");
    gs_quit_app(server);
  }

  platform_stop(system);
}

static void help() {
  #ifdef GIT_BRANCH
  printf("Moonlight Embedded %d.%d.%d-%s-%s\n", VERSION_MAJOR, VERSION_MINOR, VERSION_PATCH, GIT_BRANCH, GIT_COMMIT_HASH);
  #else
  printf("Moonlight Embedded %d.%d.%d\n", VERSION_MAJOR, VERSION_MINOR, VERSION_PATCH);
  #endif
  printf("Usage: moonlight [action] (options) [host]\n");
  printf("       moonlight [configfile]\n");
  printf("\n Actions\n\n");
  printf("\tpair\t\t\tPair device with computer\n");
  printf("\tunpair\t\t\tUnpair device with computer\n");
  printf("\tstream\t\t\tStream computer to device\n");
  printf("\tlist\t\t\tList available games and applications\n");
  printf("\tquit\t\t\tQuit the application or game being streamed\n");
  printf("\tmap\t\t\tCreate mapping for gamepad\n");
  printf("\thelp\t\t\tShow this help\n");
  printf("\n Global Options\n\n");
  printf("\t-config <config>\tLoad configuration file\n");
  printf("\t-save <config>\t\tSave configuration file\n");
  printf("\t-verbose\t\tEnable verbose output\n");
  printf("\t-debug\t\t\tEnable verbose and debug output\n");
  printf("\n Streaming options\n\n");
  printf("\t-720\t\t\tUse 1280x720 resolution [default]\n");
  printf("\t-1080\t\t\tUse 1920x1080 resolution\n");
  printf("\t-4k\t\t\tUse 3840x2160 resolution\n");
  printf("\t-width <width>\t\tHorizontal resolution (default 1280)\n");
  printf("\t-height <height>\tVertical resolution (default 720)\n");
  #if defined(HAVE_PI) | defined(HAVE_MMAL)
  printf("\t-rotate <height>\tRotate display: 0/90/180/270 (default 0)\n");
  #endif
  printf("\t-fps <fps>\t\tSpecify the fps to use (default 60)\n");
  printf("\t-bitrate <bitrate>\tSpecify the bitrate in Kbps\n");
  printf("\t-packetsize <size>\tSpecify the maximum packetsize in bytes\n");
  printf("\t-codec <codec>\t\tSelect used codec: auto/h264/h265 (default auto)\n");
  printf("\t-remote <yes/no/auto>\t\t\tEnable optimizations for WAN streaming (default auto)\n");
  printf("\t-app <app>\t\tName of app to stream\n");
  printf("\t-nosops\t\t\tDon't allow GFE to modify game settings\n");
  printf("\t-localaudio\t\tPlay audio locally on the host computer\n");
  printf("\t-surround <5.1/7.1>\t\tStream 5.1 or 7.1 surround sound\n");
  printf("\t-keydir <directory>\tLoad encryption keys from directory\n");
  printf("\t-mapping <file>\t\tUse <file> as gamepad mappings configuration file\n");
  printf("\t-platform <system>\tSpecify system used for audio, video and input: pi/imx/aml/rk/x11/x11_vdpau/sdl/fake (default auto)\n");
  printf("\t-nounsupported\t\tDon't stream if resolution is not officially supported by the server\n");
  printf("\t-quitappafter\t\tSend quit app request to remote after quitting session\n");
  printf("\t-viewonly\t\tDisable all input processing (view-only mode)\n");
  printf("\t-nomouseemulation\t\tDisable gamepad mouse emulation support (long pressing Start button)\n");
  #if defined(HAVE_SDL) || defined(HAVE_X11)
  printf("\n WM options (SDL and X11 only)\n\n");
  printf("\t-windowed\t\tDisplay screen in a window\n");
  #endif
  #ifdef HAVE_EMBEDDED
  printf("\n I/O options (Not for SDL)\n\n");
  printf("\t-input <device>\t\tUse <device> as input. Can be used multiple times\n");
  printf("\t-audio <device>\t\tUse <device> as audio output device\n");
  #endif
  printf("\nUse Ctrl+Alt+Shift+Q or Play+Back+LeftShoulder+RightShoulder to exit streaming session\n\n");
  exit(0);
}

static void pair_check(PSERVER_DATA server) {
  if (!server->paired) {
    fprintf(stderr, "You must pair with the PC first\n");
    exit(-1);
  }
}

int main(int argc, char* argv[]) {
  CONFIGURATION config;
  config_parse(argc, argv, &config);

  if (config.action == NULL || strcmp("help", config.action) == 0)
    help();

  if (config.debug_level > 0)
    printf("Moonlight Embedded %d.%d.%d (%s)\n", VERSION_MAJOR, VERSION_MINOR, VERSION_PATCH, COMPILE_OPTIONS);

  if (strcmp("map", config.action) == 0) {
    if (config.inputsCount != 1) {
      printf("You need to specify one input device using -input.\n");
      exit(-1);
    }

    evdev_create(config.inputs[0], NULL, config.debug_level > 0, config.rotate);
    evdev_map(config.inputs[0]);
    exit(0);
  }

  if (config.address == NULL) {
    config.address = malloc(MAX_ADDRESS_SIZE);
    if (config.address == NULL) {
      perror("Not enough memory");
      exit(-1);
    }
    config.address[0] = 0;
    printf("Searching for server...\n");
    gs_discover_server(config.address);
    if (config.address[0] == 0) {
      fprintf(stderr, "Autodiscovery failed. Specify an IP address next time.\n");
      exit(-1);
    }
  }

  char host_config_file[128];
  sprintf(host_config_file, "hosts/%s.conf", config.address);
  if (access(host_config_file, R_OK) != -1)
    config_file_parse(host_config_file, &config);

  SERVER_DATA server;
  printf("Connect to %s...\n", config.address);

  int ret;
  if ((ret = gs_init(&server, config.address, config.key_dir, config.debug_level, config.unsupported)) == GS_OUT_OF_MEMORY) {
    fprintf(stderr, "Not enough memory\n");
    exit(-1);
  } else if (ret == GS_ERROR) {
    fprintf(stderr, "Gamestream error: %s\n", gs_error);
    exit(-1);
  } else if (ret == GS_INVALID) {
    fprintf(stderr, "Invalid data received from server: %s\n", gs_error);
    exit(-1);
  } else if (ret == GS_UNSUPPORTED_VERSION) {
    fprintf(stderr, "Unsupported version: %s\n", gs_error);
    exit(-1);
  } else if (ret != GS_OK) {
    fprintf(stderr, "Can't connect to server %s\n", config.address);
    exit(-1);
  }

  if (config.debug_level > 0)
    printf("GPU: %s, GFE: %s (%s, %s)\n", server.gpuType, server.serverInfo.serverInfoGfeVersion, server.gsVersion, server.serverInfo.serverInfoAppVersion);

  if (strcmp("list", config.action) == 0) {
    pair_check(&server);
    applist(&server);
  } else if (strcmp("stream", config.action) == 0) {
    pair_check(&server);
    enum platform system = platform_check(config.platform);
    if (config.debug_level > 0)
      printf("Platform %s\n", platform_name(system));

    if (system == 0) {
      fprintf(stderr, "Platform '%s' not found\n", config.platform);
      exit(-1);
    } else if (system == SDL && config.audio_device != NULL) {
      fprintf(stderr, "You can't select a audio device for SDL\n");
      exit(-1);
    }
    config.stream.supportsHevc = config.codec != CODEC_H264 && (config.codec == CODEC_HEVC || platform_supports_hevc(system));

    #ifdef HAVE_SDL
    if (system == SDL)
      sdl_init(config.stream.width, config.stream.height, config.fullscreen);
    #endif

    if (config.viewonly) {
      if (config.debug_level > 0)
        printf("View-only mode enabled, no input will be sent to the host computer\n");
    } else {
      if (IS_EMBEDDED(system)) {
        char* mapping_env = getenv("SDL_GAMECONTROLLERCONFIG");
        if (config.mapping == NULL && mapping_env == NULL) {
          fprintf(stderr, "Please specify mapping file as default mapping could not be found.\n");
          exit(-1);
        }

        struct mapping* mappings = NULL;
        if (config.mapping != NULL)
          mappings = mapping_load(config.mapping, config.debug_level > 0);

        if (mapping_env != NULL) {
          struct mapping* map = mapping_parse(mapping_env);
          map->next = mappings;
          mappings = map;
        }

        for (int i=0;i<config.inputsCount;i++) {
          if (config.debug_level > 0)
            printf("Add input %s...\n", config.inputs[i]);

          evdev_create(config.inputs[i], mappings, config.debug_level > 0, config.rotate);
        }

        udev_init(!inputAdded, mappings, config.debug_level > 0, config.rotate);
        evdev_init(config.mouse_emulation);
        rumble_handler = evdev_rumble;
        #ifdef HAVE_LIBCEC
        cec_init();
        #endif /* HAVE_LIBCEC */
      }
      #ifdef HAVE_SDL
      else if (system == SDL) {
        if (config.inputsCount > 0) {
          fprintf(stderr, "You can't select input devices as SDL will automatically use all available controllers\n");
          exit(-1);
        }

        sdlinput_init(config.mapping);
        rumble_handler = sdlinput_rumble;
      }
      #endif
    }

    stream(&server, &config, system);
  } else if (strcmp("pair", config.action) == 0) {
    char pin[5];
    sprintf(pin, "%d%d%d%d", (int)random() % 10, (int)random() % 10, (int)random() % 10, (int)random() % 10);
    printf("Please enter the following PIN on the target PC: %s\n", pin);
    fflush(stdout);
    if (gs_pair(&server, &pin[0]) != GS_OK) {
      fprintf(stderr, "Failed to pair to server: %s\n", gs_error);
    } else {
      printf("Succesfully paired\n");
    }
  } else if (strcmp("unpair", config.action) == 0) {
    if (gs_unpair(&server) != GS_OK) {
      fprintf(stderr, "Failed to unpair to server: %s\n", gs_error);
    } else {
      printf("Succesfully unpaired\n");
    }
  } else if (strcmp("quit", config.action) == 0) {
    pair_check(&server);
    gs_quit_app(&server);
  } else
    fprintf(stderr, "%s is not a valid action\n", config.action);
}

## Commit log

2021-05-25 Start working on the preliminary bill of materials
    All funding needs to be preapproved, even though the funds are distributed through reimbursement. This means even though nothing has been purchased, and I will have to purchase everything on my own, 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
    [billOfMaterials.xlsx]
2021-05-26 Set up KiCAD
    Initializes the project and load Digi-Key libraries
    [customBoard.kicad_pcb, customBoard.kicad_sch]
2021-06-01 Rework BOM for power supply
    Instead of basing the power supply off of the Aegis project, I'm instead looking at Adafruit's Powerboost 1000C and trying to build something similar to that
    [billOfMaterials.xlsx]
2021-06-04 Continue working on BOM for primary board systems
    Next up is things like the peripherals and other purchases
    [billOfMaterials.xlsx]
2021-06-07 Finish initial draft of pcb BOM
    Because I don't have much experience with PCB making, I've been trying to estimate what I'll need for this project to work so I can submit the funding application for pre-approval. Since everything has to be pre-approved, I need to have a general idea of what I want even though I don't have the experience needed to know what I want, and to see a couple steps down the line for potential issues.
    So what I've done is compiled a potential list, and once funding is approved I will order the basic materials like the io board so I can get my hands on the cm4 and then redesign probably redesign everything then.
    Note this isn't the final BOM that will be submitted be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
    [billOfMaterials.xlsx]
2021-06-07 Enter in quantities for BOM
    [billOfMaterials.xlsx]
2021-06-07 Update prospectus to include PCB plan
2021-06-09 Tweak BOM and export as PDF
    Since the funding application doesn't accept excel sheets, the main sheet has been saved as a pdf for ease of uploading. I think everything is ready to submit as soon as the application opens
    [billOfMaterials.xlsx]
2021-08-30 First draft of the power circuit
    While this is my first time developing any kind of PCB, this circuit is pretty similar to an existing schematic, so it should be pretty solid.
    [customBoard.kicad_sch, power.kicad_sch]
2021-09-09 First draft of CM4_GPIO
    The CM4 connectors are split into two units. This is the right unit, name GPIO. Next is the left, High Speed Serial unit.
    [cm4.kicad_sch, customBoard.kicad_sch, power.kicad_sch]
2021-09-23 Add receipt from Walmart
    Both the CM4IO and the Pinecil use a 12V barrel jack for power
2021-09-25 Draft CM4 High Speed Serial
    One interesting dilemma that has come up is how to handle replacements for the RT9742 part. Since the ones I was originally going to use are out of stock, an exciting hunt occurred to find a replacement that will not break anything. After some meetings and some investigation, I believe some good replacements have been found. For future reference, the documentation has been included in the notes folder
    [cm4.kicad_sch, customBoard.kicad_sch]
2021-10-02 First draft of USB
    This should complete the first draft of the schematic!
    Now time to design the PCB itself
    [cm4.kicad_sch, customBoard.kicad_sch, usb.kicad_sch]
2021-10-04 Generate Netlist
    [cm4.kicad_sch, customBoard.kicad_sch, power.kicad_sch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]
2021-10-10 First Draft of Power PCB
    [customBoard.kicad_pcb, customBoard.kicad_sch, usb.kicad_sch]
2021-10-11 Rework Power PCB and draft SD
    Moving things around so they would make sense on the final board. Flipped around some of the power circuit so the battery can be plugged in on the left side to make room for all the ports on the right.
    [cm4.kicad_sch, customBoard.kicad_pcb, customBoard.kicad_sch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]
2021-10-11 Save progress on USB
    [cm4.kicad_sch, customBoard.kicad_pcb, customBoard.kicad_sch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]
2021-10-12 Draft HDMI and more differential pairs
    [cm4.kicad_sch, customBoard.kicad_pcb, customBoard.kicad_sch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]
2021-10-12 Draft before fixing errors
    [customBoard.kicad_pcb, customBoard.kicad_sch, usb.kicad_sch]
2021-10-12 Fix errors with draft
    Now I need to run it by a bunch of people, but from my point of view, I don't know what else to do before the fabrication step
    [customBoard.kicad_pcb]
2021-10-22 Updates based on meeting with Dr. Jordan
    Everything should be good to go now, next up is generating a bill of materials (making sure everything is in stock), and generating gerbers
    [cm4.kicad_sch, customBoard.kicad_pcb, customBoard.kicad_sch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]
2021-10-24 Generate BOM
    Clean up all the part data and add manufacturer's numbers for ordering
    [cm4.kicad_sch, customBoard.csv, customBoard.kicad_pcb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]
2021-10-24 Generate Gerbers
    Off to JLCPCB!
    [customBoard-B_Mask.gbr, customBoard-B_Silkscreen.gbr, customBoard-Back.gbr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]
2021-10-24 Add receipts for ordering first draft of PCB
    Unfortunately Digi-key hasn't provided a receipt yet, so hopefully that'll come soon. Also doesn't include order from heisener since I need to wait for a quote
2021-11-04 Initialize code directory
    Create folders for the forked moonlight code, the arm image profile data, and scripts to automate everything. Everything is subject to change since technically a lot of this can only be run on a manj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
2021-11-10 Create build toolchain Automate the steps to build, package, and create the installable image
    [config.txt]
2021-12-31 Update config.txt for new screen
    [config.txt]
2022-01-09 Create Web portion of the data logger
    The simple page will just switch colors every time a key is pressed in a way that is super easy to see from the client and server side
2022-01-19 Add additional info to datalogger
    [datalogger_linux.csv, datalogger_windows.csv]
2022-01-19 Record keys and colors seperately
    [datalogger_colors_linux.csv, datalogger_colors_windows.csv, datalogger_keys_linux.csv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]
2022-01-19 Record first points of data
    All of this is subject to change as I don't really know the best way to do this. What I've record so far is the input delay for the moonlight application determined by the delay in keystrokes and col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
    [moonlight_color_delay.csv, moonlight_key_delay.csv]
2022-01-26 Record data under ideal conditions
    Next up is to record while the GPU is under full load
    [crd_color_delay.csv, crd_key_delay.csv, datalogger_colors_windows.csv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]
2022-01-26 Record GPU-stressed data
    [crd_color_delay.csv, crd_key_delay.csv, moonlight_color_delay.csv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]
2022-01-26 Record CPU-stressed data
    [crd_color_delay.csv, crd_key_delay.csv, moonlight_color_delay.csv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]
2022-01-31 Version 2 of board
    Fix U2 to use the footprint "QFN-20-1EP_4x4mm_RevA" instead of "QFN-20-1EP_4x4mm"
    Rotate J5 by 180 degrees
    Slight aesthetic tweaks
    [customBoard.kicad_pcb]
2022-01-31 Rename KiCAD project
    [cm4.kicad_sch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]
2022-01-31 Generate v2 gerbers and BOM
    [lathrum_thesis-B_Mask.gbr, lathrum_thesis-B_Silkscreen.gbr, lathrum_thesis-Back.gbr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]
2022-02-26 Add receipts from jlcpcb and amazon for v2 board
2022-03-22 Appendix A and B
    [lathrum_thesis_bom.csv]
2022-03-24 Fix feedback issues and start Design PCB section
2022-03-25 Designing the power, usb, hdmi and start cm4 circuits
2022-03-30 (almost) finish draft of hardware section
    Still need to investigate the USB issues and maybe add more detail to the end of the chapter, but other than that I have a couple of questions to resolve then I'm happyish with the chapter
2022-03-31 Fixes from feedback, add images of physical board
2022-04-01 Start developing for ARM section
2022-04-03 Start Evaluation section, add graphs
    [crd_color_delay.csv, rdp_key_delay.csv, vnc_color_delay.csv]
2022-04-08 Fix footprint image being incorrect
    haha they were so similar I even mixed them up here
2022-04-24 Record new data and update evaluation chapter
    [crd_color_delay.csv, crd_key_delay.csv, moonlight_color_delay.csv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]
2022-04-26 Switch back to two sided for printing
    The thesis has been submitted!

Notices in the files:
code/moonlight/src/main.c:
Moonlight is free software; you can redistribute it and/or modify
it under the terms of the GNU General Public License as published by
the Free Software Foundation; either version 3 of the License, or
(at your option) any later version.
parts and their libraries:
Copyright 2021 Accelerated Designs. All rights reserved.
